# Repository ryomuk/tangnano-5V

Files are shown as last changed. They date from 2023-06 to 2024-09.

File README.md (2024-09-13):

# tangnano-5V
5V tolerant interface for Tang Nano 20K and 9K

This document is written mostly in Japanese. If necessary, please use a translation service such as DeepL (I recommend this) or Google.

# 概要
Tang Nanoを5V系の回路に接続するためのインターフェースです．昔のCPU用のメモリシステムやI/OをTang Nanoに実装することを主目的に作成しました。
Tang Nano 20K用と9K用の2種類があります．(私は主に20K用を使用しており，9K用はクセがあるのであまり使用実績が無いです．)

# Tang Nano 20K 版(rev.1.1a)
## 機能
- Tang Nanoの20KのGPIO(全34本)を，SN74CB3T3245(レベルシフタ搭載バススイッチ)を介して5V系(TTL, CMOS)に接続します．
- バッファではなくスイッチで行なっているため，特に信号方向を意識することなく双方向接続が可能，信号の伝達遅延は0.25ns以下です．

## 原理
- 5V→3.3VはSN74CB3T3245によって5V系から3.3V系にレベル変換されます．
- 3.3V→5Vはレベル変換は行なわれず，3.3V系の信号が出力されますが，5VTTLの閾値は1.5V，5VCMOSの閾値は2.5Vなので問題無いということのようです．

## 動作の確認状況
- 27MHzのシステムクロックが全GPIOで5V系に出力できることを確認しました．(75番ピンについては下記参照)
- 5V系→3.3V系: 5Vの入力信号に対し，出力が3.3Vになることを確認しました．
- 3.3V系→5V系: 3.3Vの入力信号に対し，出力が3.3Vになることを確認しました．
- データシートによると遅延はmax 0.25nsで，手元のオシロでは測定限界以下でした．

## Tang Nano 20Kの75番ピンについて
- Tang Nano 20K(v3921)の75番ピンは，C51(100nF)でGNDに接続されているため，そのままだと低速(数十KHz)でしか動作しません．他のピンと同様に使用するためにはC51を外す必要があります．低速動作で構わないのであれば気にしなくていいです．
- 最新の回路図v3921(Date:2023-07-11, ファイルの日付2023-11-08)ではC51がNCになっているようです。2024年3月に購入したものがC51未実装だったという情報がありました。(2024/4/15)
- R22(10K)でGNDにプルダウンされているので、外部でプルアップすると誤動作の原因になります。

### 75番ピン以外に関するメモ
TangNano20K、pin75以外にも若干癖のあるpinがあるのでメモしておきます。
- pin15～20は510RでLEDに継がっていて入力に使うとIIL=約3.0mA。
- pin52～53は2.2Kで5VとFETに継がっててIIL=約4.4mA。
- pin26は5.1KでGND、IIH=0.6mA。
- その他のほとんどのピンはだいたいIIL=0.9mA程度、IIH=0.1mA以下。

## BOM
|Reference |Qty| Value |Size |Memo |
|---|---|---|-----|-----|
|C1, C2, C3, C4, C5 |5	|0.1uF	 |1608(mm)(0603(inch))| |
|J1, J2	 |2	|pin socket |1x20 |for Tang Nano 20K|
|J3, J4 |2	|pin header |1x20 |for 5V GPIO|
|U1, U2, U3, U4, U5 |5	|SN74CB3T3245PW  |TSSOP| |

## 画像
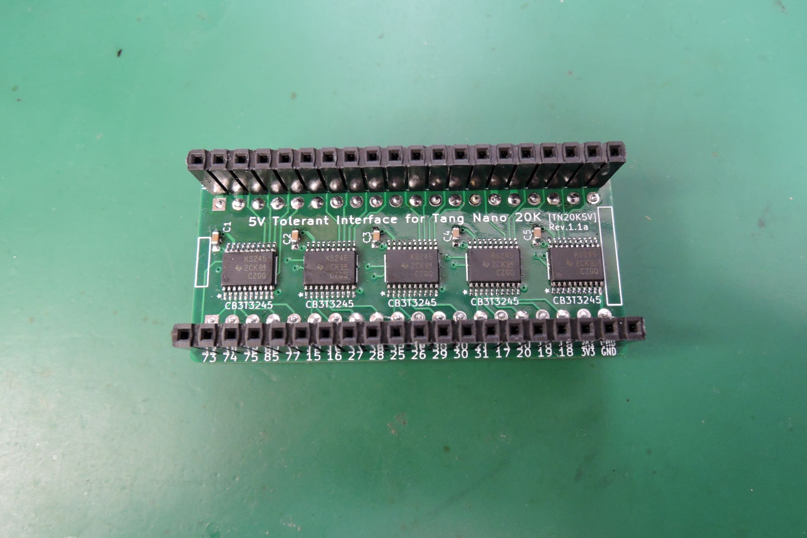
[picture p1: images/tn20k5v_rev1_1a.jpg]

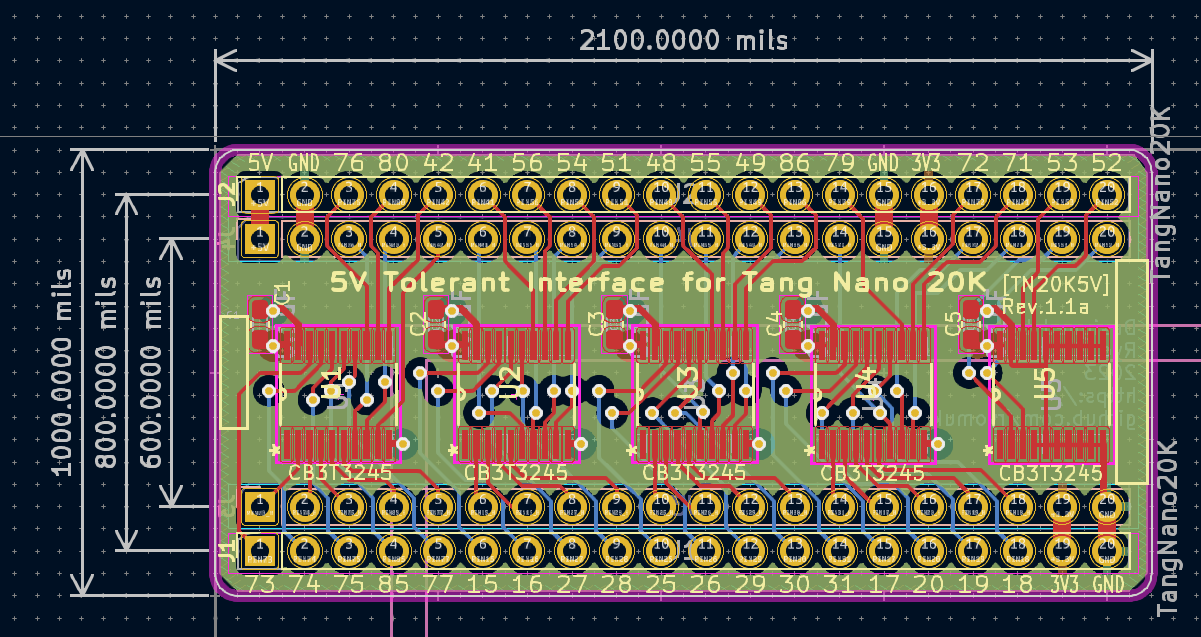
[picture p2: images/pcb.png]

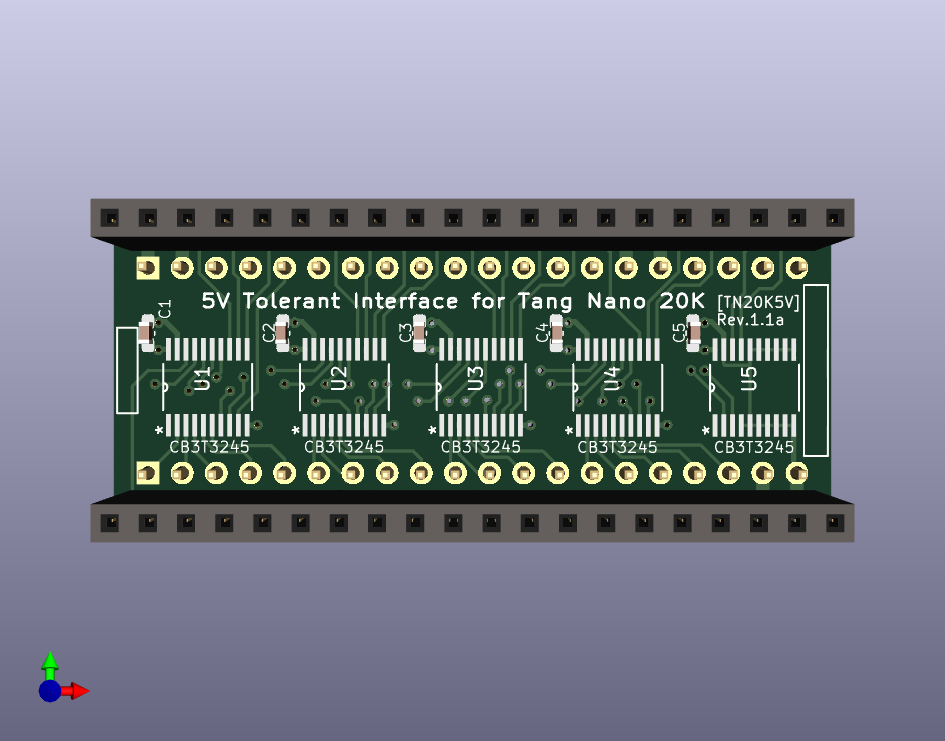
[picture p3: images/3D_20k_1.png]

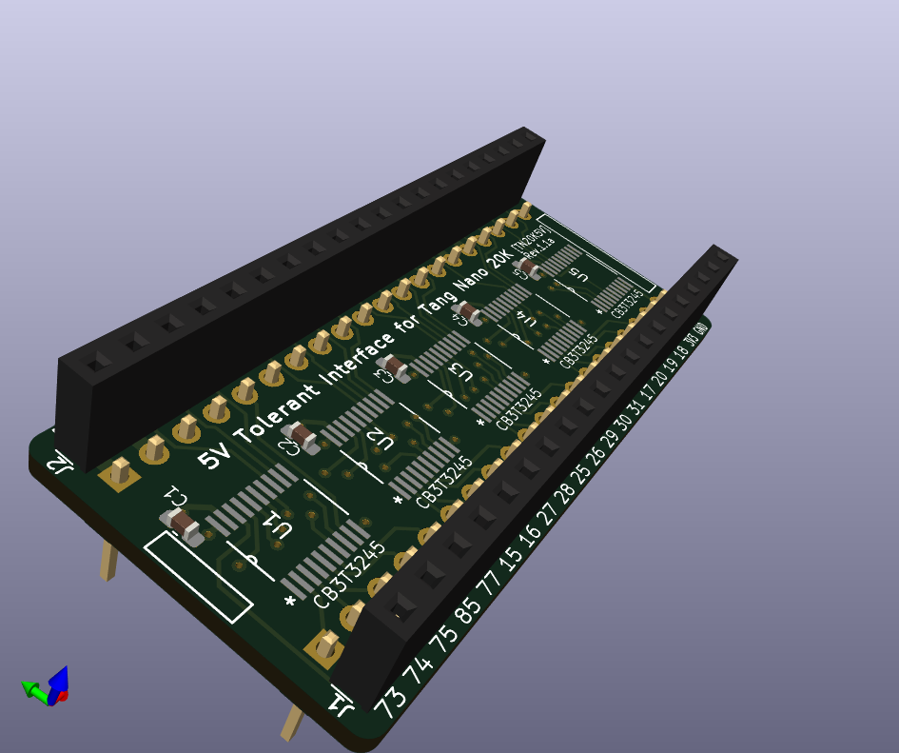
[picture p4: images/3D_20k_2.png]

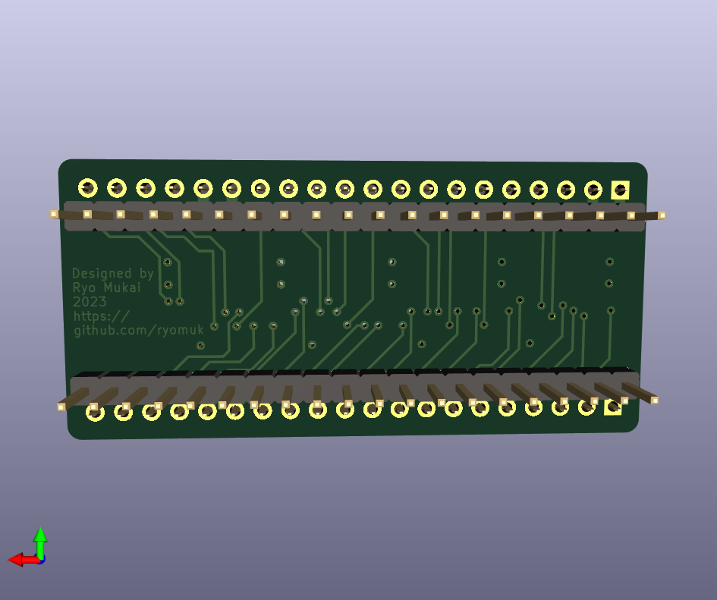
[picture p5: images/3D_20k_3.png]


# 応用例
- いろいろなCPUのメモリシステム，UARTを構築した応用例です．CPUをFPGAでエミュレートするのではなく、本物のCPUを動かすことを目的にしています。
- 勉強のために作った習作なのでかなり荒削りでいろいろと不備やバグがあると思いますがご容赦下さい。
- 各CPUで共通に使用しているUARTモジュールは適当に作ったために時々不具合が見つかってバグ修正しています．旧版との互換性は確認していないので，CPUによっては旧版のままになっています．最新版は別フォルダ [applications/uart/](applications/uart/) に置いてありますので，必要であればコピーしてご使用下さい．
- ターミナルソフトの通信遅延はCPUの速度や通信速度にあわせて適宜設定して下さい。(例: 10ms/文字, 100ms/行)

## TangNanoZ80MEM [applications/TangNanoZ80MEM](applications/TangNanoZ80MEM)
- Z80用のメモリシステムとクロック，UARTです．
- 関連ブログ [Z80をオーバークロックしてみる](https://blog.goo.ne.jp/tk-80/e/6de3708450bac79c2c1cef7728d0c877)
  
## TangNanoZ80MEM-CPM [applications/TangNanoZ80MEM-CPM](applications/TangNanoZ80MEM-CPM)
- TangNanoZ80MEMにfloppy/hard diskエミュレータを追加してCP/Mを動作させる試みです．

## TangNano6809MEM [applications/TangNano6809MEM](applications/TangNano6809MEM)
- MC6809用のメモリシステムとクロック，UARTです．
- [電脳伝説さんのSBC6809](https://vintagechips.wordpress.com/2017/12/05/sbc6809%E3%83%AB%E3%83%BC%E3%82%BA%E3%82%AD%E3%83%83%E3%83%88/)のdatapackに入っているBASIC9がバイナリそのままで動きます．

## TangNano8070MEM [applications/TangNano8070MEM](applications/TangNano8070MEM)
- INS8070N(SC/MP III)用のメモリシステム，クロック，UARTです．
- [ElectrelicさんのUniversal Monitor](https://electrelic.com/electrelic/node/1317)が，UARTのハンドシェイク部分を微修正して動きました．

## TangNano8008MEM [applications/TangNano8008MEM](applications/TangNano8008MEM)
- Intel 8008用のメモリシステム，クロック，UARTです．
- [SCELBAL (SCELBI Basic)](https://www.willegal.net/scelbi/scelbal.html)が動きました．
- [VTL-4004](https://github.com/ryomuk/VTL4004)を8008用に書き直したVTL-8008が動きました

## TangNano8080MEM [applications/TangNano8080MEM](applications/TangNano8080MEM)
- Intel 8080用メモリシステム，クロック，UART，diskエミュレータです．
- Z80MEM-CPMと同じdiskイメージを使用してCP/Mが起動します．

## TangNanoDCJ11MEM [ryomuk/TangNanoDCJ11MEM](https://github.com/ryomuk/TangNanoDCJ11MEM)
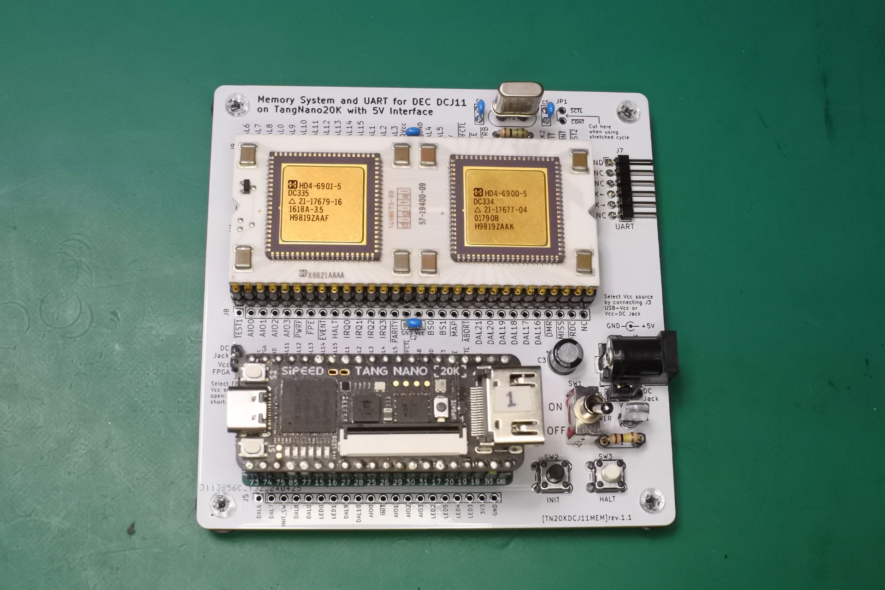
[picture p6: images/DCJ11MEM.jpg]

- DEC DCJ11 (PDP-11の命令セットを持つCPU)のメモリシステムとUARTです。
- 詳細は別リポジトリ[TangNanoDCJ11MEM](https://github.com/ryomuk/TangNanoDCJ11MEM) にあります。

# Tang Nano 9K 版(rev.3.0)[hardware/9k](hardware/9k)
- Tang Nanoの9K用のインターフェースです．あまりメンテナナスされていません．
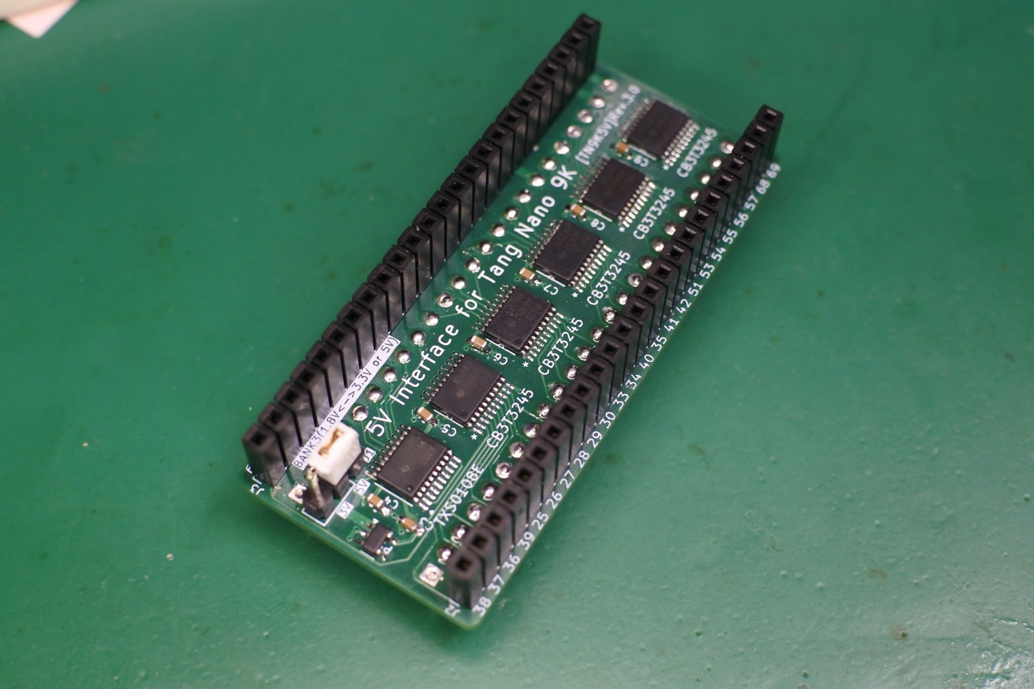
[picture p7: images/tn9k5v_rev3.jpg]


# その他
## UARTモジュールについて [applications/uart/](applications/uart/)
- 各応用例の通信部分はSipeedのサンプル( https://github.com/sipeed/TangNano-20K-example )をベースにして独自に書き替えたものを使っています．CPU速度と通信速度によっては不安定だったりすることがあり，時々書き直してます．旧版との互換性を全部確認するのは面倒なので最新版は別のフォルダに入れることにしました．

## 参考文献，データシート等
- [SN74CB3T3245 Data sheet](https://www.ti.com/lit/ds/symlink/sn74cb3t3245.pdf)
- [Application Note CBT-C, CB3T, and CB3Q Signal-Switch Families](https://www.ti.com/lit/an/scda008c/scda008c.pdf)
- [Logic Guide, Texas Instruments](https://www.ti.com/lit/sg/sdyu001ab/sdyu001ab.pdf)
- [ロジック・ガイド(日本語版), Texas Instruments](https://www.tij.co.jp/jp/lit/sg/jajt217/jajt217.pdf)
- [5V系・3.3V系信号レベル変換, cepstrum](https://www.cepstrum.co.jp/hobby/5v33v/5v33v.html)

## 更新履歴
- 2023/06/16: 初版公開 (Tang Nano 20K用 rev.1.1)
- 2023/06/25: 応用例にTangNanoZ80MEMを追加
- 2023/06/26: TangNanoZ80MEMのピン配置を変更．(rev1.0→rev.1.1)
- 2023/06/28: TangNanoZ80MEMの uart.vを更新．
- 2023/07/06: TangNanoZ80MEMを修正．27MHz(Vcc=5.0V), 33MHz(Vcc=6.0V)で動作．
- 2023/07/11: Tang Nano 20K用 rev.1.1→rev.1.1a (差分はシルクの修正のみ)
- 2023/07/11: Tang Nano 9K用 rev.2.0公開 (若干問題あり)
- 2023/07/15: README.md用の画像を1.1aにアップデート
- 2023/07/19: 応用例にTangNano6809MEMを追加
- 2023/07/20: tn20k5v rev1.1aの実物作成，動作確認OK．写真掲載．
- 2023/07/23: 応用例にTangNano8070MEMを追加．
- 2024/04/07: uart.vのバグ修正．(tx_ready関連)
- 2024/04/11: TangNano6809MEMに関する注意事項記載
- 2024/04/12: uart.vの最新版格納用のフォルダ applications/uart を作成
- 2024/04/13: applications/uart/uart.v 更新
- 2024/04/14: README修正(応用例に関するエクスキューズを追記)
- 2024/04/15: README修正(6809、R1の除去について, TangNano20Kのピンに関するメモ)
- 2024/04/17: TangNanoZ80MEM: top.v修正(writeのバグ, RGBLED, UART_CTRL)
- 2024/04/17: TangNanoZ80MEM: rom/rom.unimon339.v 追加
- 2024/04/19: TangNanoZ80MEM: rom/bin2v.pl修正, romファイルの余計な0フィルを削除
- 2024/04/21: Tang Nano 9K用 rev.3.0公開
- 2024/04/27: TangNanoZ80MEM: UARTの送信タイミング変更
- 2024/05/07: applications/uart/にuart.v.20240507 追加
- 2024/06/21: applications/uart/にuart.v.20240621 追加
- 2024/06/21: rx_clear, tx_sendのロジックについてREADMEに追記
- 2024/07/23: READMEを階層化
- 2024/07/23: TangNanoZ80MEM-CPM 公開
- 2024/08/05: TangNano8008MEM 公開
- 2024/08/18: TangNano8008MEM用のsoftwareにVTL-8008を追加
- 2024/08/28: TangNano8008MEMにPCB rev1.0を追加
- 2024/09/08: TangNano8080MEM 公開
- 2024/09/13: TangNano8080MEM 修正 (memory writeタイミング修正, 3MHz対応)

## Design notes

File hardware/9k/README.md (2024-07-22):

# Tang Nano 9K 版(rev.3.0)
## rev2.0からの差分
- rev2.0(全バンクでTXS0108Eを使用)では、Pin68～75(HDMI用ピン)への入力で異常発振したり、USB接続が出来無くなったりする問題が発生していましたが、3.3Vバンクを20K版と同じ74CB3T3245に変更したところそれらの問題が解消しました。
  
## 機能
- Tang Nanoの9KのGPIO(全45本)を5V系(TTL, CMOS)に接続します．
- 信号方向を意識することなく双方向接続が可能です．
- Pin79〜86は1.8Vのバンク(BANK3)なのでTXS0108Eを用いて，1.8V←→(5V or 3.3V)の変換をします．その他のピンはCB3T3245を用いて3.3V←5V, 3.3V→3.3Vです．

## 動作の確認状況
- 27MHzのシステムクロックが全GPIOで5V系に出力できることを確認しました．
- 入力は単体試験(1ピンづつ)では期待通りの動きをしますが，入出力混在時に怪しい挙動を示しました．

### 見つかった問題点
- (pin63 & pin86) をそれ以外の全ピンに出力するというテストで出力がおかしくなることがある．おそらくBANK3(1.8V系)がなんらかの干渉をしている．
- pin68〜75は入出力とも若干歪む．

### 問題点を回避するためのガイドライン
- BANK3(1.8V系)は出力専用にする．
- HDMI用のピンは歪むので動作を確認しながら使う．

## BOM
|Reference |Qty| Value |Size |Memo |
|---|---|---|-----|-----|
|C3,C4,C5,C6,C7,C8,C9 |7  |0.1uF	 |1608(mm)(0603(inch))|C1,C2は無し |
|J1 |1  |pin header |1x3 |BANK3 HI側の電圧選択用|
|J2,J3 |2  |pin socket |1x24 |for TangNano9K|
|J4,J5 |2  |pin header |1x24 |for 5V GPIO|
|PS1 |1  |TLV71318 |SOT23-5| 1.8Vレギュレータ|
|U1 |1  |TXS0108EPW |TSSOP| |
|U2,U3,U4,U5,U6 |5  |SN74CB3T3245PW  |TSSOP| |

- C1,C2は.1.8Vレギュレータ用でしたが不要なので消した後にアノテーションし直すのを忘れて欠番になっています．

## 画像


## 応用例
## TangNanoZ80MEM_9K [applications/9K/TangNanoZ80MEM_9K](../../applications/9K/TangNanoZ80MEM_9K)
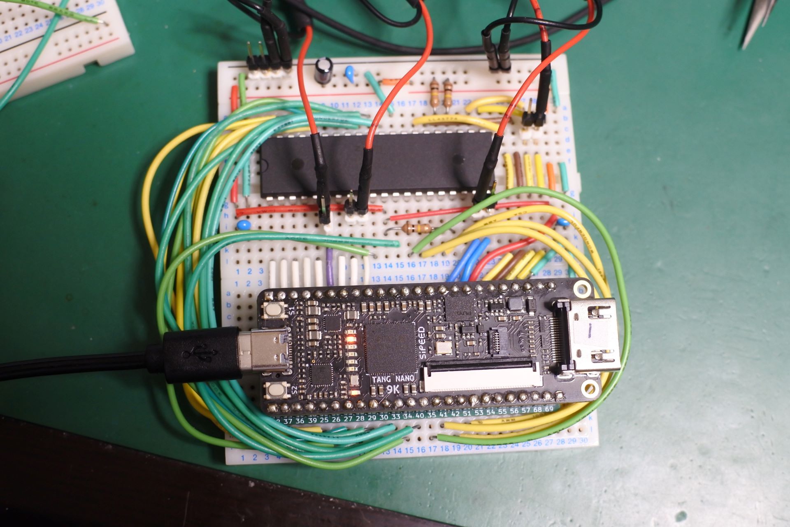
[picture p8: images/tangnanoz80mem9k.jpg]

- 9K用インターフェースの動作確認用にブレッドボードで組んでみました．
- ~~とりあえず4.5MHzならたいていのピン配置で動きました．今のところ13.5MHzが限界．20K版ほど高速には動作しませんでした．~~
- ~~HDMIのコンデンサを外したら余計に動作しなくなったり，ピンアサインを変えるだけで動作しなくなったりするのでどこかにタイミング的な問題がありそうです．~~
- ~~MREQ_nはHDMIピンに継げた方が安定するので，MREQ_nでアドレスをラッチしているあたりが怪しそう．~~
- メモリライトのタイミングをWR_nではなくCLKでトリガーするようにしたら27MHzでも動くようになりました。ただし、HDMI端子のコンデンサ除去必須です。

## 更新履歴
- 2023/7/11: Tang Nano 9K用 rev.2.0公開 (若干問題あり)
- 2024/4/21: Tang Nano 9K用 rev.3.0公開

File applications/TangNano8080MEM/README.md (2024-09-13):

# TangNano8080MEM
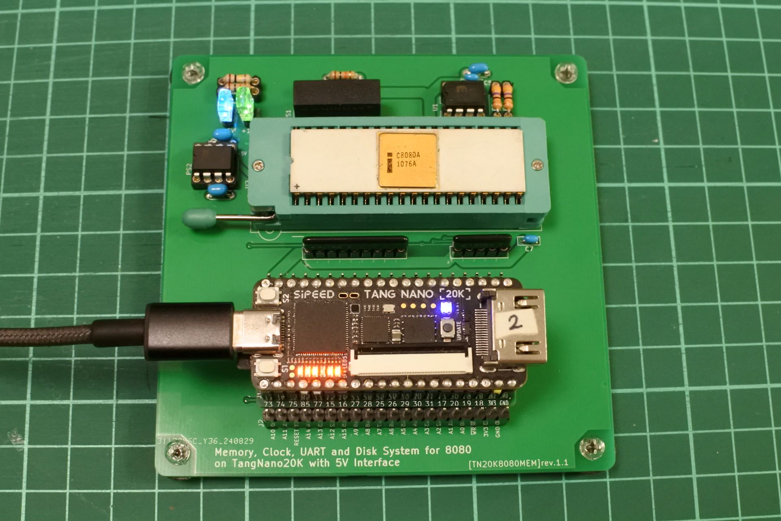
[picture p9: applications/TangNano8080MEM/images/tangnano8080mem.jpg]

## 概要
- Intel 8080用のメモリシステム，クロック，UART，diskエミュレータです．
- Universal Monitor や CP/Mが動きます．

## PCB rev.1.1
- 回路図，ガーバーファイル等は[hardware/rev.1.1](hardware/rev.1.1/)にあります．
### BOM
|Reference |Qty| Value |Memo |
|---|---|---|-----|
|C1 |1  |2.2uF | |
|C2,C6 |2  |1uF | |
|C3,C4 |2  |10uF | |
|C5,C7,C8 |3  |0.1uF | |
|D1,D2 |2  | LED |任意 |
|J1 |1  | DIP-40 Socket or 20x1 Pin frame x2  |TangNano5V用|
|J2,J3 |2  |Conn_01x20 |任意(観測用)|
|PS1 |1  |MAU104 |5V→12V用DCDC,  https://akizukidenshi.com/catalog/g/g104132/ |
|PS2 |1  |TJ7660 |5V→-5V用, https://akizukidenshi.com/catalog/g/g112017/|
|R1 |1  | 10k | |
|R2,R3 |2  | 1k〜100k(適宜) | 値はLEDにあわせて任意|
|R4,R5 |2  | 47 | クロック用ダンピング抵抗|
|RN1 |1  | 4.7k x8 |データバスプルアップ |
|RN2 |1  | 100k x4 |制御信号プルアップ |
|U1 |1  | MIC4427 |  クロックドライバ|
|U2 |1  | 40pin ZIFソケット |  8080用|

- RN2は当初10KΩにしていたのですが，TangNano20Kのpin75はB616_BOOTに継がっていて，起動時にUSBを検出してくれなくなってしまうので100kΩに変更しました．[TangNano6809MEM](../TangNano6809MEM)で起きていたのと同様の問題でした．

## FPGAに実装したもの
- [TangNanoZ80MEM-CPM](../TangNanoZ80MEM-CPM/)をベースにして，2相クロック，8228相当の制御信号の変換を追加しました．

## クロックの設定
top.v で下記の1つを選択して下さい．
```
// select one of the following CLK frequency
//`define  CLK_3MHz     // 3.0MHz(333ns)
`define  CLK_2MHz   // 2.077MHz( 481ns)
//`define  CLK_1MHz   // 1.038MHz( 963ns)
//`define  CLK_500kHz // 519.2KHz(1930ns)
```

## ROMの選択
- top.v で下記の1つを選択して下さい．
```
// select one of the following 2 applications
`define USE_CPM
//`define USE_UNIMON

```
このオプションで，rom.vでincludeするファイル，UART用レジスタのビットフィールドを切り替えています．

## CP/Mの起動方法
- [TangNanoZ80-CPM](../TangNanoZ80MEM-CPM/)と同じ手順で作成したdiskイメージで起動できます．

## 動作確認状況
- 下記CPUで動作CP/Mが起動し，BASICでASCIIART.BASが完走しました．

#### Intel C8080A
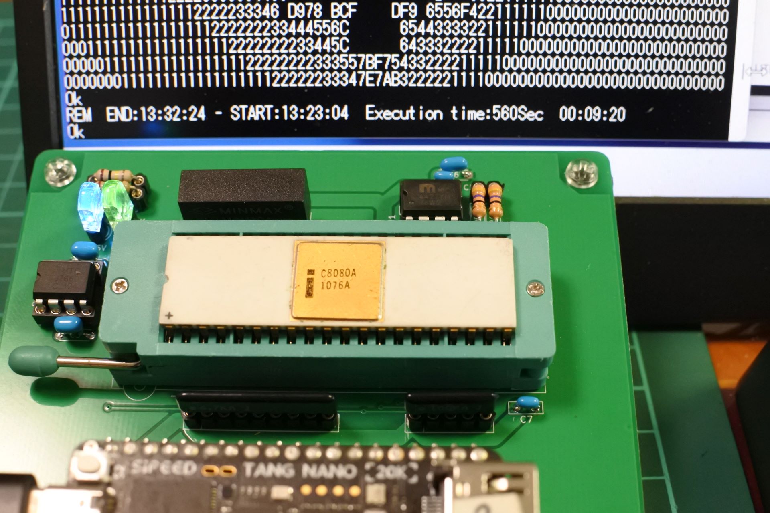
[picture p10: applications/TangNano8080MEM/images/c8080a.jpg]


#### Intel P8080A-1 (3MHz)
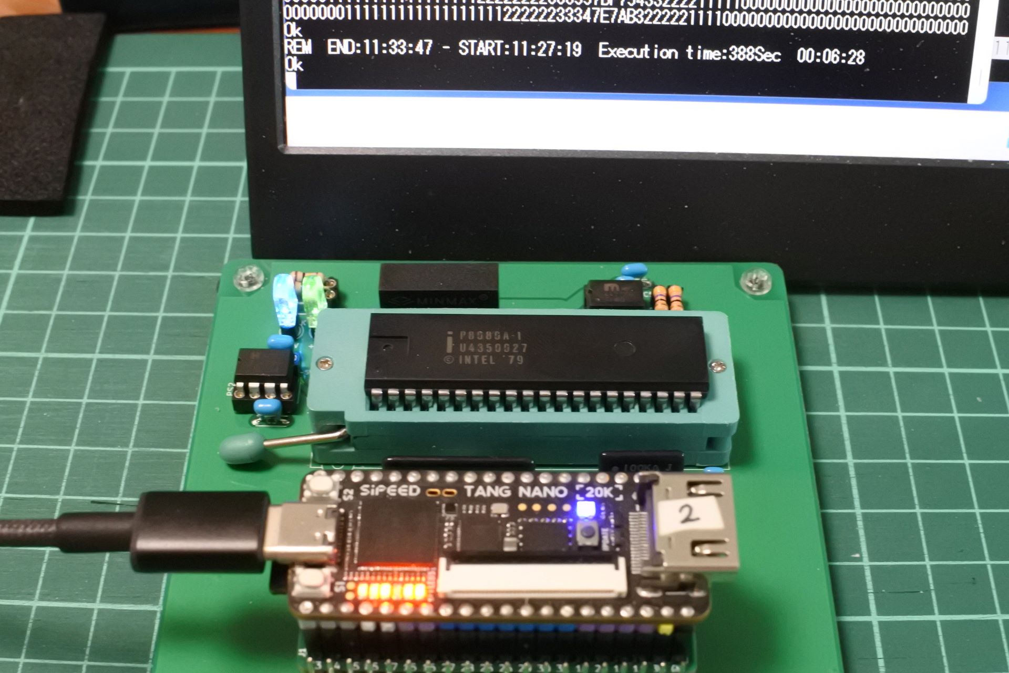
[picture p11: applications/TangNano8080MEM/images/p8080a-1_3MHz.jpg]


#### NEC uPD8080A
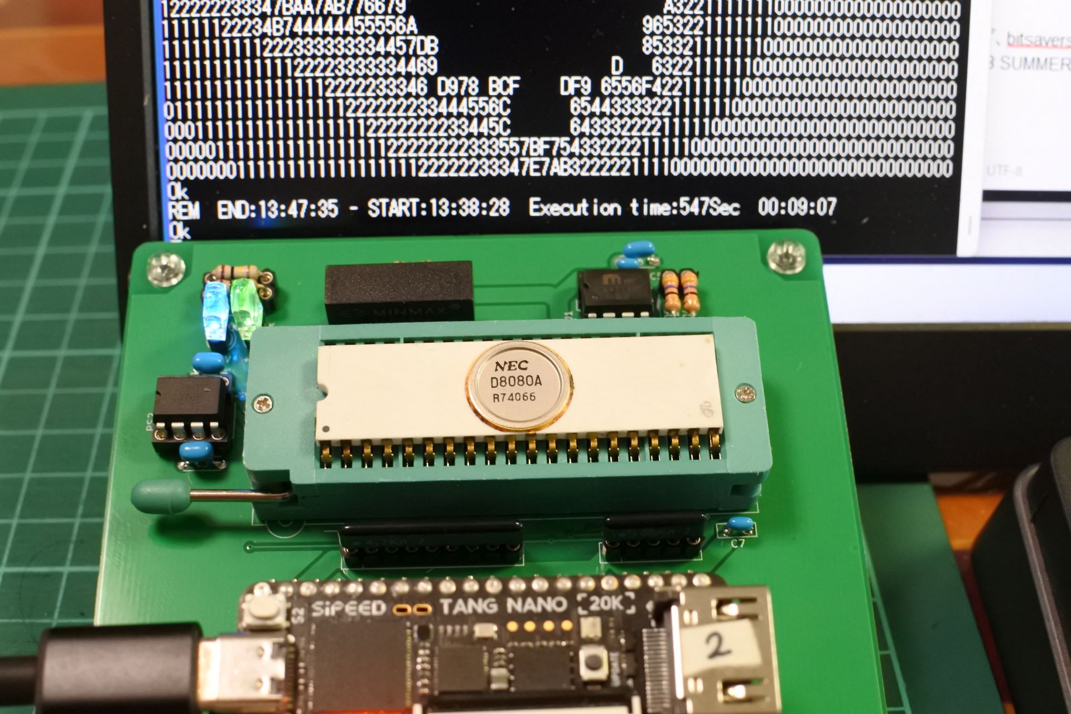
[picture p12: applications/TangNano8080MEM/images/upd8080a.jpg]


#### NEC uPD8080AF
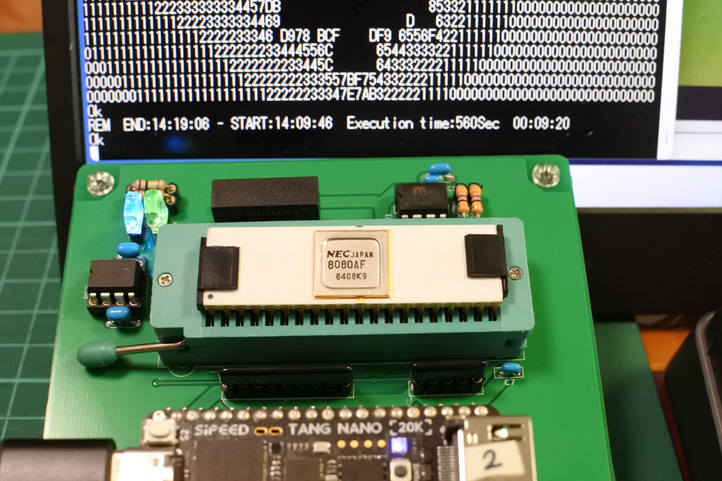
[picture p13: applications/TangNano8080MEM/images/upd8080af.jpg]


#### NEC uPD8080AFC-1 (3MHz)
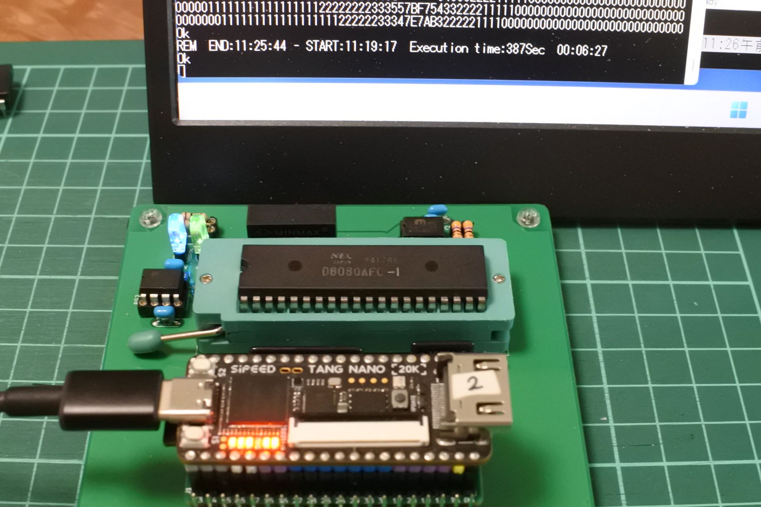
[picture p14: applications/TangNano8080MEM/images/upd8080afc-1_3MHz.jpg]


#### NEC uPD753(+変換基板)
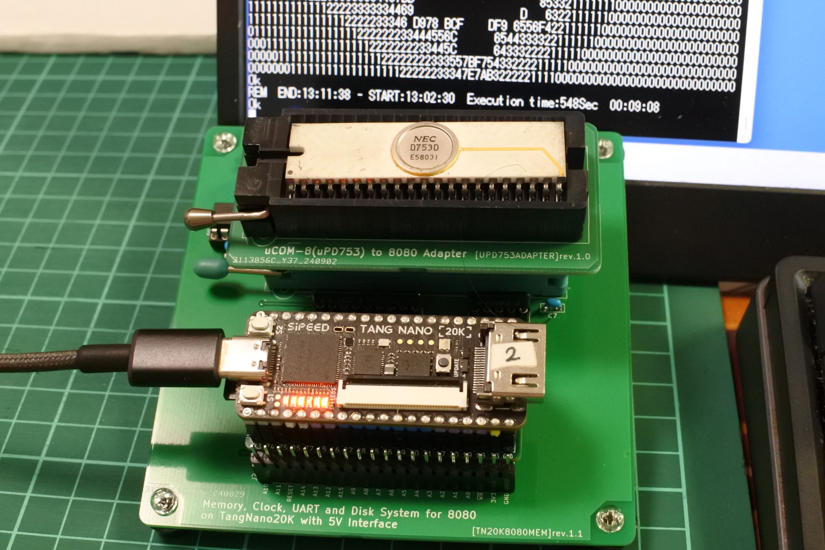
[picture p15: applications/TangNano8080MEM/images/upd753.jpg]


#### 三菱M58710S(8080A)
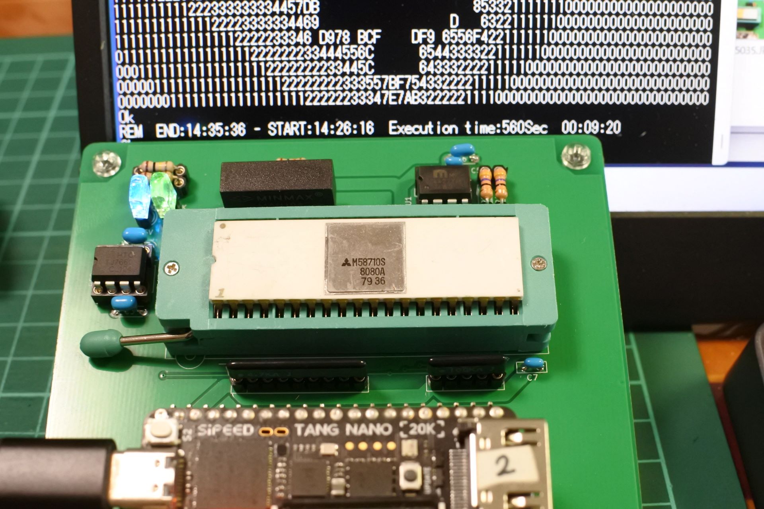
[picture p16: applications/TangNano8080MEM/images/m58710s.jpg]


#### AMD AM9080ADC(C8080A)
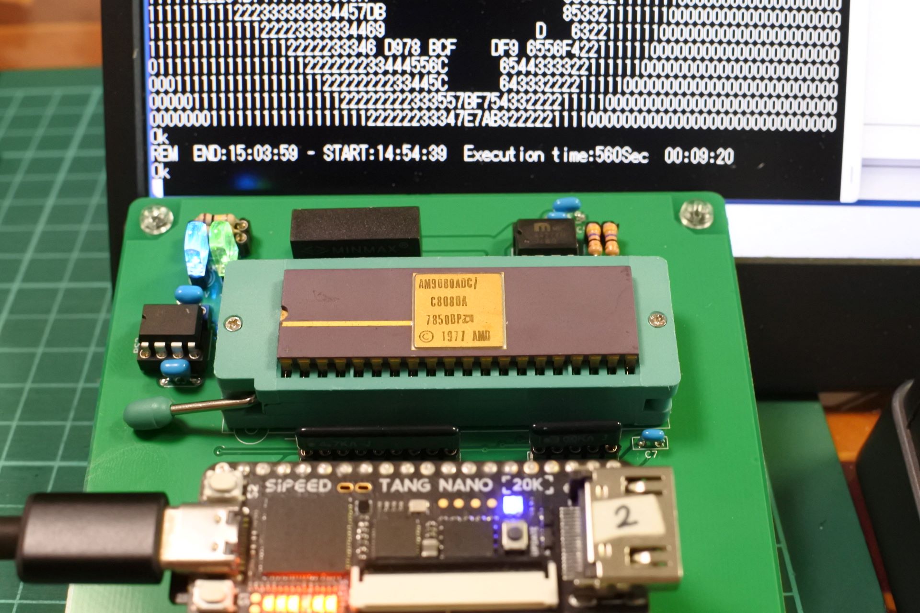
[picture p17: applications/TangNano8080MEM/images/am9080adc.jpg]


#### AMD AM9080ADCB
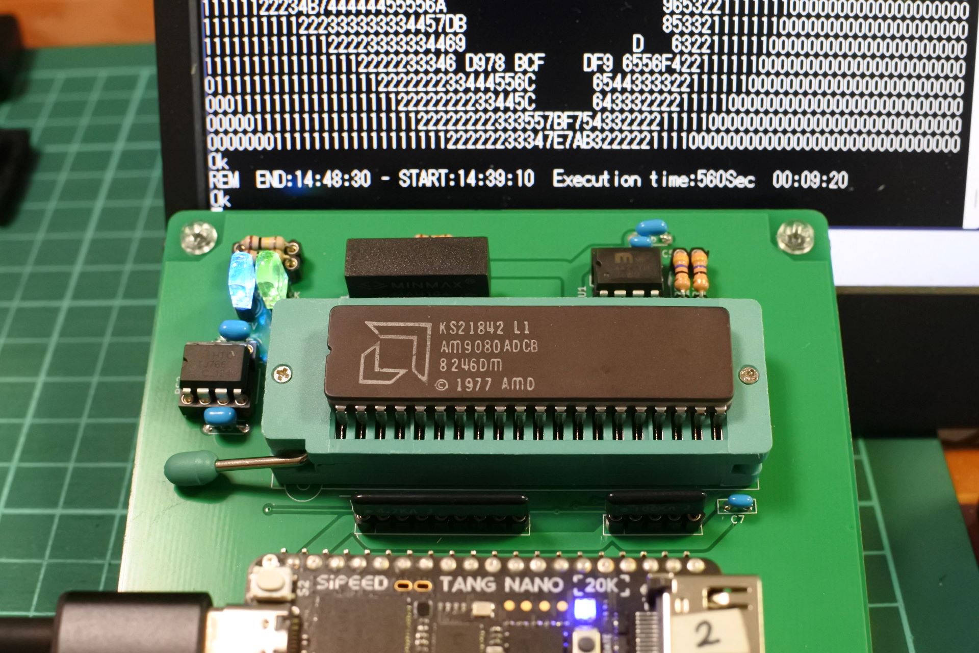
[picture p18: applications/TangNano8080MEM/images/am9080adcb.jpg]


#### NS INS8080AN
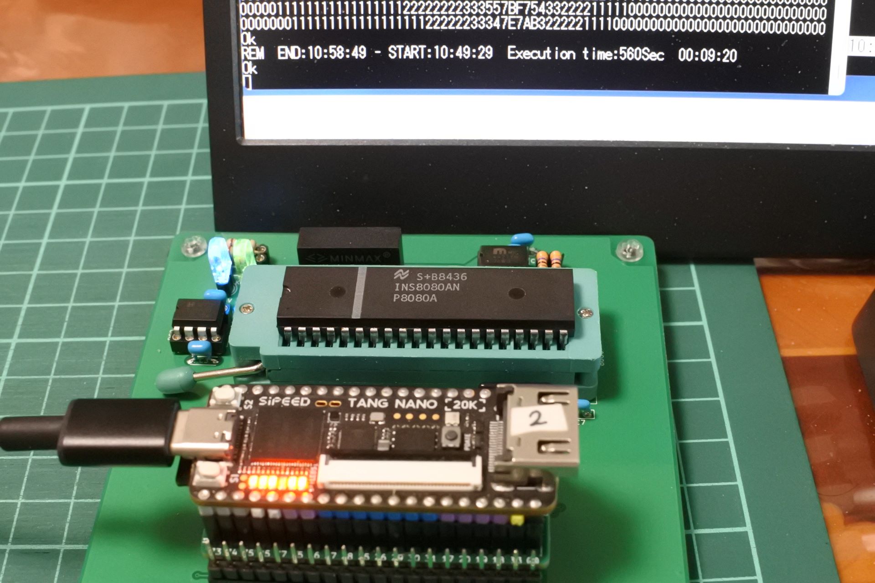
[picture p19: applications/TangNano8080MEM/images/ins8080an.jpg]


#### TI TMS8080ANL
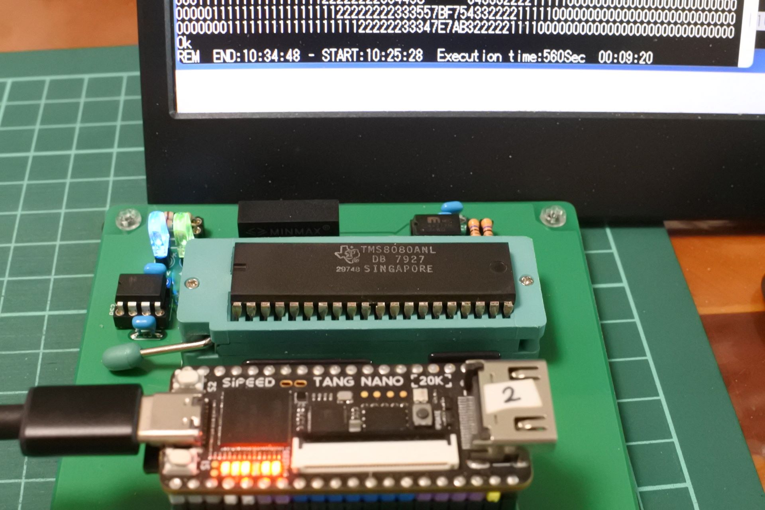
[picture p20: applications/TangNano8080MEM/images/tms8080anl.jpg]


## 既知の問題
- ~~下記CPUで動作しないので原因調査中です．~~
  - ~~NS INS8080AN, TI TMS8080ANL~~
  - メモリ書き込みのタイミングを修正して解決しました．

## 参考にした先行事例，関連サイト等
- [satoshiokue/MEZ8080](https://github.com/satoshiokue/MEZ8080)
- [satoshiokue/EMUZ80-8080](https://github.com/satoshiokue/EMUZ80-8080)
- [Gazelle8087/EMUZ80-8080G](https://github.com/Gazelle8087/EMUZ80-8080G)
- [電脳伝説/SBC8080](https://vintagechips.wordpress.com/2018/06/24/sbc8080-cpu%E3%83%AB%E3%83%BC%E3%82%BA%E3%82%AD%E3%83%83%E3%83%88/)
- [Electrelic/Universal Monitor](https://electrelic.com/electrelic/node/1317)

## 更新履歴
- 2024/09/08: 初版公開
- 2024/09/13: メモリライトタイミング修正，3MHz対応

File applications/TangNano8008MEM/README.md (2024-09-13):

# TangNano8008MEM
## 概要
- Intel 8008用のメモリシステム，クロック，UARTです．

## PCB rev.1.0
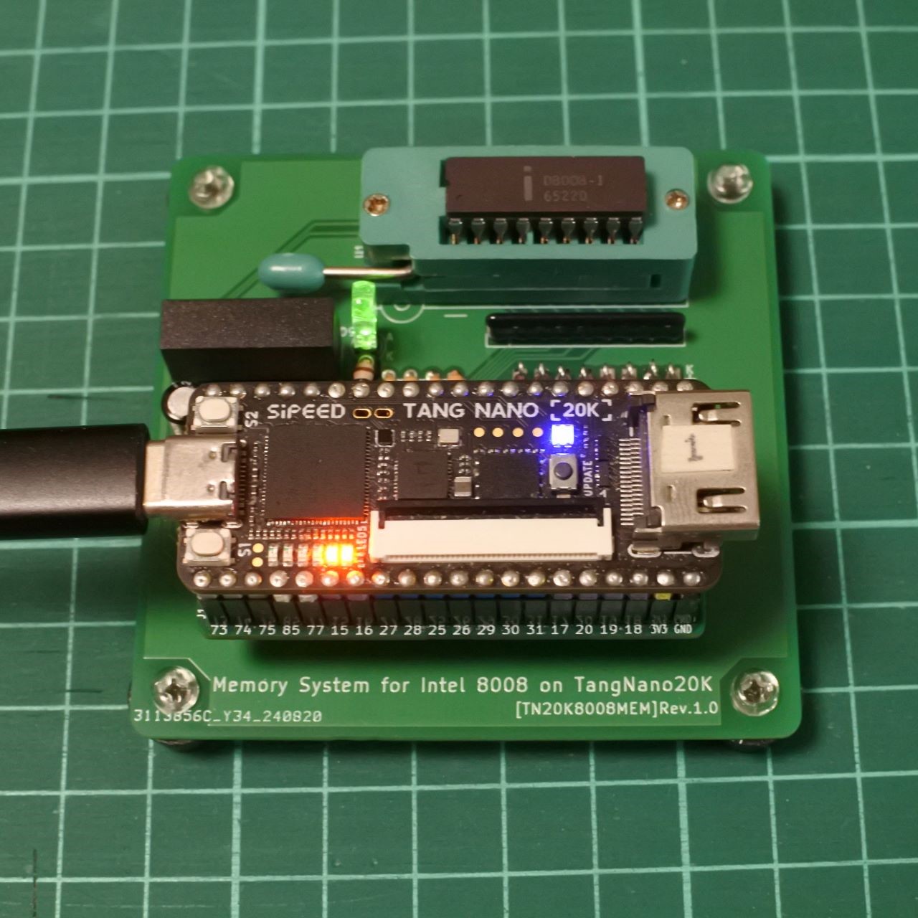
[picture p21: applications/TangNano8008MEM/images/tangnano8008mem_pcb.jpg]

- 回路図やガーバーファイルは[hardware/rev.1.0](hardware/rev.1.0/)にあります．
- users manualには入出力はTTLレベルと書いてありますが，波形を観測したところ8008の出力はマイナス電位にもなるようでした．
  - バス(D0〜7)には外付けでクランプダイオードを回路に入れていますが，SN74CB3T3245にはクランプダイオードが内蔵されているので無くても動きます．
  - SYNC, S0〜2は1KΩの抵抗だけ入れてSN74CB3T3245内蔵のクランプダイオードに任せています．
### BOM
|Reference |Qty| Value |Memo |
|---|---|---|-----|
|C1 |1  |2.2uF | |
|C2 |1  |1uF | |
|D1-D8 |8  |1N4148 | |
|D9 |1  | LED |任意 |
|J1 |1  | DIP-40 Socket or 20x1 Pin frame x2  |TangNano5V用|
|PS1 |1  |MAU103 |5V→9V用DCDC,  https://akizukidenshi.com/catalog/g/g112176/ |
|R1-R5 |5  | 1k | |
|R6 |1  | 100k(適宜) | 値はLEDにあわせて任意|
|RN1, RN3 |2  | 4.7k x8 | |
|RN2 |1  | 1k x4 | |
|U1 |1  | 18pin ZIFソケット |  intel8008用|

## FPGAに実装したもの
- プロジェクトは[TangNano8008MEM_project](TangNano8008MEM_project)です．
- 16KBメモリ (8008のアドレス空間は14bitなのでフル実装です．)
- UART(TXバッファ付き)
- 割り込み機能
- 8008にはRESETが無いので，下記でRESET相当のことを実装しました．
  - SW1: バスにHALTを出力してSTOPさせ，INTERRUPT信号をアサートし，バスにRST0命令を挿入．(power-up時も同様)
  - SW2: INTERRUPT信号をアサートし，バスにRST0命令を挿入

## ソフトウェアについて
### VTL-8008 ([software/VTL8008](software/VTL8008))
- 以前，4004用に書いた[VTL-4004](https://github.com/ryomuk/VTL4004)を8008用に書き直してみました．仕様はVTL-4004 ver2.0と同じです．面倒なので行の編集機能が実装していません．

### echo back test ([software/echo](software/echo))
- UARTの入出力テスト用プログラムです．
- polling版と割り込み版はecho.asmの下記2行と，top.vのdefineで切り替えます．
```
echo.asm
;;; uncomment this for polling
;;  	CAL GETCH
;;  	CAL PUTCH

top.v
//`define USE_RX_INTERRUPT
```

### SCELBAL (SCELBI Basic) ([software/sc1](software/sc1))
- Twitterで[SCELBAL (SCELBI Basic)](https://www.willegal.net/scelbi/scelbal.html)なるものが存在することを教えてもらったので試してみることにしました．

#### SCELBI Basicのバイナリ作成方法等
- [ASL(The Macroassembler AS)](http://john.ccac.rwth-aachen.de:8000/as/), Perlをインストールして下さい．私はWindowsのCygwin環境で使っています．
- ASLで，radix 8とすれば良いようだったのですが，その場合に10進数をどう表記するかわからなかったので，radixは10のままで8進数にQを付けるスクリプトを書いて対処しました．その他の修正も全部スクリプト(conv.pl)で実施するようにしました．
- どうやら文字コードの8bit目が1のようで，コンソールの入出力は入出力ルーチンで対処すれば簡単だったのですが，アセンブラのプログラムの方も
```
DB "FOR"
```
を
```
DB 'F'+80H
DB 'O'+80H
DB 'R'+80H
```
のように展開する必要があるようなので変換しました．
- I/Oルーチン(CINP, CPRINT)を書く必要があったので user.asm に書きました．
  - 文字コードの8bit目が1であることへの対応．
  - どうやらCINPではecho処理も行う必要があるようでした．
- バイナリ作成手順は下記の通り．
```
cd TangNano8008MEM/software/sc1
wget https://www.willegal.net/scelbi/software/sc1.asm
cp sc1.asm sc1.asm.org
./conv.pl < sc1.asm.org > sc1.asm
make
./bin2v sc1.bin > rom.v
```
- Faster SCELBAL (2012) [sc1fast.asm](https://www.willegal.net/scelbi/software/sc1fast.asm) もconv.plで変換できました．
  - diffをとってみたらsc1.asmとの差分はほとんどありませんでした．
  - 構文解析処理を工夫して高速化しているようです．
  - mandelbrot.asmは10%ほど速くなりました．浮動小数点演算が支配項なので効果は限定的でした．

#### 実行サンプル
- お約束のASCIIART.BASを実行してみました．FOR文からGOTOで抜けるとエラーになるので微修正しました．
- 計測マクロがうまく動かず，正確な時間は測定できなかったのですが，クロッ
ク500kHzで約6時間40分で完走しました．
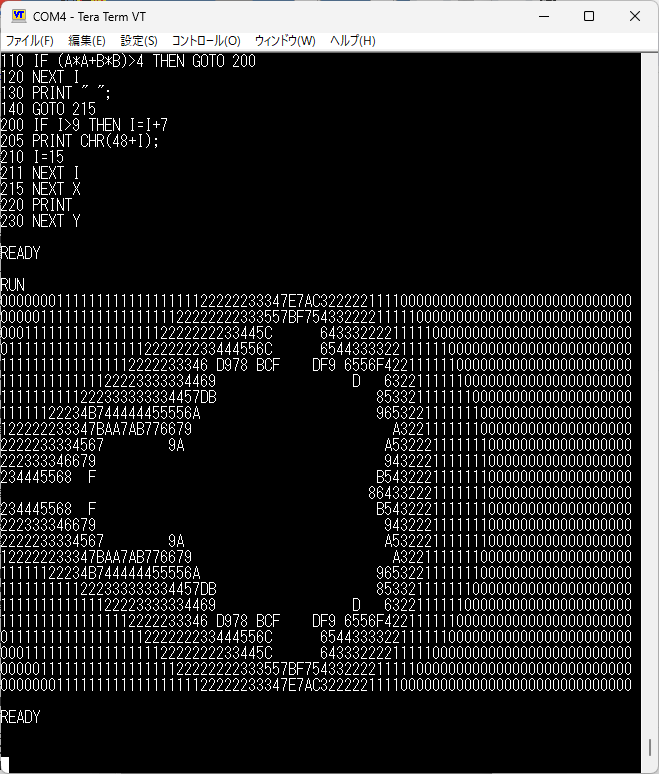
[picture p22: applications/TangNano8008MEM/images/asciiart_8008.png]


## ブレッドボード版
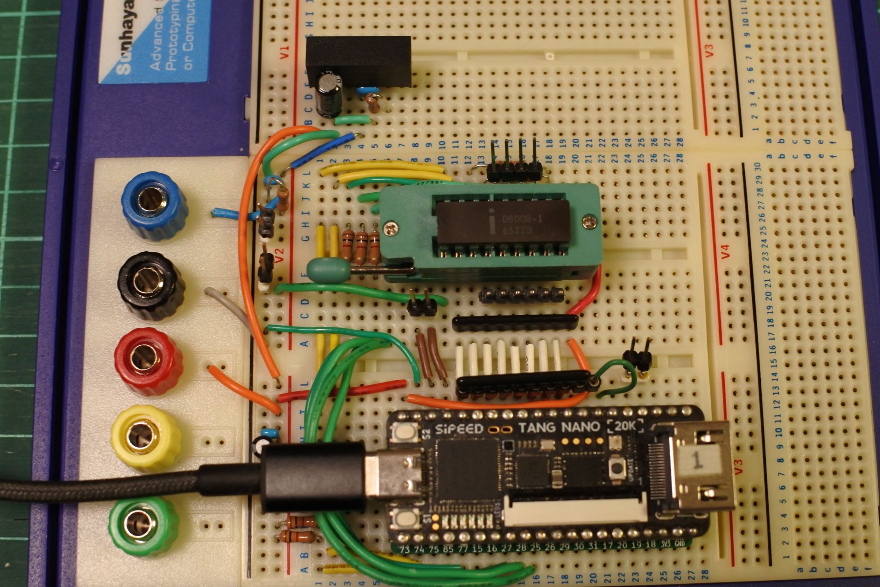
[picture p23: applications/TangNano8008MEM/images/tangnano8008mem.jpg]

- 配線量が少なく，クロックも低速なのでブレッドボードで簡単に作れました．
 - ~~あまりに簡単に作れたので，基板を作るモチベーションが湧きません．~~
 - ブレッドボードを再利用するために基板を作りました．

## 関連情報
- [bitsavers /intel/MCS8](http://www.bitsavers.org/components/intel/MCS8/)
- [www.mars.dti.ne.jp/~mark08](http://www.mars.dti.ne.jp/~mark08/index.html) 8008に関する日本語の参考資料について網羅されています．
- [SCELBAL (SCELBI Basic)](https://www.willegal.net/scelbi/scelbal.html)
- [github.com/jim11662418/8008-SBC](https://github.com/jim11662418/8008-SBC)
- [The Macroassembler AS](http://john.ccac.rwth-aachen.de:8000/as/)

## 更新履歴
- 2024/08/05: 初版公開
- 2024/08/18: VTL-8008を追加
- 2024/08/28: KiCADファイルrev1.0をブレッドボード用からプリント基板用に変更

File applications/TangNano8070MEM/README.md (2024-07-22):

# TangNano8070MEM
- INS8070N(SC/MP III)のメモリシステム，クロック，UARTです．
- [ElectrelicさんのUniversal Monitor](https://electrelic.com/electrelic/node/1317)が，UARTのハンドシェイク部分を微修正して動きました．

ブレッドボード版
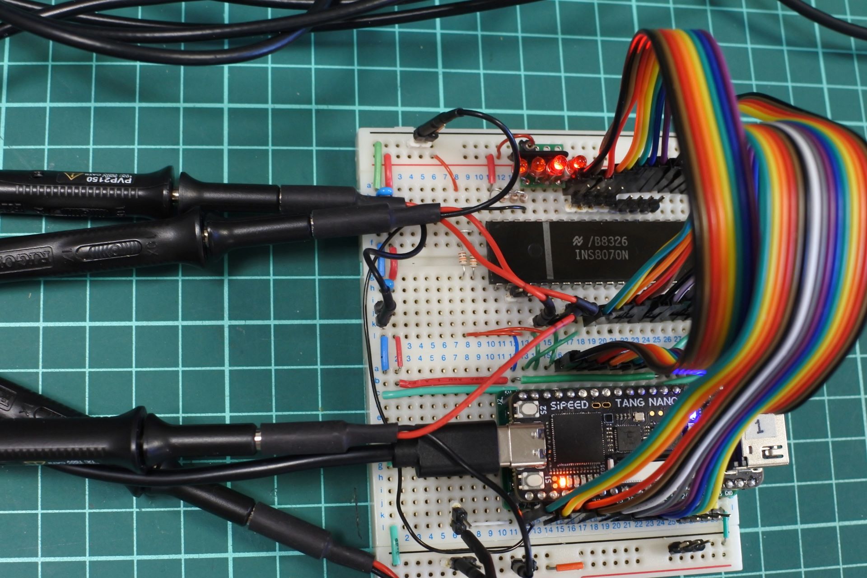
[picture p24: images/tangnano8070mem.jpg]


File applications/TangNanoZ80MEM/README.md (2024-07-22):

# TangNanoZ80MEM
- Z80用のメモリシステムとクロック，UARTです．
- クロックはTTLレベルではなくHでVcc-0.6Vのレベルが必要なので外付けのICで引き上げています．4MHz程度であれば330Ωプルアップ抵抗だけでも動きました．
- Z84C0020，ブレッドボードで20.25MHzで動作しました．
- Z80のVccをTangNano側のVCC(USB給電)と別にしたいこともあるかもしれないので，ピンヘッダで接続するようにしています．
- DBG_TRGとLED_RGBはデバッグ用の信号です．
- 75番ピンはRESET_nに割り当てたのでC51を外さなくても動作します．
- PCB版で27MHz(USB給電，Vcc=4.94V), 33MHz(Z80はTangNanoと別給電, Vcc=6.0V)で動作しました．(2023/7/6)
- uart.vにバグがあったので修正しました．(2024/4/7)
- top.vのデフォルトのクロック周波数を13.5MHzにしました．(2024/4/7)
- uart.vをリファクタリングしました．(2024/4/13)
- top.v: write_memoryのエッジの正負が間違っていたので修正しました．(2024/4/17)
- top.v: RGBLEDで点滅とUARTの状態表示をするようにしました．(2024/4/17)
- top.v: UART_CTRLのrx_data_readyの位置をbit1から0に変更しました．(2024/4/17)
- rom/rom.unimon339.v を同梱しました．ライセンスはファイル参照．(2024/4/17)
- top.v: tx_send関連のタイミングを修正しました．(2024/4/27)

## 関連ブログ
- [Z80をオーバークロックしてみる](https://blog.goo.ne.jp/tk-80/e/6de3708450bac79c2c1cef7728d0c877)
  
ASCIIART.BAS実行結果 (33MHz, Vcc=6.0V)
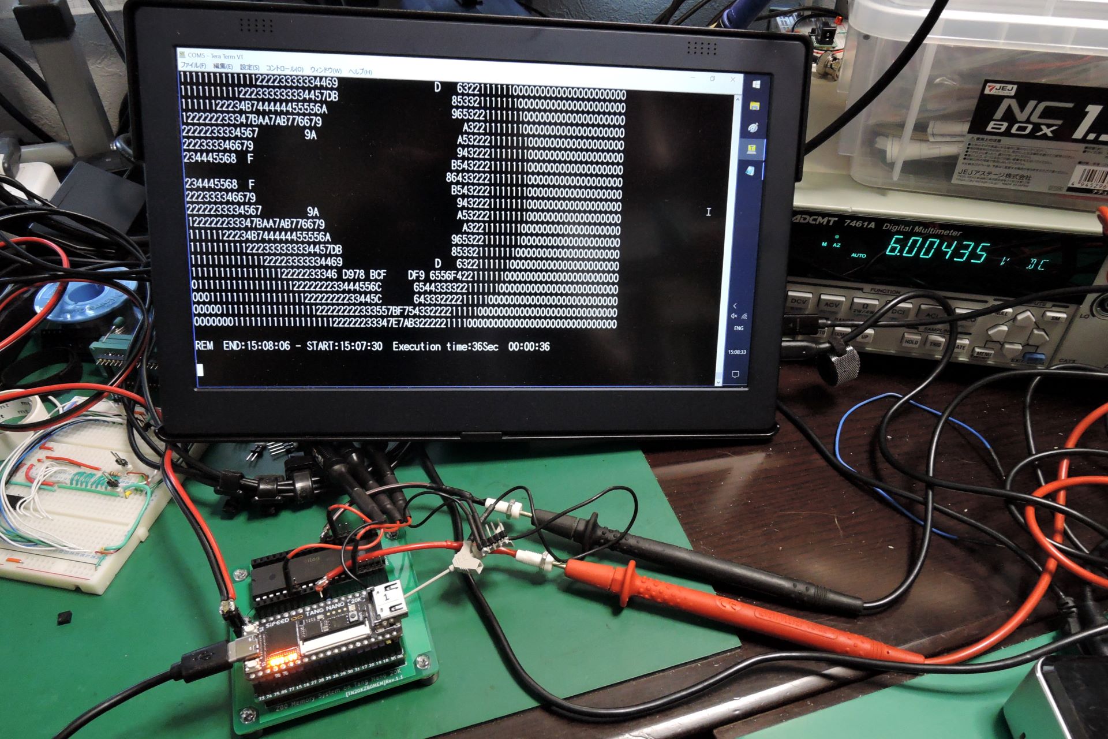
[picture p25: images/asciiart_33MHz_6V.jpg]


## 更新履歴
- 2023/06/25: 応用例にTangNanoZ80MEMを追加
- 2023/06/26: TangNanoZ80MEMのピン配置を変更．(rev1.0→rev.1.1)
- 2023/06/28: TangNanoZ80MEMの uart.vを更新．
- 2023/07/06: TangNanoZ80MEMを修正．27MHz(Vcc=5.0V), 33MHz(Vcc=6.0V)で動作．
- 2024/04/17: TangNanoZ80MEM: top.v修正(writeのバグ, RGBLED, UART_CTRL)
- 2024/04/17: TangNanoZ80MEM: rom/rom.unimon339.v 追加
- 2024/04/19: TangNanoZ80MEM: rom/bin2v.pl修正, romファイルの余計な0フィルを削除
- 2024/04/27: TangNanoZ80MEM: UARTの送信タイミング変更

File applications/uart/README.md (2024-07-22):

# UARTモジュールについて
- 各応用例の通信部分はSipeedのサンプル( https://github.com/sipeed/TangNano-20K-example )をベースにして独自に書き替えたものを使っています．CPU速度と通信速度によっては不安定だったりすることがあり，時々書き直してます．旧版との互換性を全部確認するのは面倒なので最新版は別のフォルダに入れることにしました．
- uart_txでステートが謎の遷移をする現象があったので，20240413版ではsipeedのサンプルを見倣ってステート遷移と信号の処理をバラバラに書くように修正したのですが，読み難いので20240507版で元に戻しました．が，20240413版より不安定かも．(2024/5/7)
- DCJ11用に修正したuart.vが前版より安定したのでapplications/uart/uart.v.20240621 に置きました．
- top.v側のrx_clearとtx_sendのロジックを下記のようにすると安定するようでした．
```
always @(受信バッファへのアクセストリガ or negedge rx_data_ready)
  if(~rx_data_ready)
     rx_clear <= 1'b0;
  else if(受信バッファへのアクセス判定)
     rx_clear <= 1'b1;
  else 
     rx_clear <= 1'b0;

always @(送信バッファへのアクセストリガ or negedge tx_ready)
  if(~tx_ready)
    tx_send <= 1'b0;
  else if(送信バッファへのアクセス判定)
    {tx_data, tx_send} <= {送信値, 1'b1};
  else
    tx_send <= 1'b0; // fail safe to avoid deadlock
```

## 更新履歴
- 2024/4/07: uart.vのバグ修正．(tx_ready関連)
- 2024/4/12: uart.vの最新版格納用のフォルダ applications/uart を作成
- 2024/4/13: applications/uart/uart.v 更新
- 2024/4/27: TangNanoZ80MEM: UARTの送信タイミング変更
- 2024/5/07: applications/uart/にuart.v.20240507 追加
- 2024/6/21: applications/uart/にuart.v.20240621 追加
- 2024/6/21: rx_clear, tx_sendのロジックについてこのREADMEに追記

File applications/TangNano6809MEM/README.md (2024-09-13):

# TangNano6809MEM
- MC6809用のメモリシステムとクロック，UARTです．
- [電脳伝説さんのSBC6809](https://vintagechips.wordpress.com/2017/12/05/sbc6809%E3%83%AB%E3%83%BC%E3%82%BA%E3%82%AD%E3%83%83%E3%83%88/)のdatapackに入っているBASIC9がバイナリそのままで動きます．

BASIC9起動画面
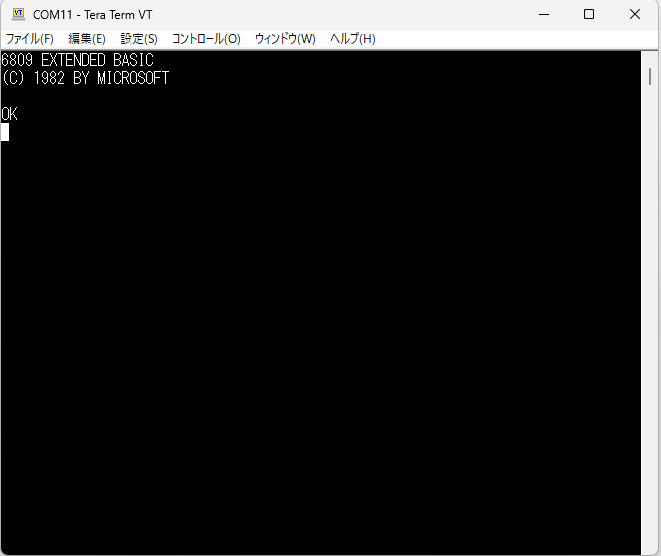
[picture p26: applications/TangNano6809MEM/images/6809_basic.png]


ASCIIART.BAS実行結果 (外部クロック6MHz)
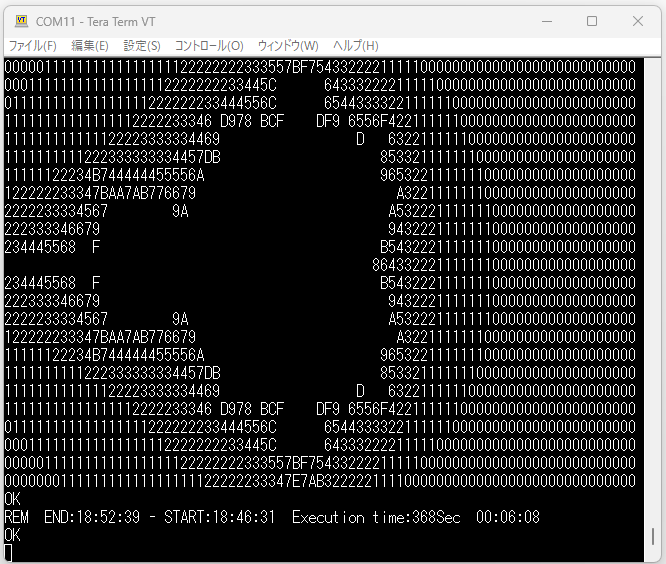
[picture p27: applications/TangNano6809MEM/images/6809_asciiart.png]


## 注意事項
- PC接続時にUSB経由の通信が確立しない問題があることがわかりました．
- ~~入力に使用しているピンのどれかがUSB-JTAGの初期化用の信号と競合しているのが原因な気がしますが特定できませんでした．~~
- ~~下記のようにVCCのラインを切断して，PCと接続後に6809のVCCを継げるという手順が必要です．~~  ~~images/6809_vcc.jpg~~
- RESET_n(pin75)のプルアップ抵抗(R1)が原因でした。pin75は内部で10KでプルダウンされていてB616_BOOTに継がっており、それと競合していました。
- R1を外すことにより上記問題は解決します。

## 更新履歴
- 2023/07/19: 応用例にTangNano6809MEMを追加
- 2024/04/11: TangNano6809MEMに関する注意事項記載
- 2024/04/15: README修正(6809、R1の除去について, TangNano20Kのピンに関するメモ)

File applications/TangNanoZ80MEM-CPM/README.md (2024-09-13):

# TangNanoZ80MEM-CPM
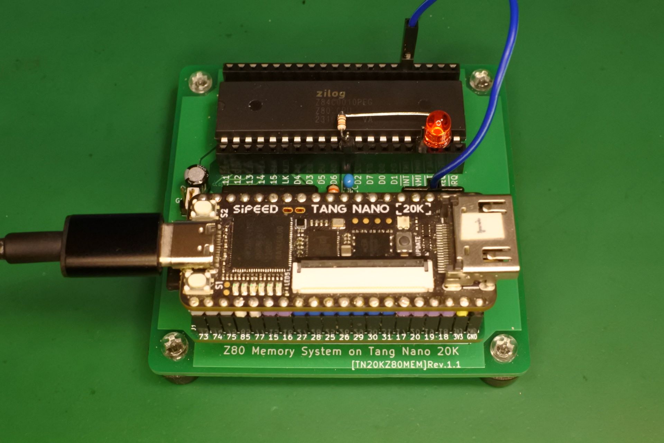
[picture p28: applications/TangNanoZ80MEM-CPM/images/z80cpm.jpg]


- TangNanoZ80MEMにfloppy/hard diskエミュレータを追加してCP/Mを動作させる試みです．
- TangNano20Kのスロットに搭載したSDメモリカードを使用してfloppy/hard diskをエミュレートします．
- ハードウェア(基板)はTangNanoZ80MEMと同じものにBUSREQ_n用のジャンパ線を1本追加します．
- 実験用に作ったものですので，いろいろと不備やバグがあると思います．

## 実装した機能について
- 128byte/sectorのfloppy/hard diskエミュレータ
  - ディスク読み書きの際はBUSREQ_nでCPUを止めてDMAを行いますが，TangNanoのピンが足りないのでBUSACK_nは見ていません．
  詳細は下記参照．
- リセット & IPL
  - power on時にrom.vに書かれたIPLが0000H〜00FFHにロードされます．IPLはSDメモリの先頭128byteに書かれたbootloaderを0000H番地にロードしてその先頭にジャンプます．
  - SW1はZ80のRESET_nによる通常のリセットです．
  - SW2はIPLを再ロードしてリセットします．
  - power on時はIPLがロードされるはずですが，うまく起動しない場合はSW2でリセットして下さい．
- とりあえずお試しで作ってみたので，入出力はコンソールしか実装していません．PRT, AUXは未実装です．

## floppy/hard disk エミュレータについて
- SDメモリはファイルシステム無しの生のままで使うのでddで読み書きします．
- SanDiskのsd(2GB)，KIOXIAのsdhc(32GB)，SAMSUNGのsdxc(64GB)での動作を確認しています．
- drive a, b, c, dは256KBのフロッピー，drive i,jは4MBのHDDです．512MBのdrive pというものもあるようなのですが，track, sectorの指定方法がわからなかったので未実装です．
- diskのイメージは下記のような感じで配置して下さい
```
dd if=drivea.dsk of=sd.dsk bs=128 seek=0
dd if=driveb.dsk of=sd.dsk bs=128 seek=2048
dd if=drivec.dsk of=sd.dsk bs=128 seek=4096
dd if=drived.dsk of=sd.dsk bs=128 seek=6144
dd if=drivei.dsk of=sd.dsk bs=128 seek=8192
dd if=drivej.dsk of=sd.dsk bs=128 seek=40960
```

## CP/Mのイメージファイルについて
最初は
[udo-munk/z80pack](https://github.com/udo-munk/z80pack)のcpm22をそのまま使おうと思っていたのですが，コンソール入力がうまくいかなかったので，Universal Monitorで使っているコンソールのI/Oの仕様
```
data   = 00H; 
status = 01H;
 bit0: rx_data_ready
 bit2: tx_ready
```
にBIOSを書き変えたものを使いました．

## とりあえず動かすための手順
### ジャンパ配線
- DBG_TRG を BUSREQ_n に接続します．
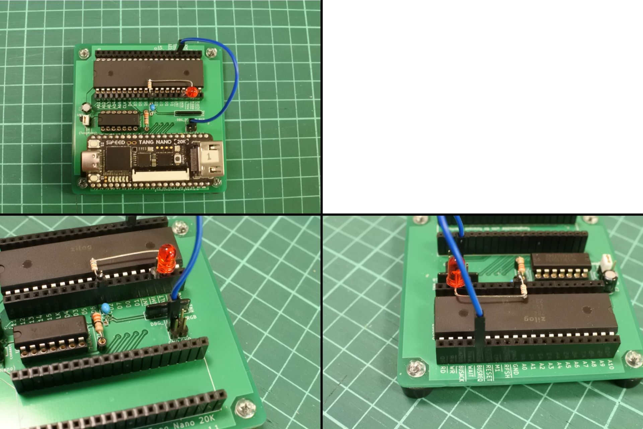
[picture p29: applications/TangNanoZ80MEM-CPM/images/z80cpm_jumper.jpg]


### disk imageの準備
- z80packのcpm22のbiosにパッチをあててmakeしたものを使ってdrivea.dskを作り，drive.b.dskとつなげて sd.dskを作成します．
- 書き込み先のsdメモリが/dev/sdb で正しいかちゃんと確認すること．間違えるとPCのディスクを破壊します.
- 下記手順を参考にして下さい．ちなみに私はVMWare上のubuntuで作業しています．

```
- z80packを取ってきてbuildする
git clone https://github.com/udo-munk/z80pack.git

- ビルドにはjpgとglの開発環境が必要っぽいので下記で追加．
sudo apt install libjpeg-dev
sudo apt install freeglut3-dev

cd z80pack
make

- disksフォルダにcpm22用のdiskをコピーしておく
cd z80pack/cpmsim
rm -f disks/drive[ab].dsk
cp disks/library/cpm22-1.dsk disks/drivea.dsk
cp disks/library/cpm22-2.dsk disks/driveb.dsk
cp disks/library/hd-tools.dsk disks/drivei.dsk
cp disks/library/hd-toolsrc.dsk disks/drivej.dsk

- bios-tangnano.patch をあててmakeする
cd z80pack/cpmsim/srccpm2
patch -b < bios-tangnano.patch
make

- drivea.dsk を更新する
./putsys

- drivea.dskとdriveb.dskを継げてsd.dskを作る
dd if=../disks/drivea.dsk of=sd.dsk conv=notrunc bs=128 seek=0
dd if=../disks/driveb.dsk of=sd.dsk conv=notrunc bs=128 seek=2048
dd if=../disks/drivei.dsk of=sd.dsk conv=notrunc bs=128 seek=8192
dd if=../disks/drivej.dsk of=sd.dsk conv=notrunc bs=128 seek=40960

- sdメモリに書き込む(/dev/sdbで正しいかどうかは十分確認すること)
sudo if=sd.dsk of=/dev/sdb
```

## 実行サンプル
- [www.retroarchive.org/cpm](http://www.retroarchive.org/cpm/)にあったmbasic.com を，z80packのシミュレーターにファイルを転送してdisk imageを作って実機で実行してみました．

- MBASIC(BASIC-80 Rev.5.21)
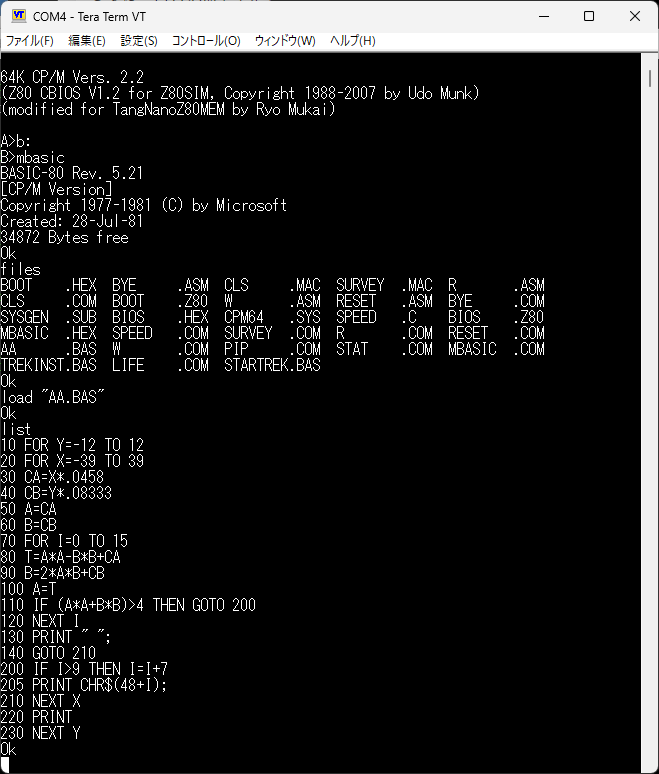
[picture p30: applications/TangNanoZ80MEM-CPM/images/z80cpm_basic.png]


- MBASICでASCIIART.BAS
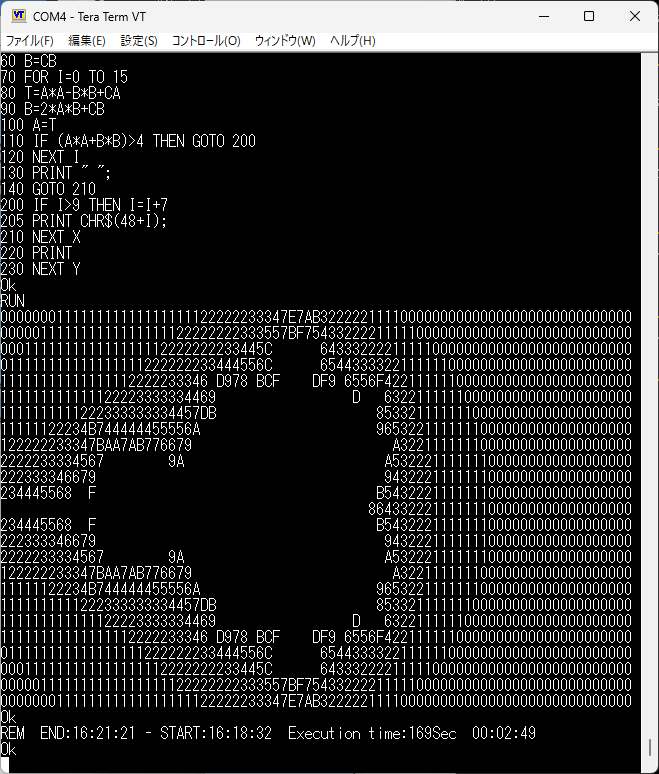
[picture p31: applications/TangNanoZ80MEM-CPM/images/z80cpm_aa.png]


- SUPER STARTREK


## 動画
- [TangNanoZ80MEM-CPM でStarTrek](https://www.youtube.com/watch?v=MoRSxTNyhwA)

## 関連情報，参考にしたサイト等
- z80pack [udo-munk/z80pack](https://github.com/udo-munk/z80pack)
- SuperMEZ80-CPM [hanyazou/SuperMEZ80-CPM](https://github.com/hanyazou/SuperMEZ80-CPM)
- CPUville [cpuville.com/Code/CPM.html](http://cpuville.com/Code/CPM.html)
- [www.retroarchive.org/cpm](http://www.retroarchive.org/cpm/)
- [www.z80.eu](http://www.z80.eu/)
- Universal Monitor [https://electrelic.com/electrelic/node/1317](https://electrelic.com/electrelic/node/1317)

## 更新履歴
- 2024/07/23: 初版公開

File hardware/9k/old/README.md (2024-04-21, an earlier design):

# Tang Nano 9K 版(rev.2.0)
## 機能
- Tang Nanoの9KのGPIO(全45本)を，TXS0108を介して5V系(TTL, CMOS)に接続します．
- 信号方向を意識することなく双方向接続が可能です．
- Pin79〜86は1.8Vのバンクなので，1.8V←→5Vの変換をします．その他のPinは3.3V←→5Vです．

## 動作の確認状況
- 27MHzのシステムクロックが全GPIOで5V系に出力できることを確認しました．
- 入力側もHDMI関連ピンを除いて27MHzで入力できています．(下記参照)
- JTAG関連が競合しているのか，USBを認識しなくなることがあります．

## Pin68〜75について(TangNano9K)
- HDMI端子に継がっているピン(pin68～75)の挙動がおかしいです。
Lを入力すると異常発振します。Hにすると止まります。
おそらく100nFのコンデンサとその先のU1、U2が悪さをしていると思います。
これらのピンは使用しないか，HDMIを使わないなら外してしまってもいいかもしれません．

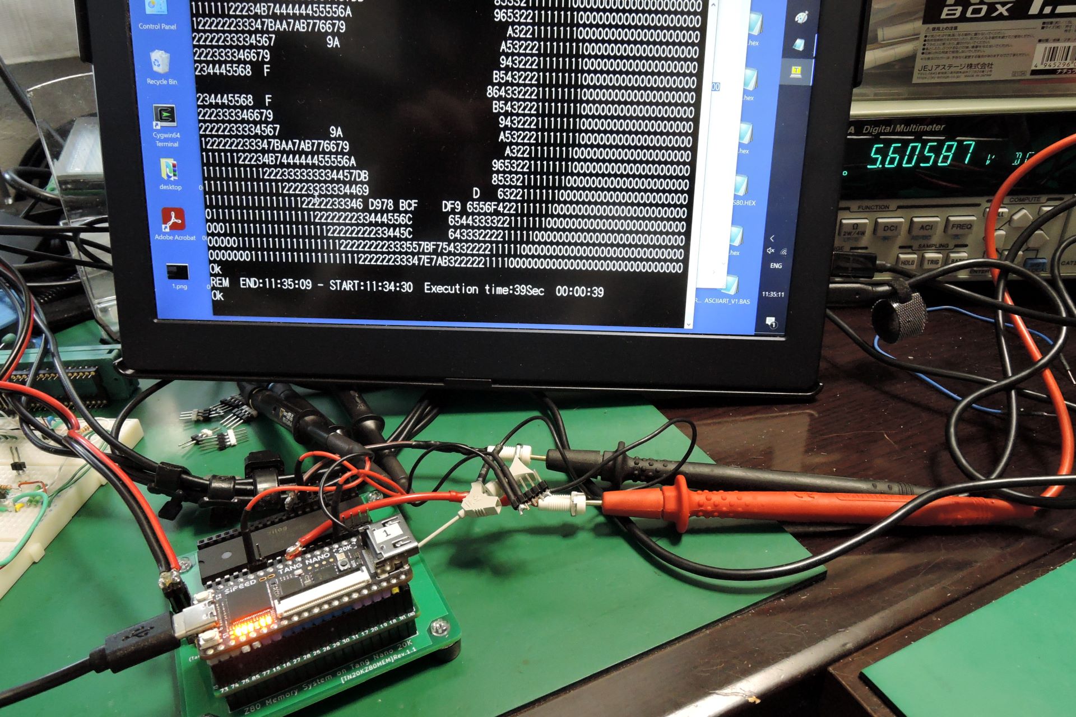
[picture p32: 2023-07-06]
images/asciiart_31.5MHz_5.6V.jpg

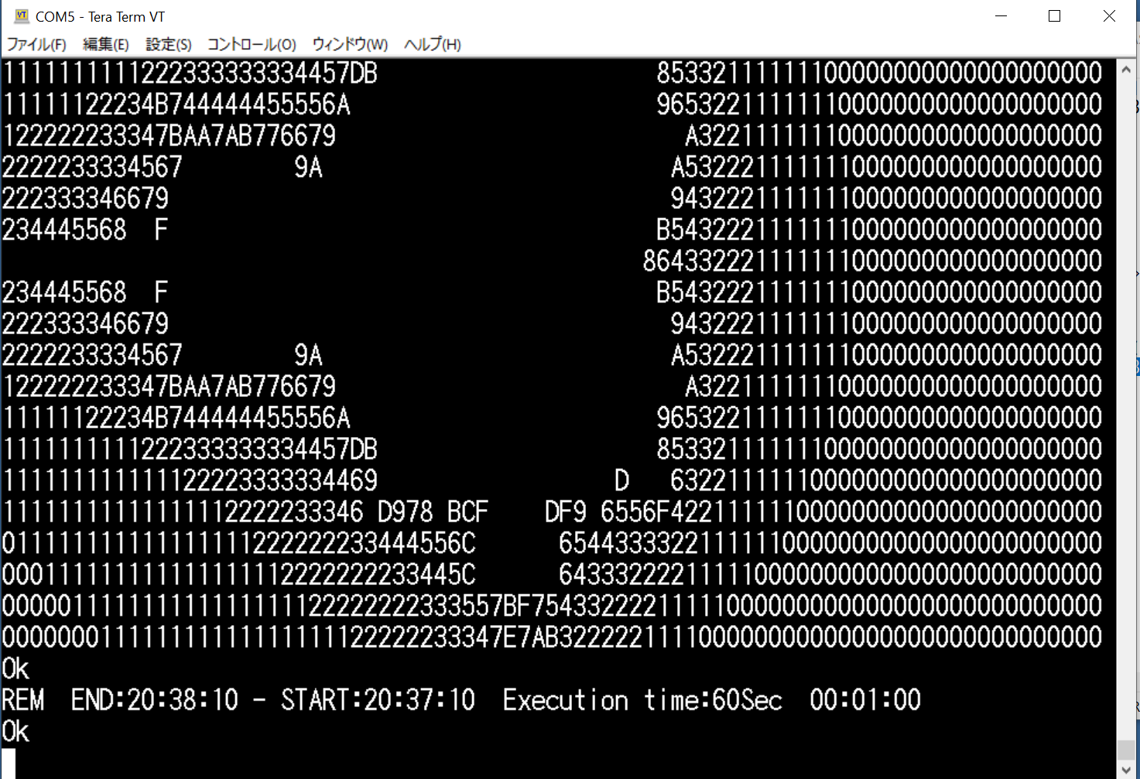
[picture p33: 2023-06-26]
images/asciiart_20.25MHz.png

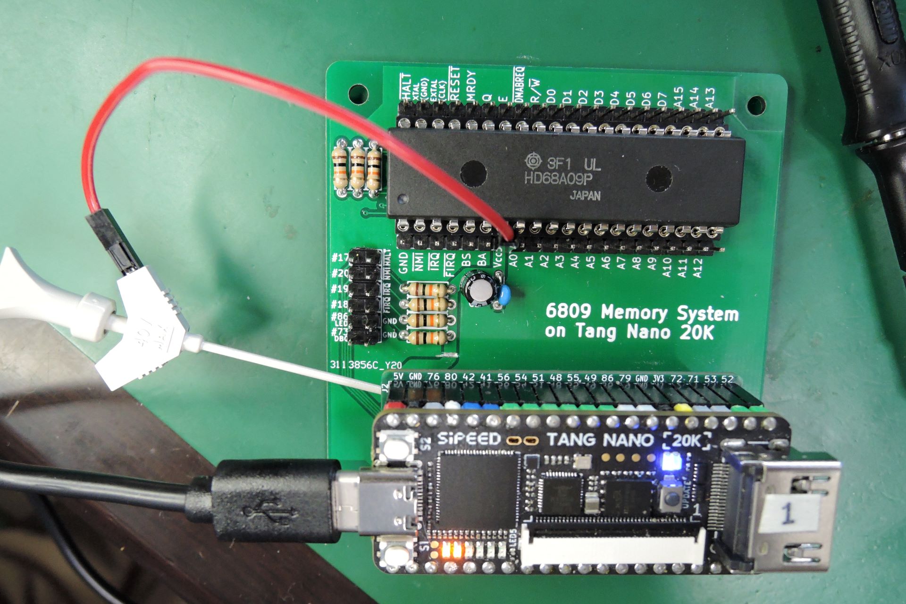
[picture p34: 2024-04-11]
applications/TangNano6809MEM/images/6809_vcc.jpg

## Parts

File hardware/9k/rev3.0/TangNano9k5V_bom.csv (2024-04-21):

Reference | Value | Datasheet | Footprint | Qty | DNP
C3,C4,C5,C6,C7,C8,C9 | 0.1uF | ~ | 000_MyFootprint:C_0603_1608Metric_Pad1.08x0.95mm_HandSolder | 7
J1 | VCCB | ~ | 000_MyFootprint:PinHeader_1x03_P2.54mm_Vertical | 1
J2,J3,J4,J5 | Conn_01x24 | ~ |  | 4
PS1 | TLV71318_SOT23-5 | http://www.ti.com/lit/ds/symlink/tlv713.pdf | Package_TO_SOT_SMD:SOT-23-5 | 1
U1 | TXS0108EPW | www.ti.com/lit/ds/symlink/txs0108e.pdf | Package_SO:TSSOP-20_4.4x6.5mm_P0.65mm | 1
U2,U3,U4,U5,U6 | SN74CB3T3245PW | SN74CB3T3245PW | 000_MyFootprint:PW20 | 5

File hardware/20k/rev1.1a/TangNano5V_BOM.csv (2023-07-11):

# | Reference | Qty | Value
1 | C1, C2, C3, C4, C5 | 5 | 0.1uF | 0603(inch)(1608 (mm))
2 | J1, J2 | 2 | 1x20 pin socket for Tang Nano 20K
3 | J3, J4 | 2 | 1x20 pin header for 5V GPIO
4 | U1, U2, U3, U4, U5 | 5 | SN74CB3T3245PW

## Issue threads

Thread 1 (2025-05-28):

level shifter selection

dijitalxyz, 2025-05-28:
I want to ask something
if our aim is to change the level between 5 volts - 3.3 volts, s
why didn't we proceed a
SN74CB3T3245 8-Bit FET Bus Switch 2.5-V and 3.3-V Low-Voltage With 5-V-Tolerant Level Shifter

Couldn't it be among the choices we could make?
TXS0108E 8-Bit Bi-Directional, Level-Shifting, Voltage Translator for Open-Drain and Push-Pull Applications

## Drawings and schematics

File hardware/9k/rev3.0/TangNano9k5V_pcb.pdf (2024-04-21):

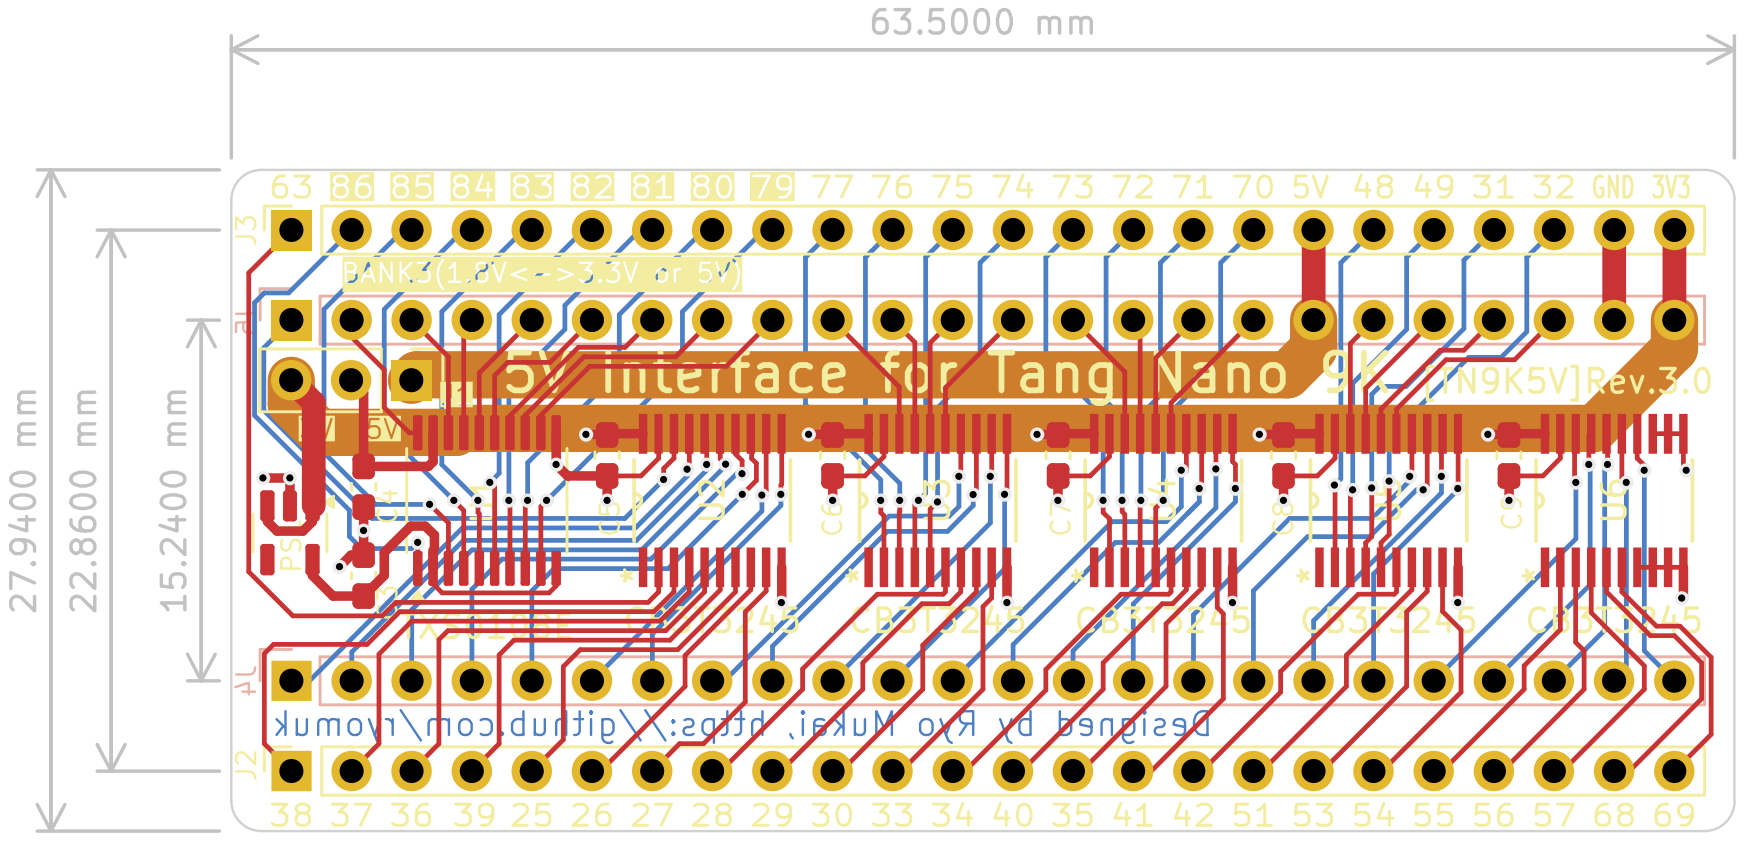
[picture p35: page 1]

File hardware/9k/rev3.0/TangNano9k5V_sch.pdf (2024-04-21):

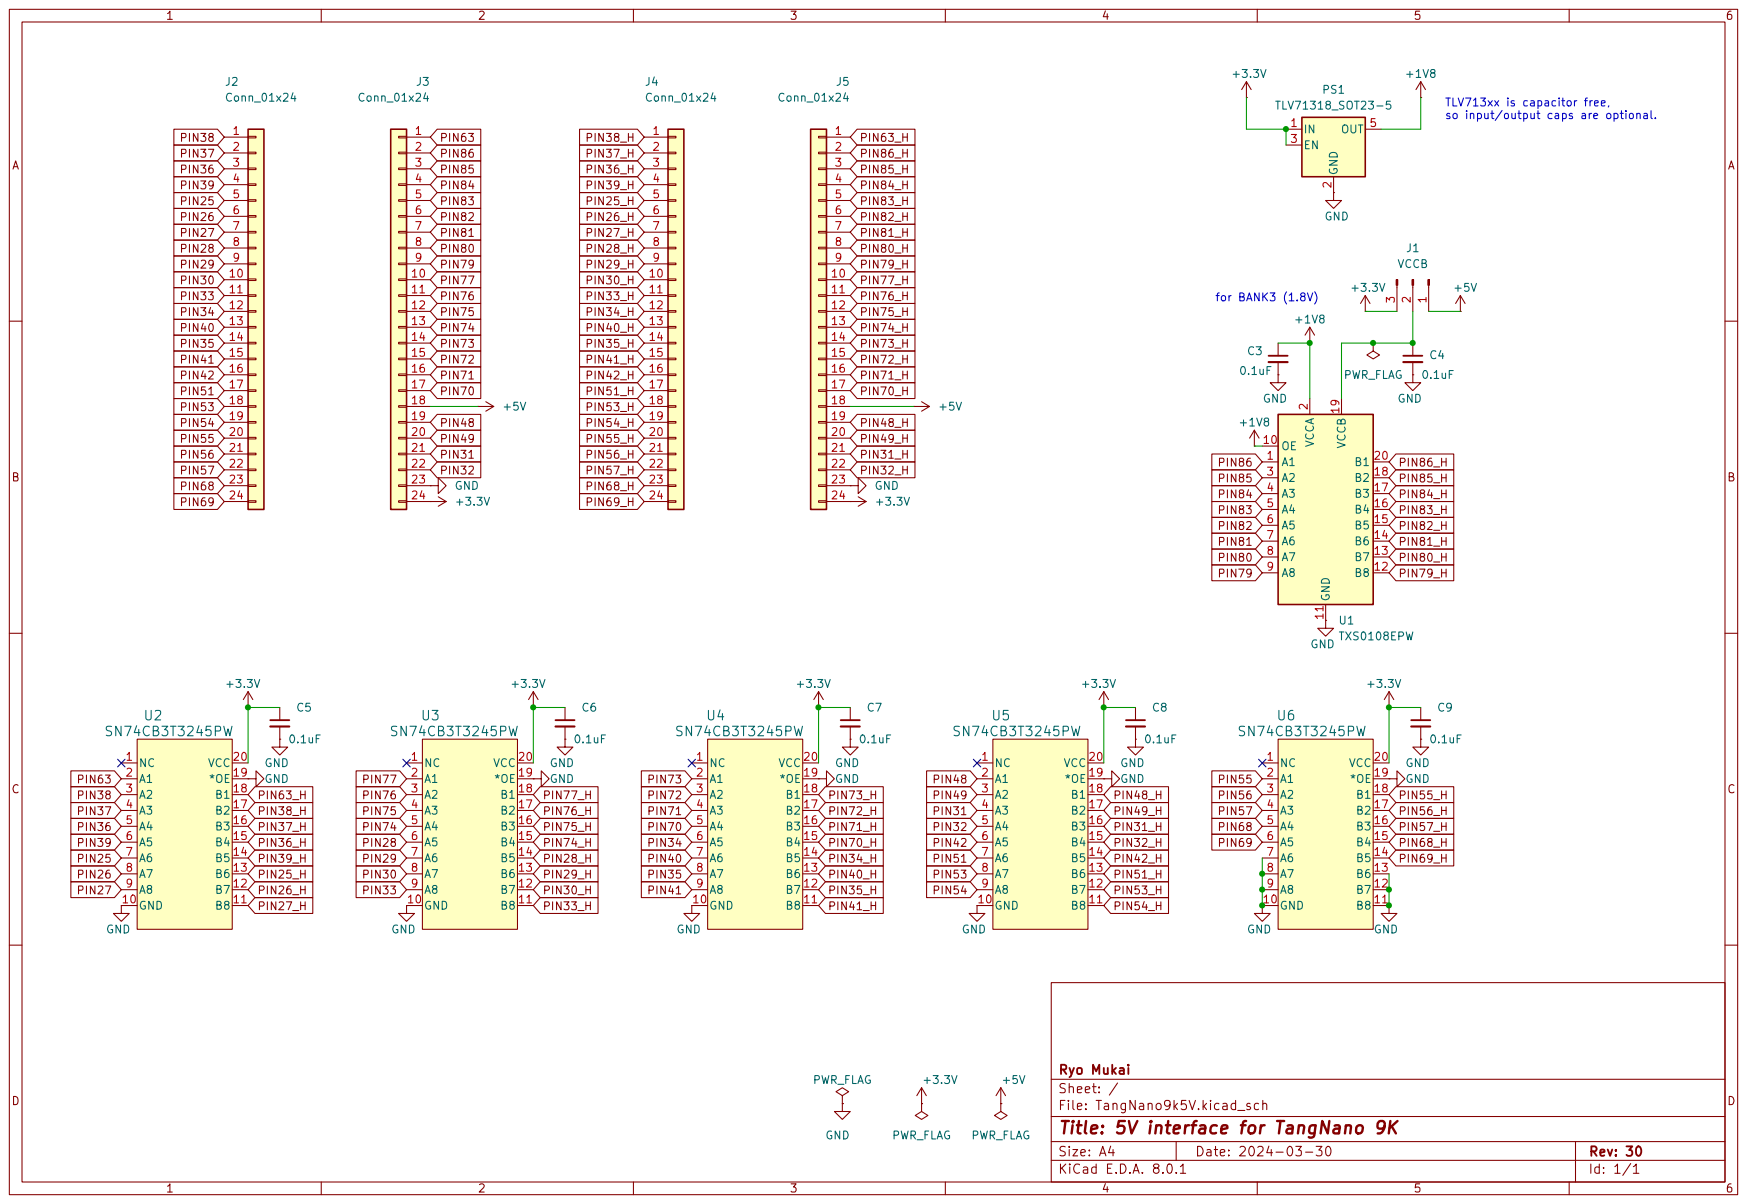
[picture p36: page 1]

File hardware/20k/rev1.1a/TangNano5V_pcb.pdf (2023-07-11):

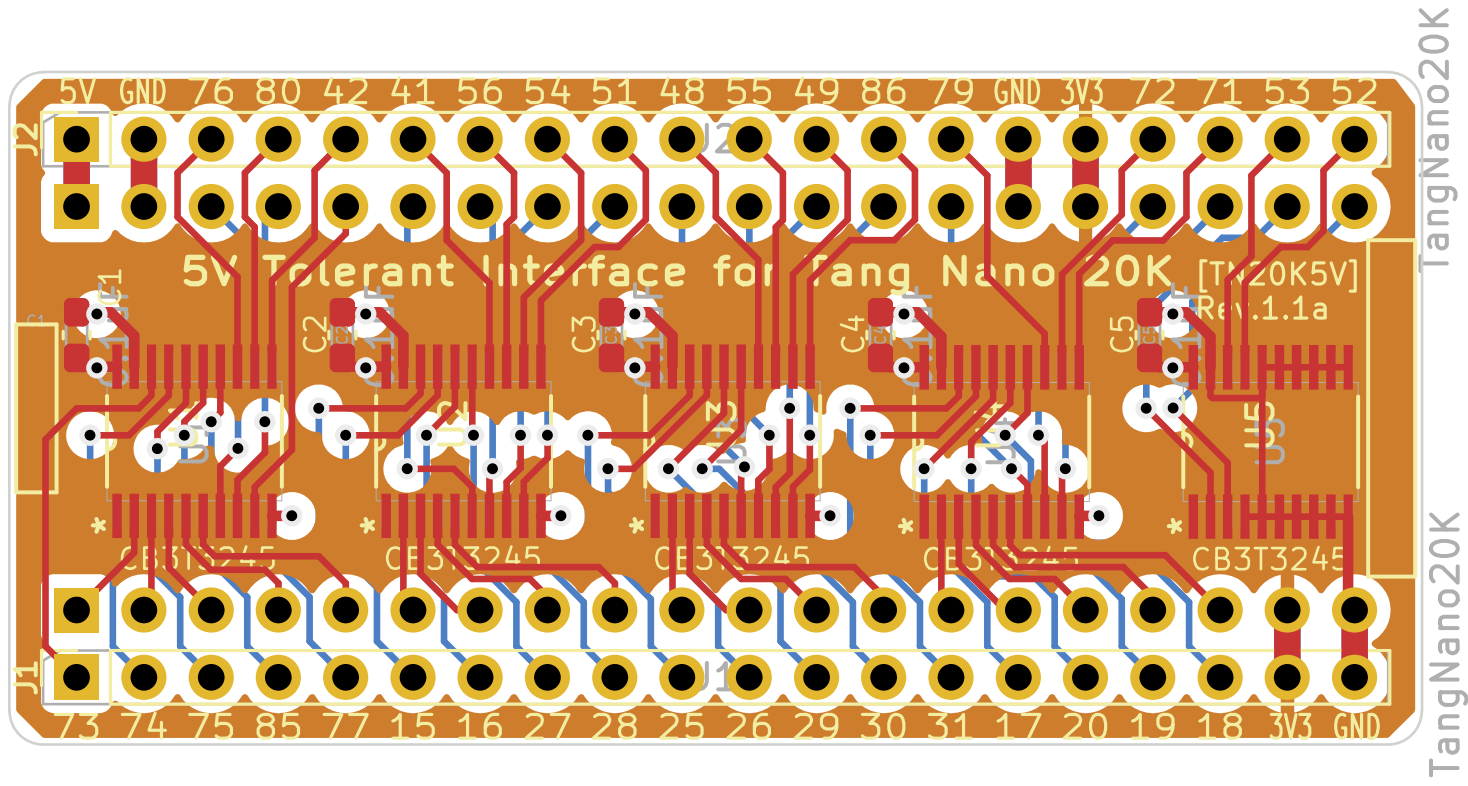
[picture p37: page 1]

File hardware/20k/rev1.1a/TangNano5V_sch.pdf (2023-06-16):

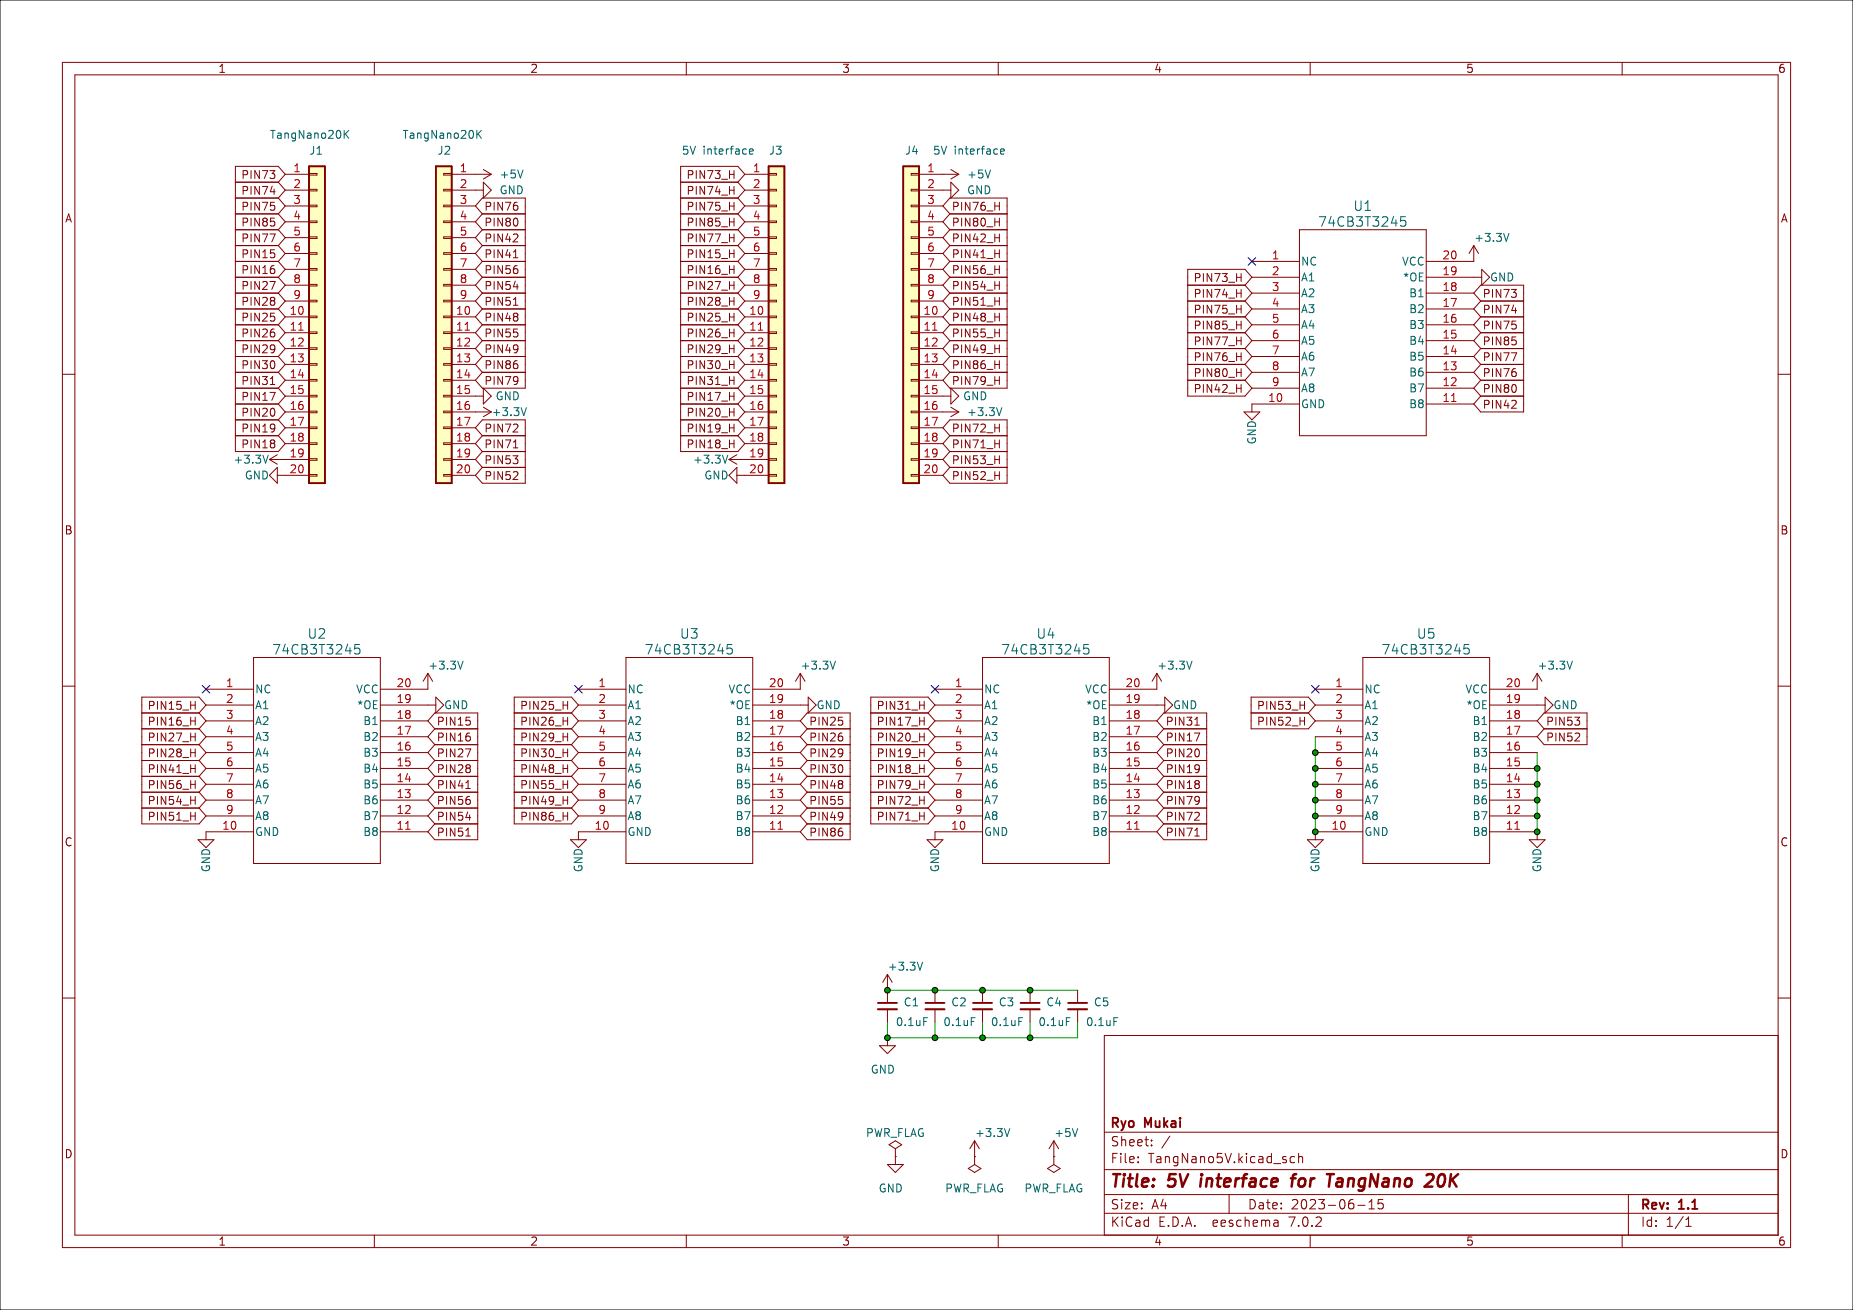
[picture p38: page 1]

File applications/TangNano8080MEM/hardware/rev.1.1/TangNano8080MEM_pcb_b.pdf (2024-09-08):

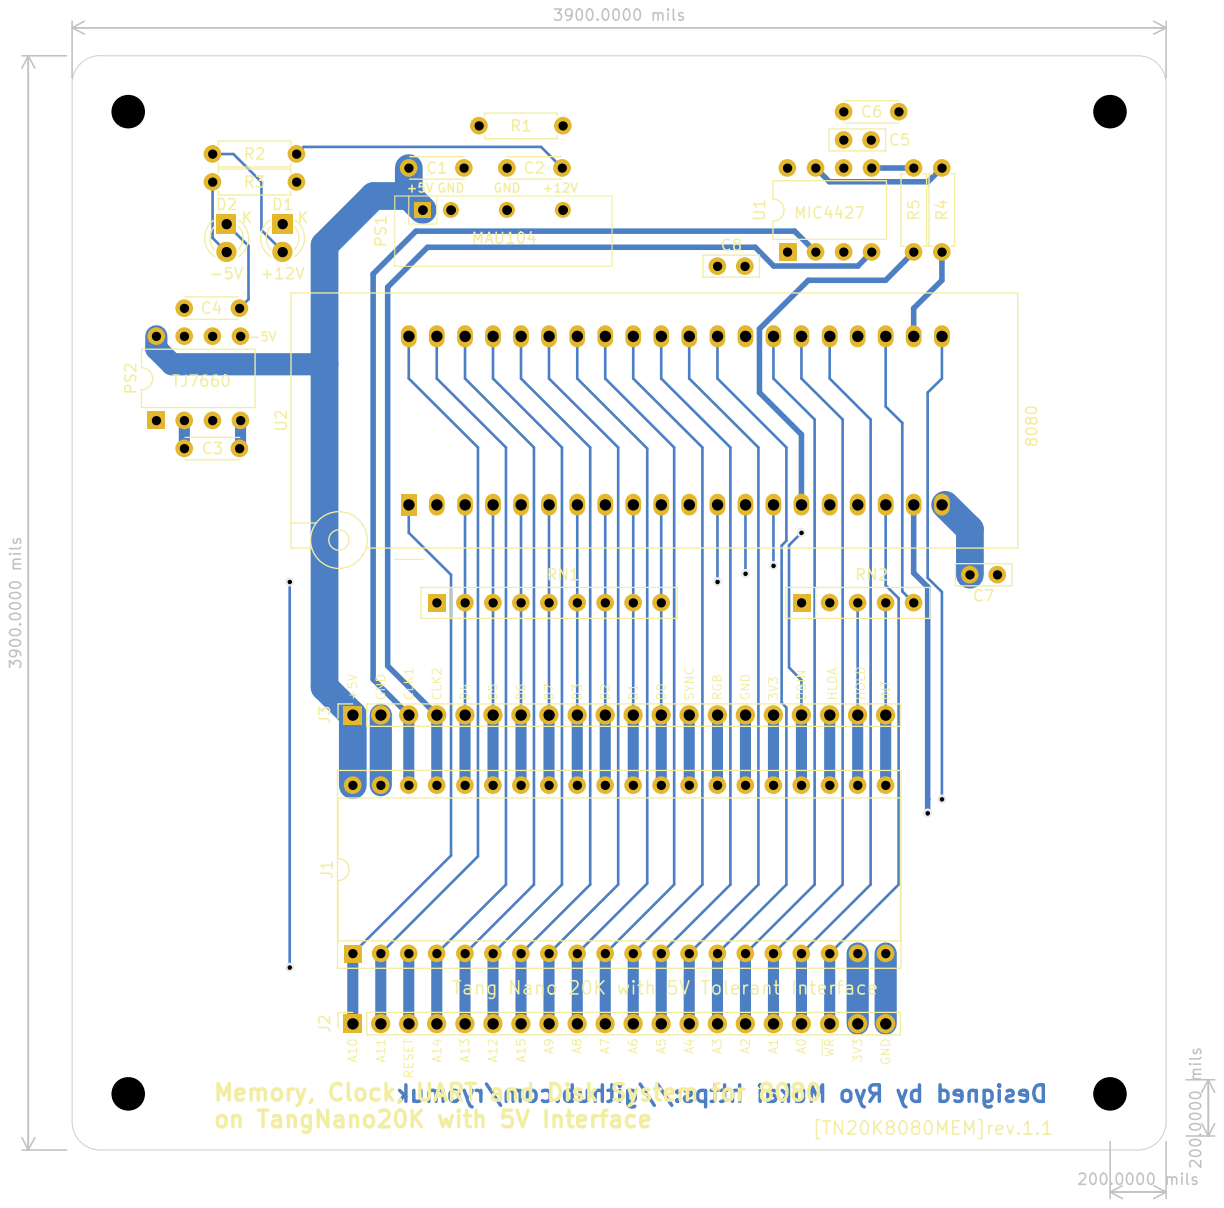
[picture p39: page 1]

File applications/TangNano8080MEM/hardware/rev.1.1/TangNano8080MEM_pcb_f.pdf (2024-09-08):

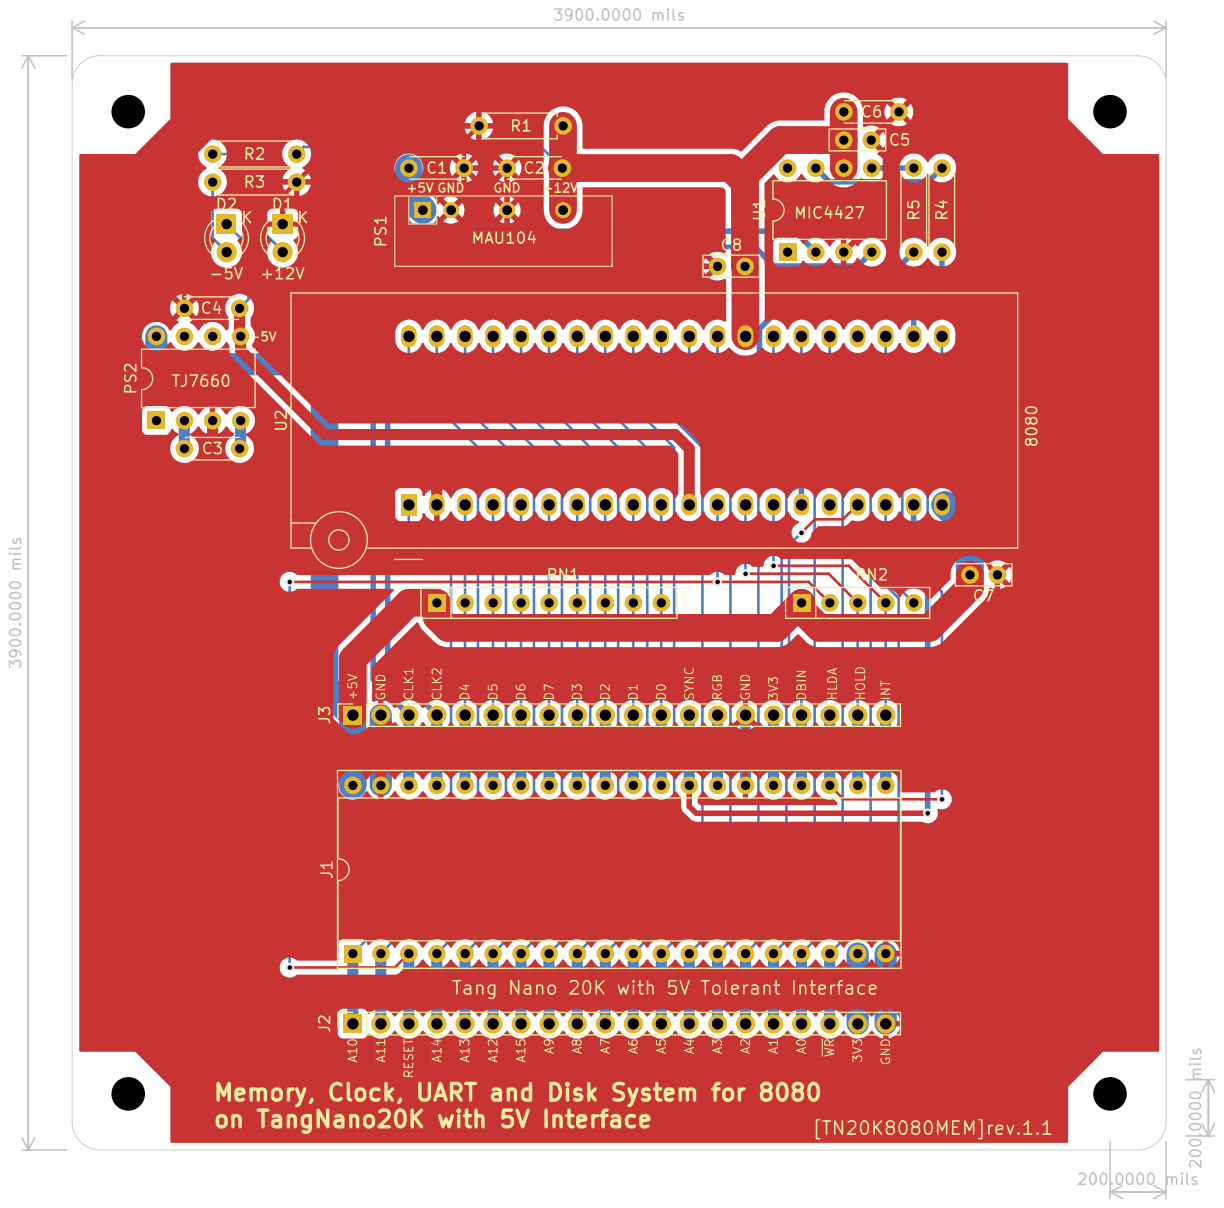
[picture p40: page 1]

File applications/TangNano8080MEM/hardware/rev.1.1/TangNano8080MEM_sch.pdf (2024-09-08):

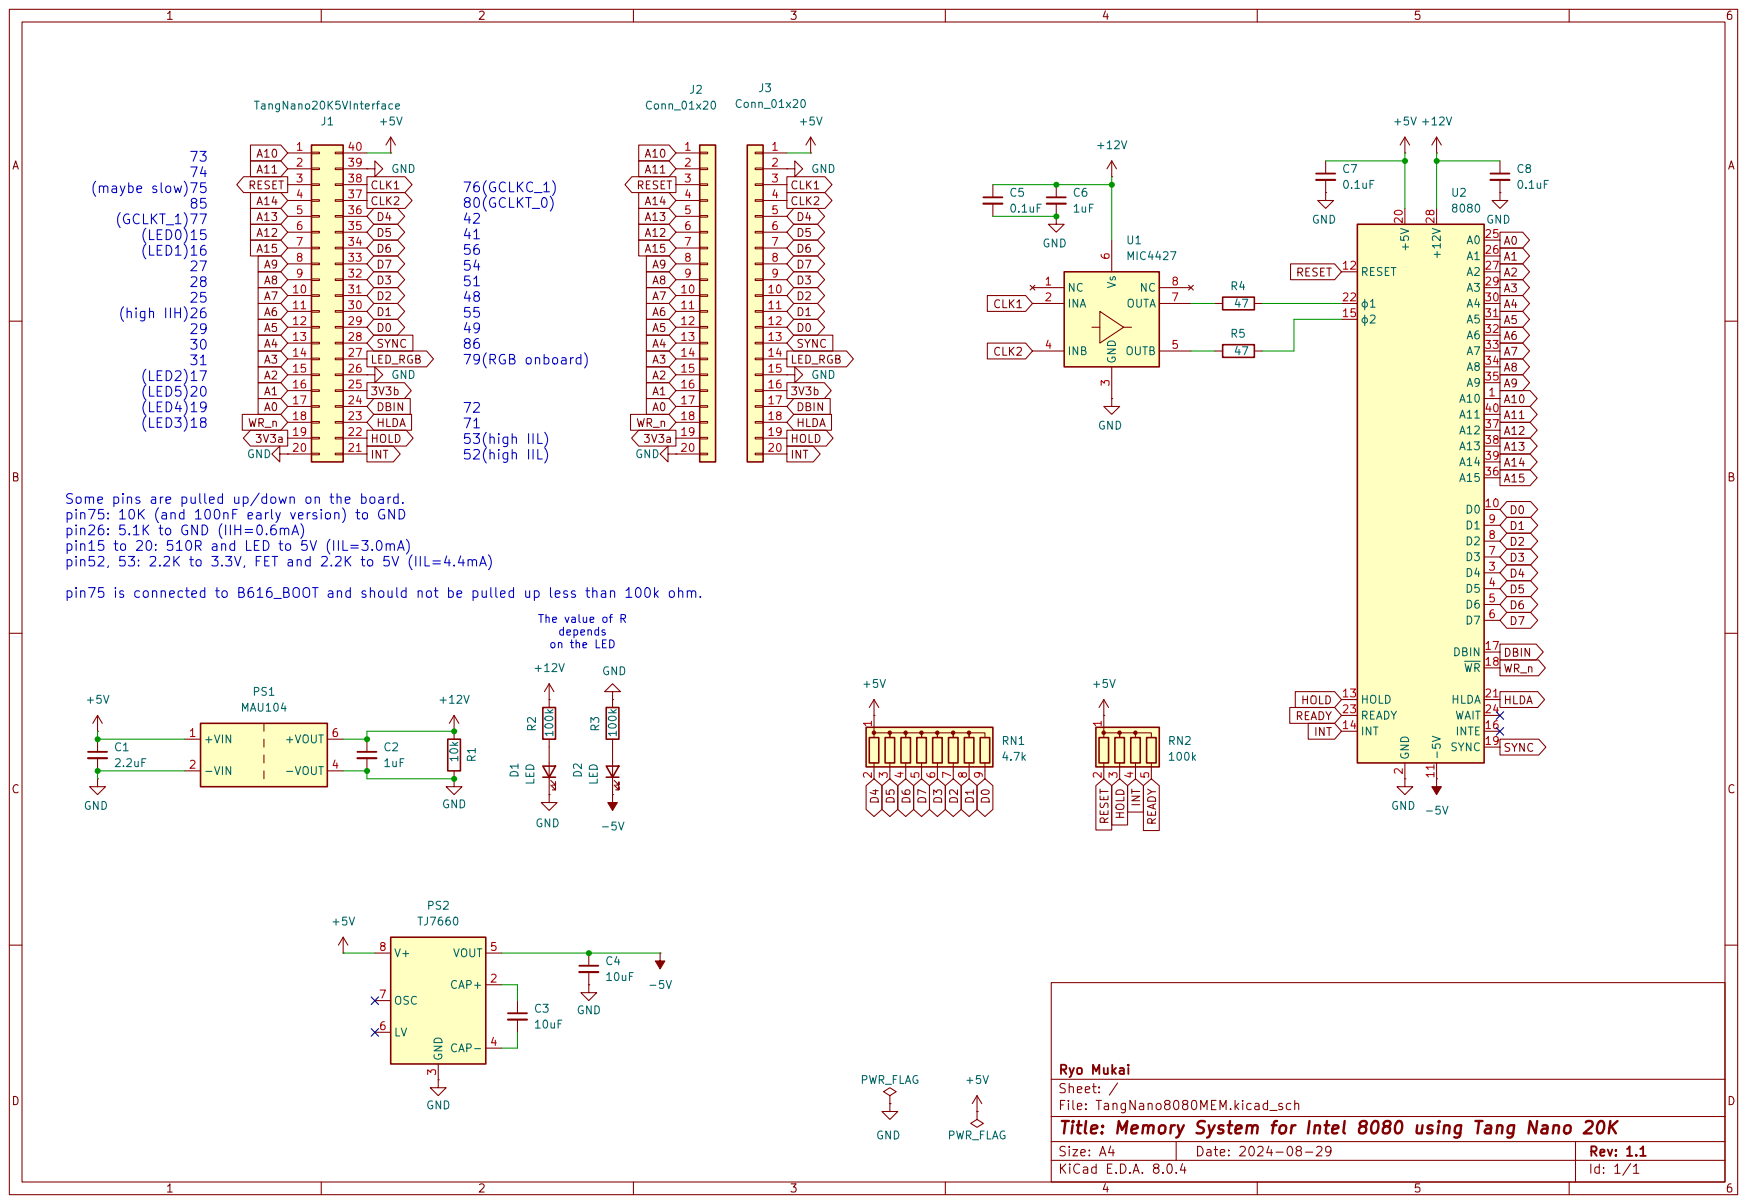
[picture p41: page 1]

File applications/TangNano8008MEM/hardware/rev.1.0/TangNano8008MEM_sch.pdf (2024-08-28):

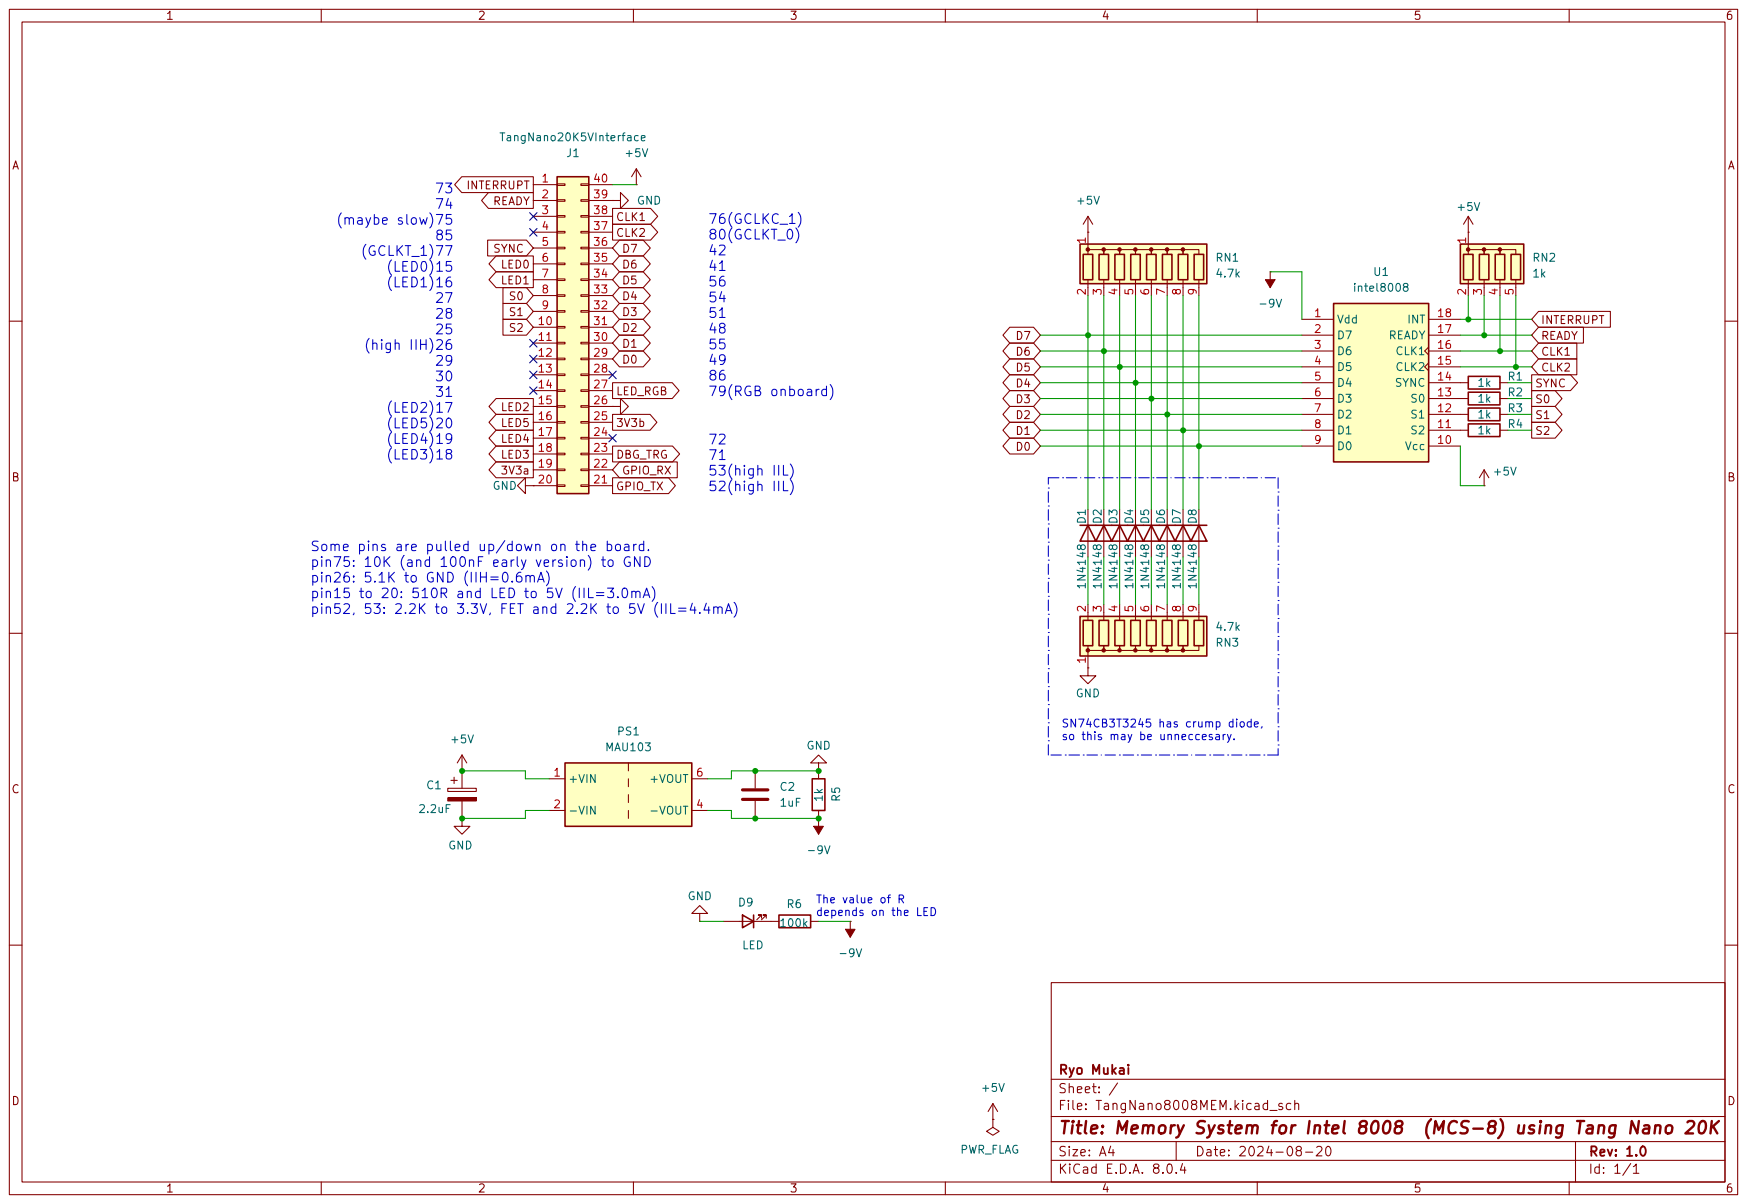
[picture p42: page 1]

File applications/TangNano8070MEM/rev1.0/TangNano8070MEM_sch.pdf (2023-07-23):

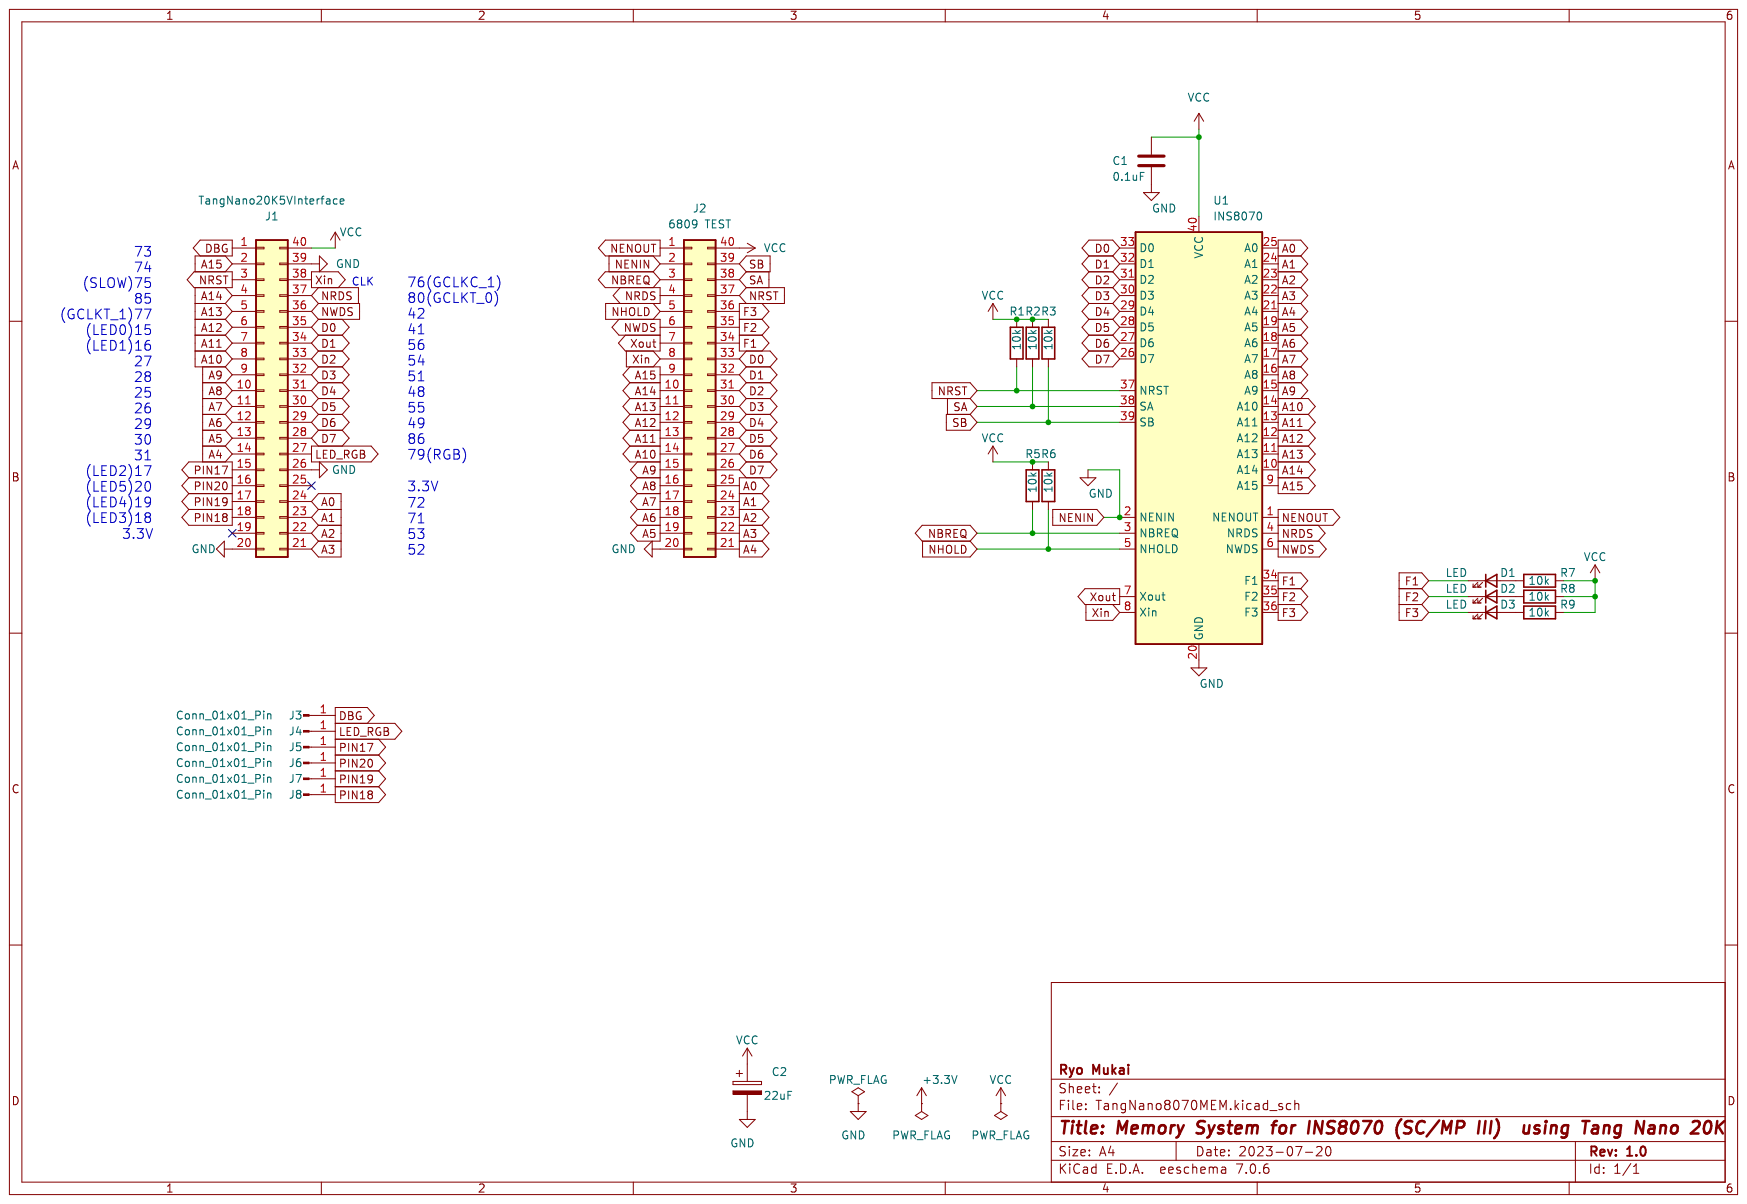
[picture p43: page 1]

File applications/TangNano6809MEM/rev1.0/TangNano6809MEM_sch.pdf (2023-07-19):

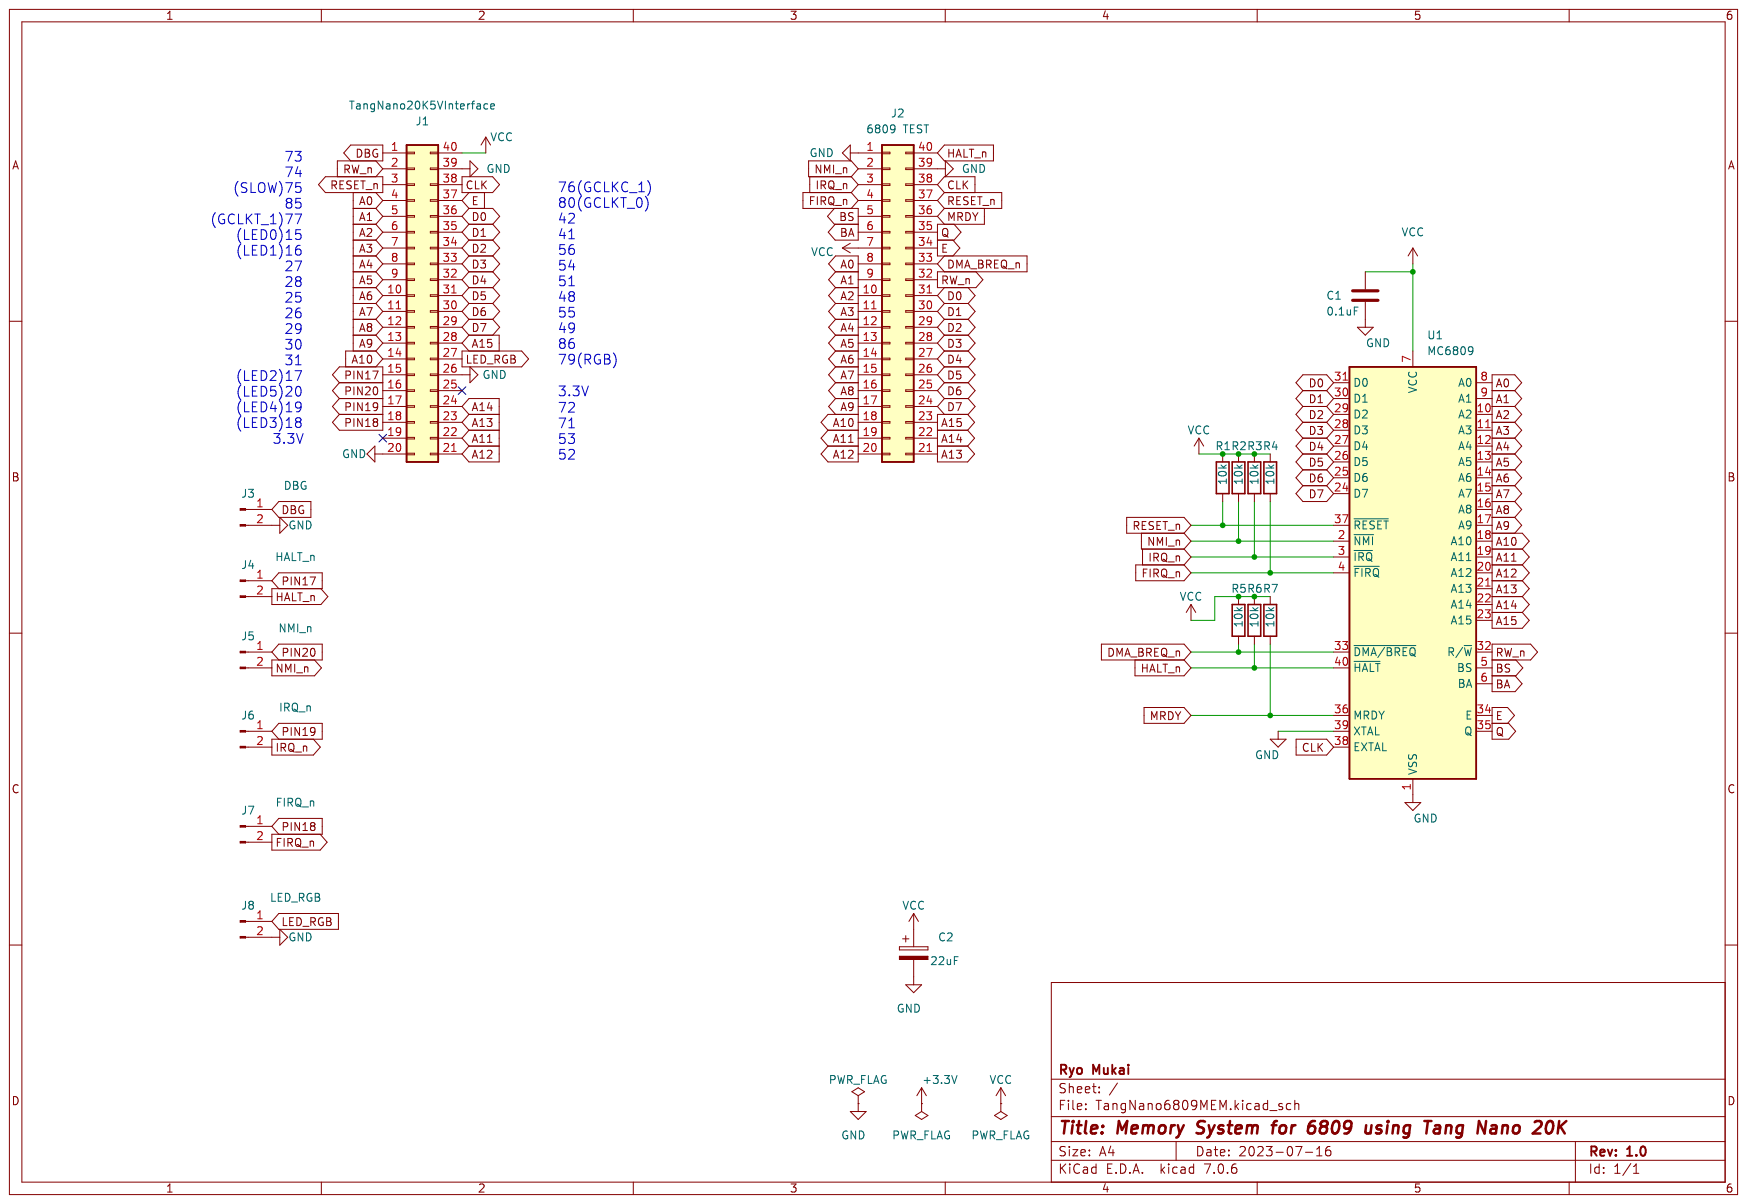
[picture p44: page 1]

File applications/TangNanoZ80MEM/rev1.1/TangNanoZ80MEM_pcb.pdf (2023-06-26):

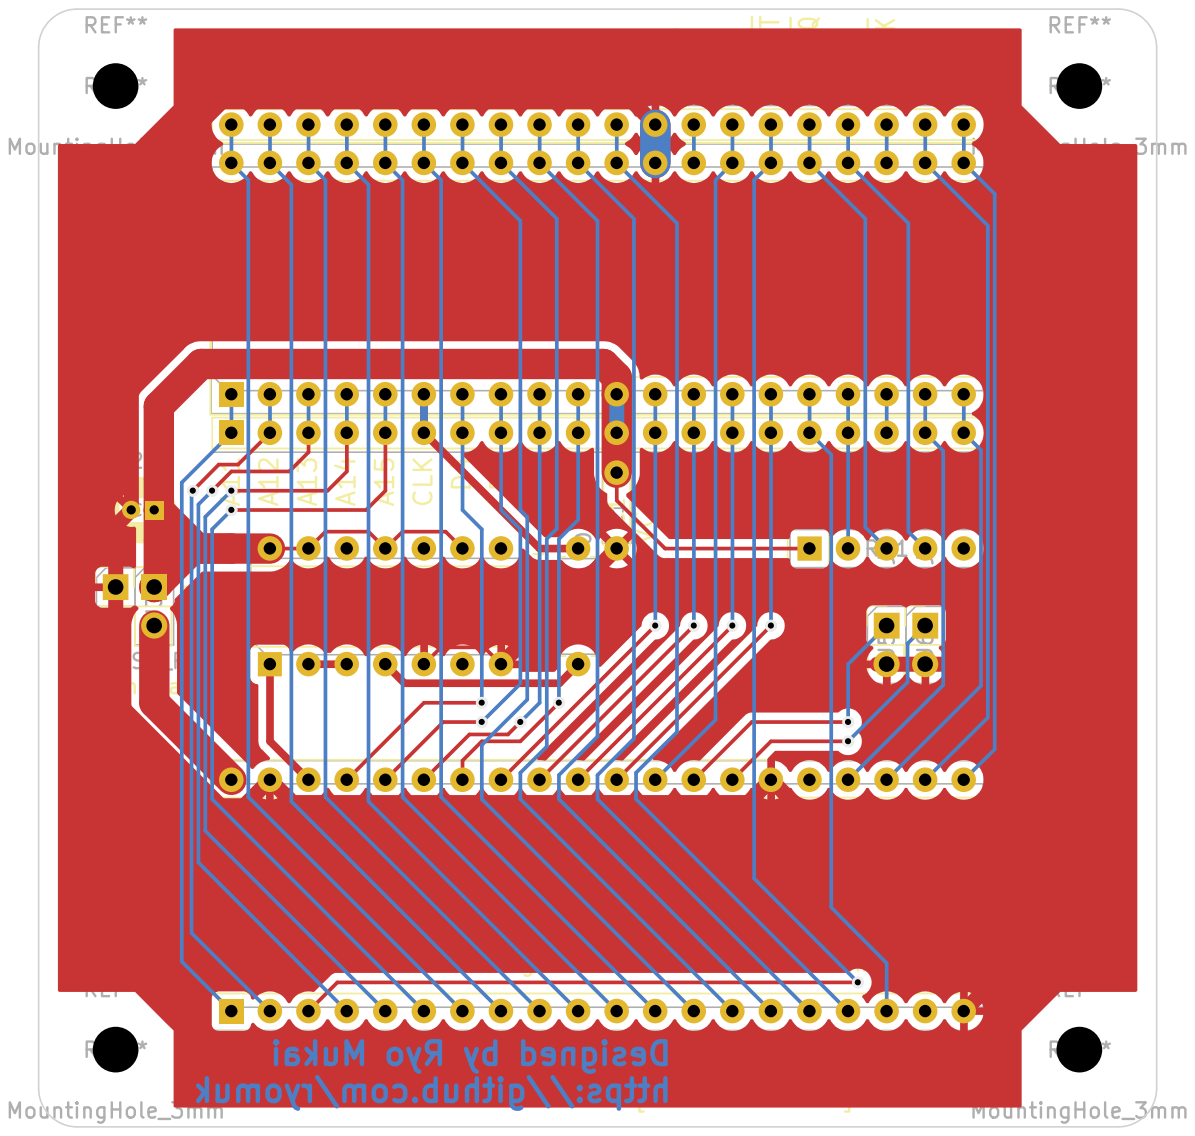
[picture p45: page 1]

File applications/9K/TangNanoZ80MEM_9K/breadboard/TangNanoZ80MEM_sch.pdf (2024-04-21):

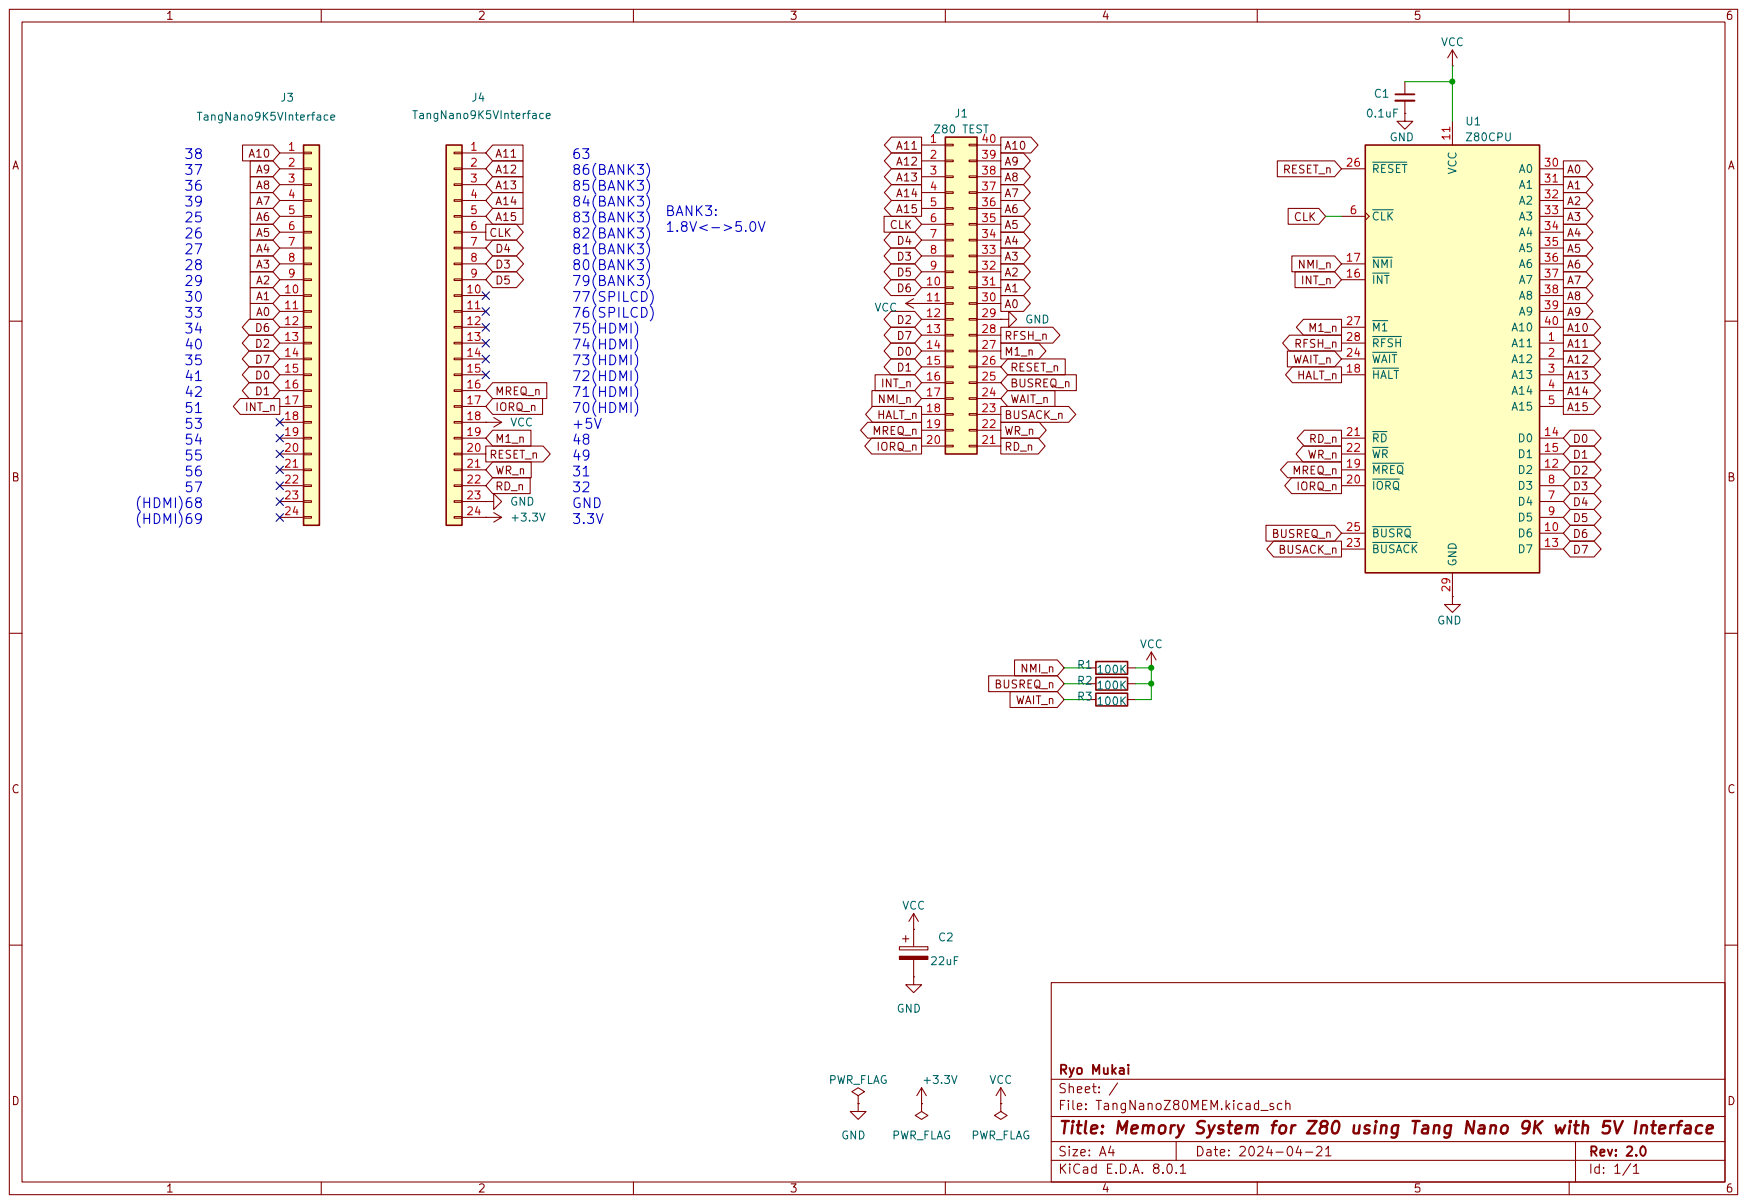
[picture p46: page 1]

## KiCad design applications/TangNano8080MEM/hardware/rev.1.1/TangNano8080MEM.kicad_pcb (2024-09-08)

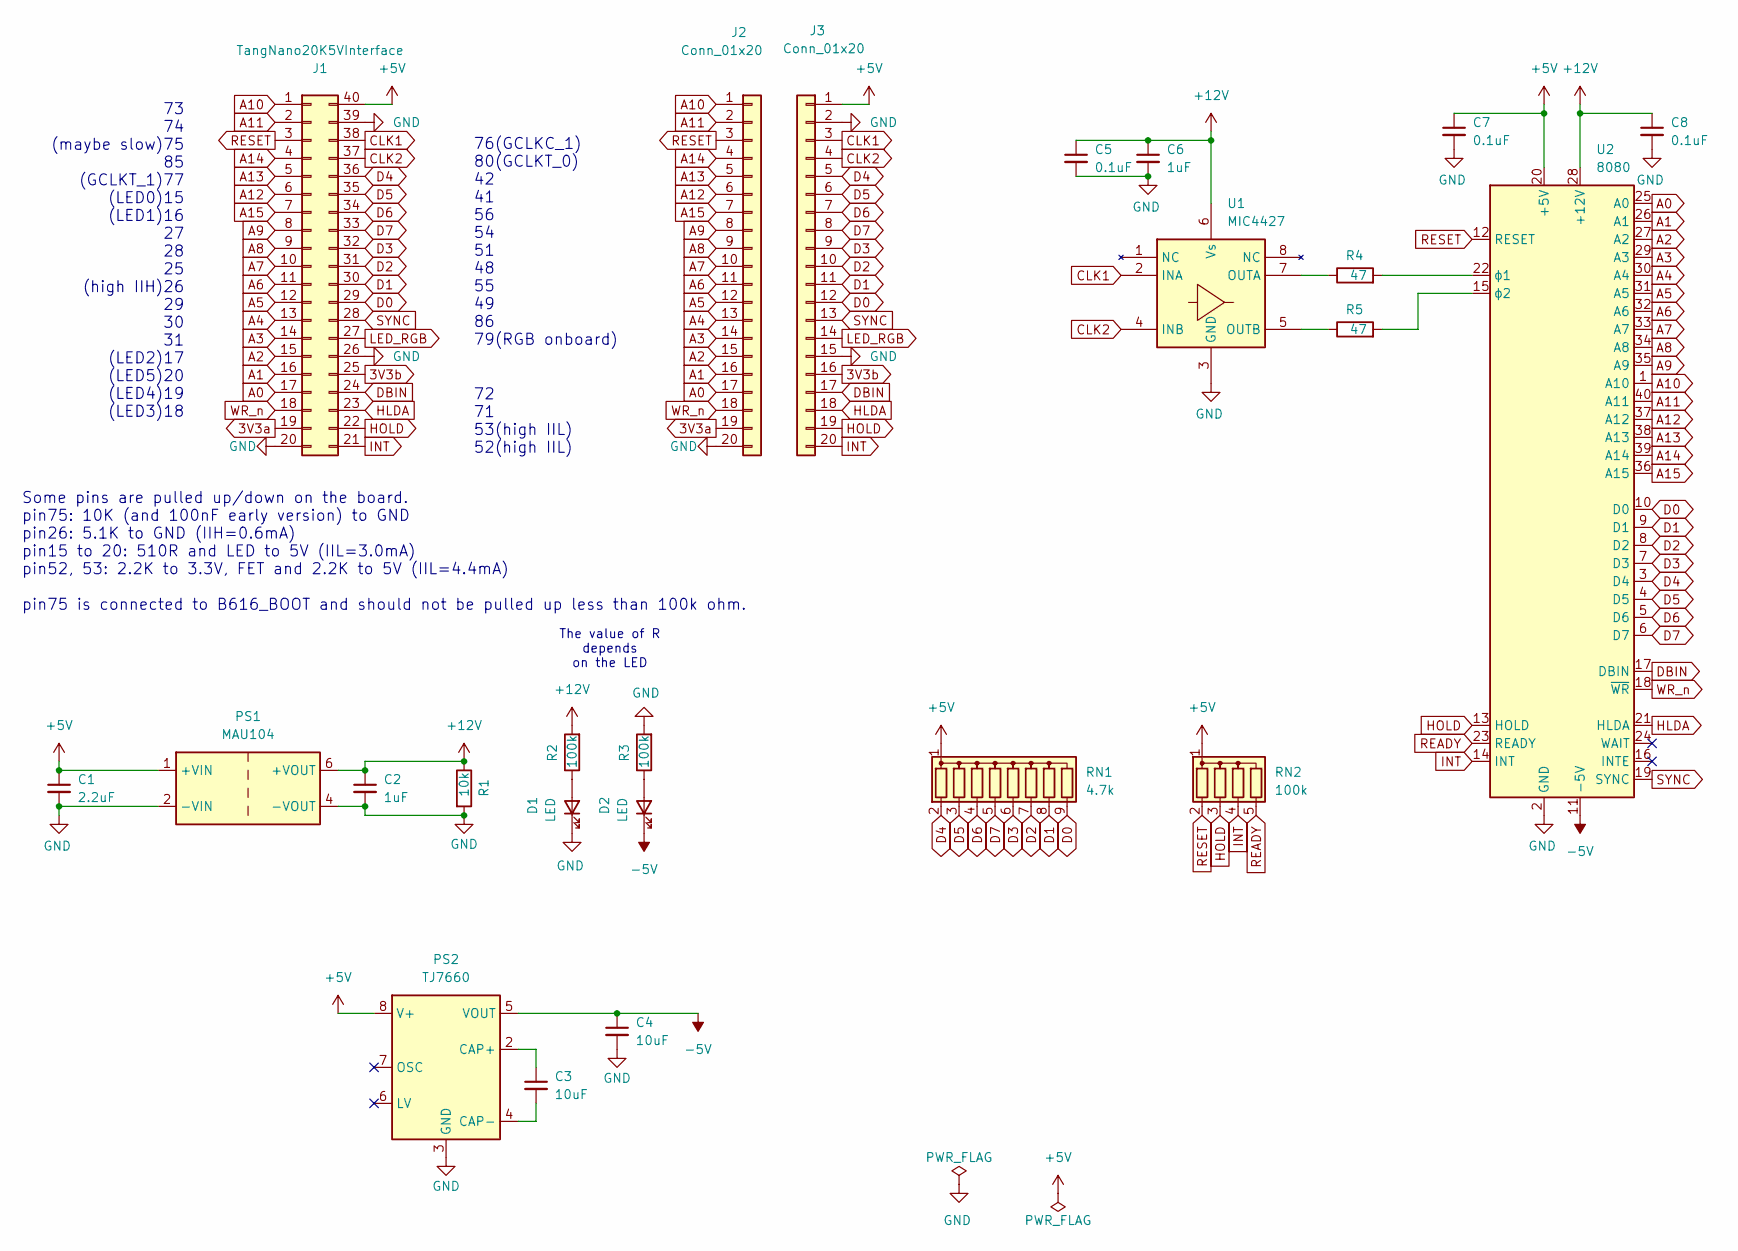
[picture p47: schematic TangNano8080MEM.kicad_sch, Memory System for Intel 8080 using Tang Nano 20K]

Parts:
C1: 2.2uF; C_Disc_D4.7mm_W2.5mm_P5.00mm
C2, C6: 1uF; C_Disc_D4.7mm_W2.5mm_P5.00mm
C3, C4: 10uF; C_Disc_D4.7mm_W2.5mm_P5.00mm
C5, C7, C8: 0.1uF; C_Disc_D5.0mm_W2.5mm_P2.50mm
D1, D2: LED; LED_D3.0mm
J1: TangNano20K5VInterface; DIP-40_W15.24mm_Socket
J2, J3: Conn_01x20; PinSocket_1x20_P2.54mm_Vertical
PS1: MAU104; SIP-6_without_3_5pin_for_DCDC_MAU
PS2: TJ7660; DIP-8_W7.62mm
R1: 10k; R_Axial_DIN0207_L6.3mm_D2.5mm_P7.62mm_Horizontal
R2, R3: 100k; R_Axial_DIN0207_L6.3mm_D2.5mm_P7.62mm_Horizontal
R4, R5: 47; R_Axial_DIN0207_L6.3mm_D2.5mm_P7.62mm_Horizontal
RN1: 4.7k; R_Array_SIP9
RN2: 100k; R_Array_SIP5
U1: MIC4427; DIP-8_W7.62mm
U2: 8080; DIP_Socket-40_W11.9_W12.7_W15.24_W17.78_W18.5_3M_240-1280-0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

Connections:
3V3a: J1.19, J2.19
3V3b: J1.25, J3.16
+5V: C1.1, C7.1, J1.40, J3.1, PS1.1 (+VIN), PS2.8 (V+), RN1.1 (common), RN2.1 (common), U2.20 (+5V)
+12V: C2.1, C5.1, C6.1, C8.1, PS1.6 (+VOUT), R1.1, R2.2, U1.6 (Vs), U2.28 (+12V)
-5V: C4.1, D2.1 (K), PS2.5 (VOUT), U2.11 (-5V)
A0: J1.17, J2.17, U2.25 (A0)
A1: J1.16, J2.16, U2.26 (A1)
A2: J1.15, J2.15, U2.27 (A2)
A3: J1.14, J2.14, U2.29 (A3)
A4: J1.13, J2.13, U2.30 (A4)
A5: J1.12, J2.12, U2.31 (A5)
A6: J1.11, J2.11, U2.32 (A6)
A7: J1.10, J2.10, U2.33 (A7)
A8: J1.9, J2.9, U2.34 (A8)
A9: J1.8, J2.8, U2.35 (A9)
A10: J1.1, J2.1, U2.1 (A10)
A11: J1.2, J2.2, U2.40 (A11)
A12: J1.6, J2.6, U2.37 (A12)
A13: J1.5, J2.5, U2.38 (A13)
A14: J1.4, J2.4, U2.39 (A14)
A15: J1.7, J2.7, U2.36 (A15)
CLK1: J1.38, J3.3, U1.2 (INA)
CLK2: J1.37, J3.4, U1.4 (INB)
D0: J1.29, J3.12, RN1.9 (R8), U2.10 (D0)
D1: J1.30, J3.11, RN1.8 (R7), U2.9 (D1)
D2: J1.31, J3.10, RN1.7 (R6), U2.8 (D2)
D3: J1.32, J3.9, RN1.6 (R5), U2.7 (D3)
D4: J1.36, J3.5, RN1.2 (R1), U2.3 (D4)
D5: J1.35, J3.6, RN1.3 (R2), U2.4 (D5)
D6: J1.34, J3.7, RN1.4 (R3), U2.5 (D6)
D7: J1.33, J3.8, RN1.5 (R4), U2.6 (D7)
DBIN: J1.24, J3.17, U2.17 (DBIN)
GND: C1.2, C2.2, C4.2, C5.2, C6.2, C7.2, C8.2, D1.1 (K), J1.20, J1.26, J1.39, J2.20, J3.2, J3.15, PS1.2 (-VIN), PS1.4 (-VOUT), PS2.3 (GND), R1.2, R3.2, U1.3 (GND), U2.2 (GND)
HLDA: J1.23, J3.18, U2.21 (HLDA)
HOLD: J1.22, J3.19, RN2.3 (R2), U2.13 (HOLD)
INT: J1.21, J3.20, RN2.4 (R3), U2.14 (INT)
LED_RGB: J1.27, J3.14
unnamed: D1.2 (A), R2.1
unnamed: D2.2 (A), R3.1
unnamed: C3.1, PS2.2 (CAP+)
unnamed: C3.2, PS2.4 (CAP-)
unnamed: R4.1, U1.7 (OUTA)
unnamed: R5.1, U1.5 (OUTB)
unnamed: R4.2, U2.22 (ϕ1)
unnamed: R5.2, U2.15 (ϕ2)
READY: RN2.5 (R4), U2.23 (READY)
RESET: J1.3, J2.3, RN2.2 (R1), U2.12 (RESET)
SYNC: J1.28, J3.13, U2.19 (SYNC)
WR_n: J1.18, J2.18, U2.18 (~WR)

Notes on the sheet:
72 71 53(high IIL) 52(high IIL)
73 74 (maybe slow)75 85 (GCLKT_1)77 (LED0)15 (LED1)16 27 28 25 (high IIH)26 29 30 31 (LED2)17 (LED5)20 (LED4)19 (LED3)18
76(GCLKC_1) 80(GCLKT_0) 42 41 56 54 51 48 55 49 86 79(RGB onboard)
Some pins are pulled up/down on the board. pin75: 10K (and 100nF early version) to GND pin26: 5.1K to GND (IIH=0.6mA) pin15 to 20: 510R and LED to 5V (IIL=3.0mA) pin52, 53: 2.2K to 3.3V, FET and 2.2K to 5V (IIL=4.4mA) pin75 is connected to B616_BOOT and should not be pulled up less than 100k ohm.
The value of R depends on the LED

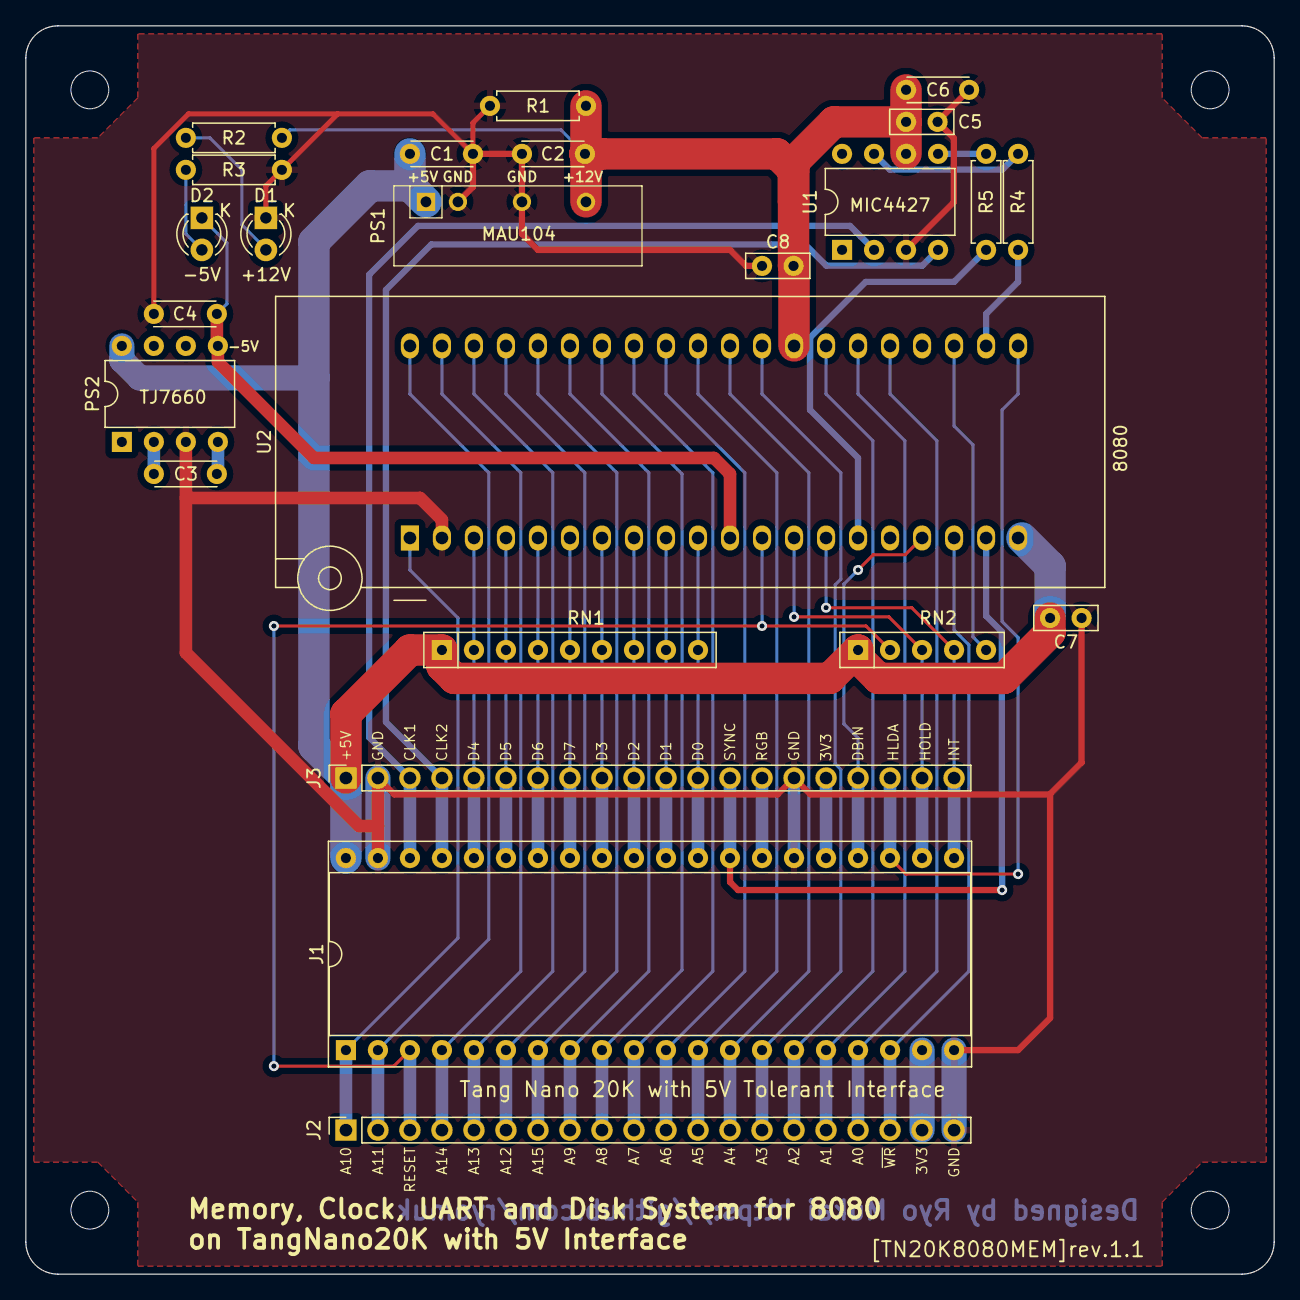
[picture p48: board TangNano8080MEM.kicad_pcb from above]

Board: 2 copper layers, 99.1 x 99.1 mm, 24 parts (0 on the bottom side), 49 nets.

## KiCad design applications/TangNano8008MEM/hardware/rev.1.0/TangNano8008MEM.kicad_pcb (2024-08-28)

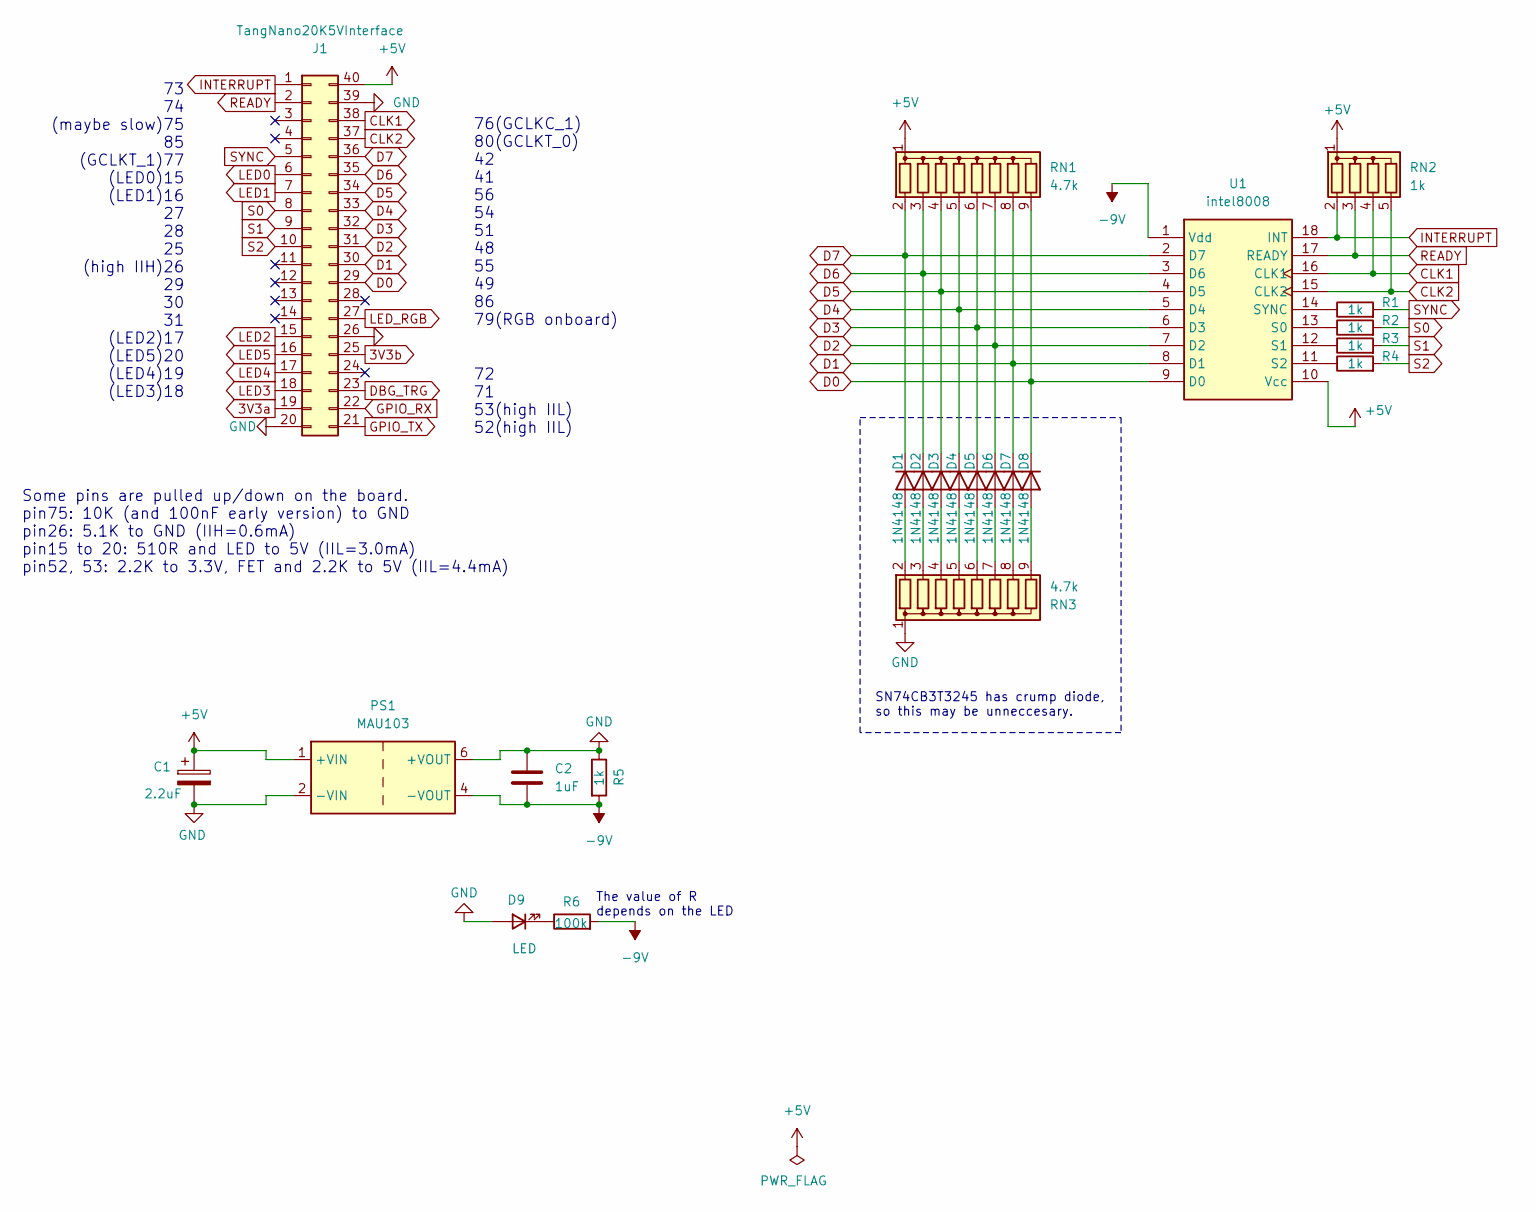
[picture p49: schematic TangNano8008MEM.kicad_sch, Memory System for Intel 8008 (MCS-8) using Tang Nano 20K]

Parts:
C1: 2.2uF; CP_Radial_D5.0mm_P2.00mm
C2: 1uF; C_Disc_D4.7mm_W2.5mm_P5.00mm
D1, D2, D3, D4, D5, D6, D7, D8: 1N4148; D_DO-35_SOD27_P2.54mm_Vertical_KathodeUp
D9: LED; LED_D3.0mm
J1: TangNano20K5VInterface; DIP-40_W15.24mm_Socket
PS1: MAU103; SIP-6_without_3_5pin_for_DCDC_MAU
R1, R2, R3, R4, R5: 1k; R_Axial_DIN0207_L6.3mm_D2.5mm_P7.62mm_Horizontal
R6: 100k; R_Axial_DIN0207_L6.3mm_D2.5mm_P7.62mm_Horizontal
RN1, RN3: 4.7k; R_Array_SIP9
RN2: 1k; R_Array_SIP5
U1: intel8008; DIP_Socket-18_W4.3_W5.08_W7.62_W10.16_W10.9_3M_218-3341-00-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

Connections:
3V3a: J1.19
3V3b: J1.25
+5V: C1.1, J1.40, PS1.1 (+VIN), RN1.1 (common), RN2.1 (common), U1.10 (Vcc)
-9V: C2.2, PS1.4 (-VOUT), R5.2, R6.2, U1.1 (Vdd)
CLK1: J1.38, RN2.4 (R3), U1.16 (CLK1)
CLK2: J1.37, RN2.5 (R4), U1.15 (CLK2)
D0: D8.1 (K), J1.29, RN1.9 (R8), U1.9 (D0)
D1: D7.1 (K), J1.30, RN1.8 (R7), U1.8 (D1)
D2: D6.1 (K), J1.31, RN1.7 (R6), U1.7 (D2)
D3: D5.1 (K), J1.32, RN1.6 (R5), U1.6 (D3)
D4: D4.1 (K), J1.33, RN1.5 (R4), U1.5 (D4)
D5: D3.1 (K), J1.34, RN1.4 (R3), U1.4 (D5)
D6: D2.1 (K), J1.35, RN1.3 (R2), U1.3 (D6)
D7: D1.1 (K), J1.36, RN1.2 (R1), U1.2 (D7)
DBG_TRG: J1.23
GND: C1.2, C2.1, D9.2 (A), J1.20, J1.26, J1.39, PS1.2 (-VIN), PS1.6 (+VOUT), R5.1, RN3.1 (common)
GPIO_RX: J1.22
GPIO_TX: J1.21
INTERRUPT: J1.1, RN2.2 (R1), U1.18 (INT)
LED0: J1.6
LED1: J1.7
LED2: J1.15
LED3: J1.18
LED4: J1.17
LED5: J1.16
LED_RGB: J1.27
unnamed: D1.2 (A), RN3.2 (R1)
unnamed: D2.2 (A), RN3.3 (R2)
unnamed: D3.2 (A), RN3.4 (R3)
unnamed: D4.2 (A), RN3.5 (R4)
unnamed: D5.2 (A), RN3.6 (R5)
unnamed: D6.2 (A), RN3.7 (R6)
unnamed: D7.2 (A), RN3.8 (R7)
unnamed: D8.2 (A), RN3.9 (R8)
unnamed: D9.1 (K), R6.1
unnamed: R2.1, U1.13 (S0)
unnamed: R3.1, U1.12 (S1)
unnamed: R4.1, U1.11 (S2)
unnamed: R1.1, U1.14 (SYNC)
READY: J1.2, RN2.3 (R2), U1.17 (READY)
S0: J1.8, R2.2
S1: J1.9, R3.2
S2: J1.10, R4.2
SYNC: J1.5, R1.2

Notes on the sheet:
SN74CB3T3245 has crump diode, so this may be unneccesary.
72 71 53(high IIL) 52(high IIL)
73 74 (maybe slow)75 85 (GCLKT_1)77 (LED0)15 (LED1)16 27 28 25 (high IIH)26 29 30 31 (LED2)17 (LED5)20 (LED4)19 (LED3)18
The value of R depends on the LED
76(GCLKC_1) 80(GCLKT_0) 42 41 56 54 51 48 55 49 86 79(RGB onboard)
Some pins are pulled up/down on the board. pin75: 10K (and 100nF early version) to GND pin26: 5.1K to GND (IIH=0.6mA) pin15 to 20: 510R and LED to 5V (IIL=3.0mA) pin52, 53: 2.2K to 3.3V, FET and 2.2K to 5V (IIL=4.4mA)

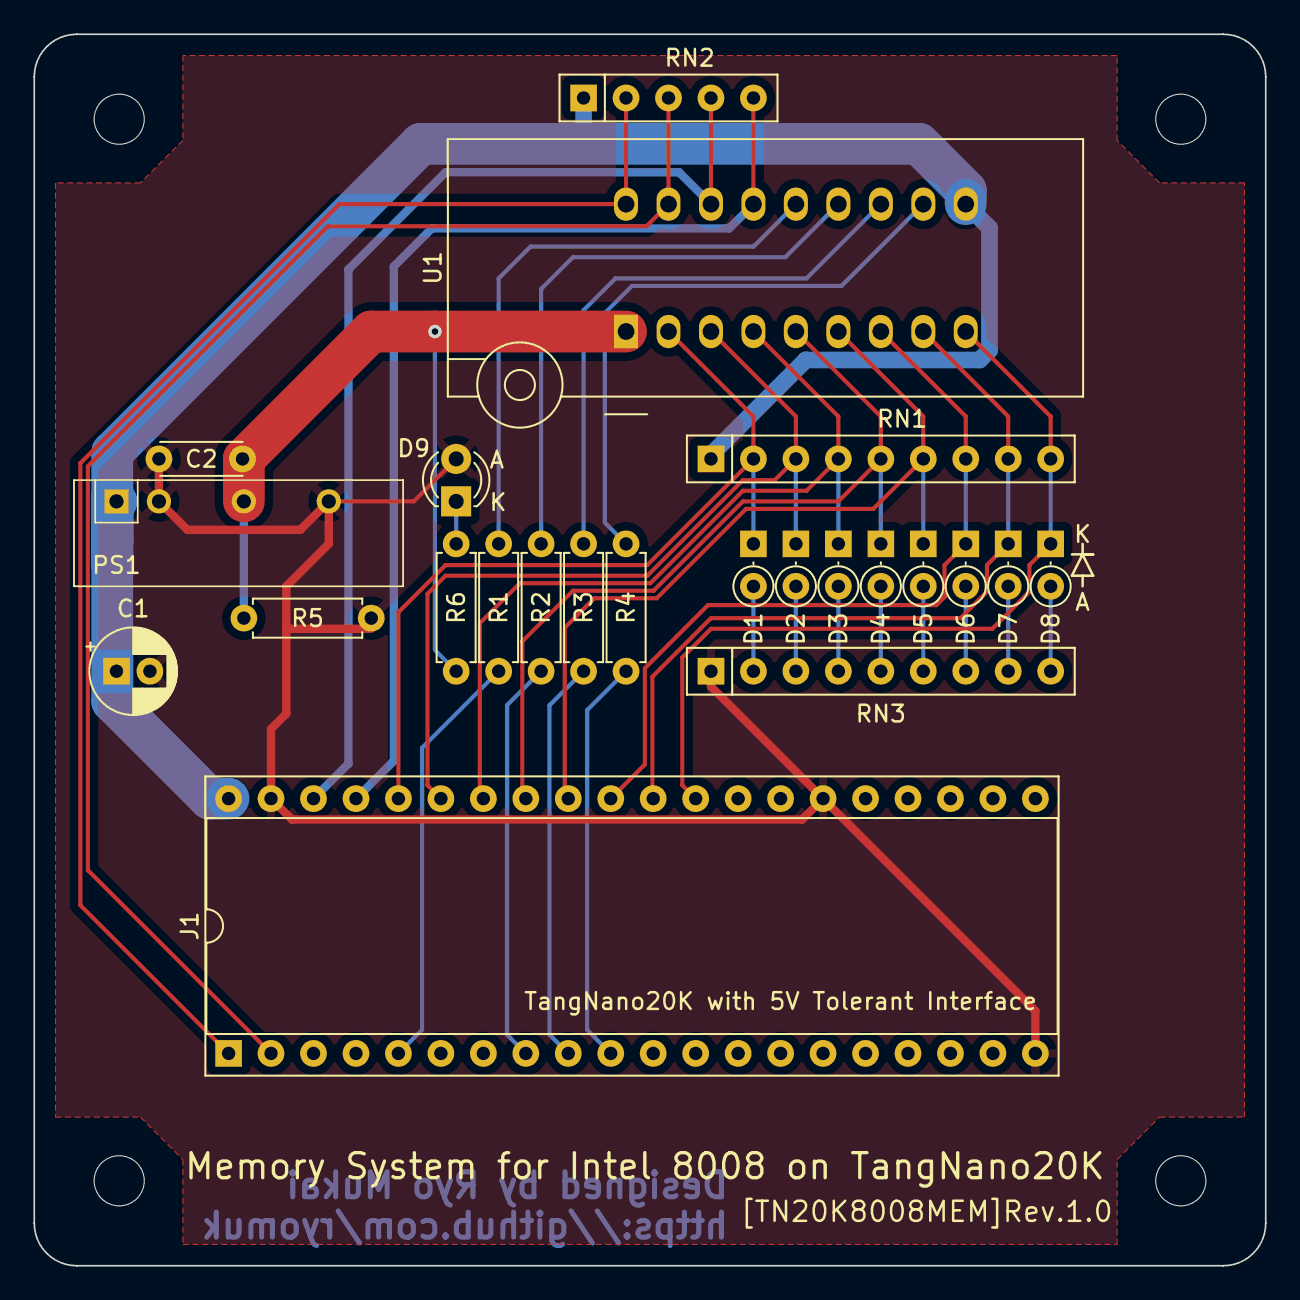
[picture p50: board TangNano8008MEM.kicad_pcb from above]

Board: 2 copper layers, 73.7 x 73.7 mm, 23 parts (0 on the bottom side), 32 nets.

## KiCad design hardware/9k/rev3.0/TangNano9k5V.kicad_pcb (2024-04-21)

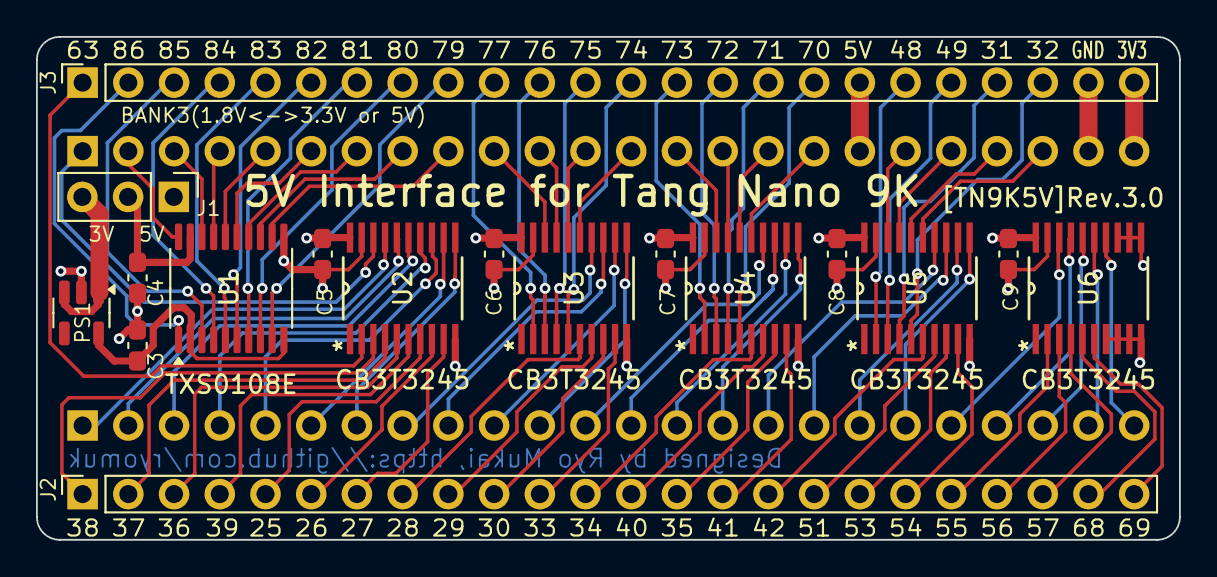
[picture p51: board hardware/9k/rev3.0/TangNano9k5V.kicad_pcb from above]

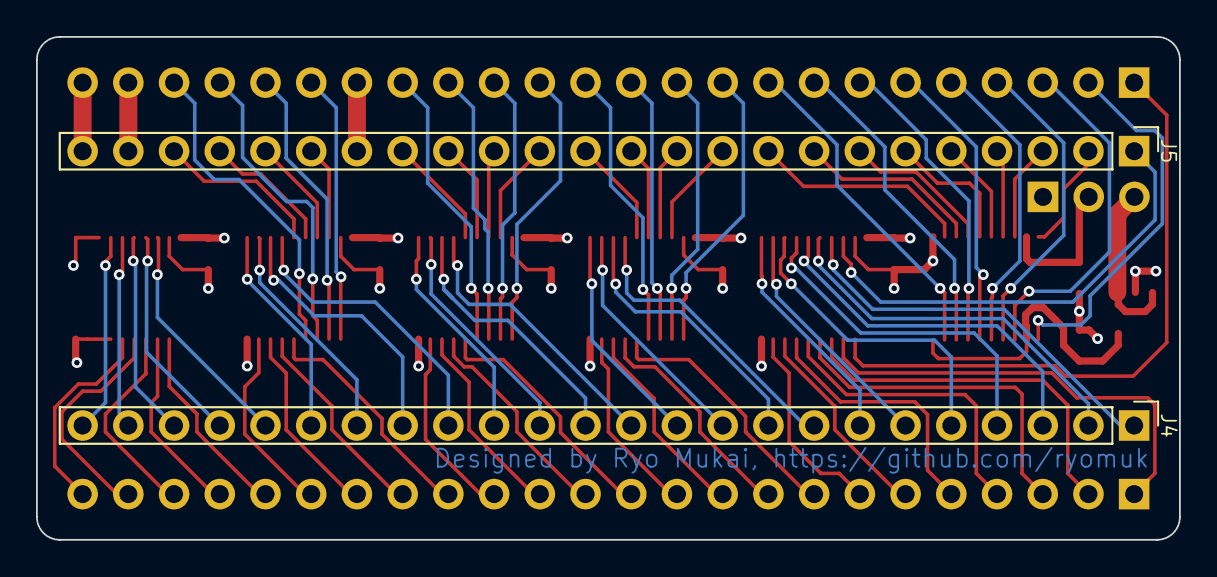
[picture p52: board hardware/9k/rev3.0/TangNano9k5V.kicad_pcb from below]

Board: 4 copper layers, 63.5 x 27.9 mm, 19 parts (2 on the bottom side), 95 nets.

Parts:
C3, C4, C5, C6, C7, C8, C9: 0.1uF; C_0603_1608Metric_Pad1.08x0.95mm_HandSolder
J1: VCCB; PinHeader_1x03_P2.54mm_Vertical
J2, J3: Conn_01x24; PinSocket_1x24_P2.54mm_Vertical
J4, J5: Conn_01x24; PinHeader_1x24_P2.54mm_Vertical
PS1: TLV71318_SOT23-5; SOT-23-5
U1: TXS0108E; TSSOP-20_4.4x6.5mm_P0.65mm
U2, U3, U4, U5, U6: CB3T3245; PW20

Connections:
+1V8: C3.1, PS1.5 (OUT), U1.2 (VCCA), U1.10 (OE)
+3.3V: C5.1, C6.1, C7.1, C8.1, C9.1, J1.3, J3.24, J5.24, PS1.1 (IN), PS1.3 (EN), U2.20 (VCC), U3.20 (VCC), U4.20 (VCC), U5.20 (VCC), U6.20 (VCC)
+5V: J1.1, J3.18, J5.18
GND: C3.2, C4.2, C5.2, C6.2, C7.2, C8.2, C9.2, J3.23, J5.23, PS1.2 (GND), U1.11 (GND), U2.10 (GND), U2.19 (*OE), U3.10 (GND), U3.19 (*OE), U4.10 (GND), U4.19 (*OE), U5.10 (GND), U5.19 (*OE), U6.7 (A6), U6.8 (A7), U6.9 (A8), U6.10 (GND), U6.11 (B8), U6.12 (B7), U6.13 (B6), U6.19 (*OE)
unnamed: C4.1, J1.2, U1.19 (VCCB)
PIN25: J2.5, U2.7 (A6)
PIN25_H: J4.5, U2.13 (B6)
PIN26: J2.6, U2.8 (A7)
PIN26_H: J4.6, U2.12 (B7)
PIN27: J2.7, U2.9 (A8)
PIN27_H: J4.7, U2.11 (B8)
PIN28: J2.8, U3.6 (A5)
PIN28_H: J4.8, U3.14 (B5)
PIN29: J2.9, U3.7 (A6)
PIN29_H: J4.9, U3.13 (B6)
PIN30: J2.10, U3.8 (A7)
PIN30_H: J4.10, U3.12 (B7)
PIN31: J3.21, U5.4 (A3)
PIN31_H: J5.21, U5.16 (B3)
PIN32: J3.22, U5.5 (A4)
PIN32_H: J5.22, U5.15 (B4)
PIN33: J2.11, U3.9 (A8)
PIN33_H: J4.11, U3.11 (B8)
PIN34: J2.12, U4.6 (A5)
PIN34_H: J4.12, U4.14 (B5)
PIN35: J2.14, U4.8 (A7)
PIN35_H: J4.14, U4.12 (B7)
PIN36: J2.3, U2.5 (A4)
PIN36_H: J4.3, U2.15 (B4)
PIN37: J2.2, U2.4 (A3)
PIN37_H: J4.2, U2.16 (B3)
PIN38: J2.1, U2.3 (A2)
PIN38_H: J4.1, U2.17 (B2)
PIN39: J2.4, U2.6 (A5)
PIN39_H: J4.4, U2.14 (B5)
PIN40: J2.13, U4.7 (A6)
PIN40_H: J4.13, U4.13 (B6)
PIN41: J2.15, U4.9 (A8)
PIN41_H: J4.15, U4.11 (B8)
PIN42: J2.16, U5.6 (A5)
PIN42_H: J4.16, U5.14 (B5)
PIN48: J3.19, U5.2 (A1)
PIN48_H: J5.19, U5.18 (B1)
PIN49: J3.20, U5.3 (A2)
PIN49_H: J5.20, U5.17 (B2)
PIN51: J2.17, U5.7 (A6)
PIN51_H: J4.17, U5.13 (B6)
PIN53: J2.18, U5.8 (A7)
PIN53_H: J4.18, U5.12 (B7)
PIN54: J2.19, U5.9 (A8)
PIN54_H: J4.19, U5.11 (B8)
PIN55: J2.20, U6.2 (A1)
PIN55_H: J4.20, U6.18 (B1)
PIN56: J2.21, U6.3 (A2)
PIN56_H: J4.21, U6.17 (B2)
PIN57: J2.22, U6.4 (A3)
PIN57_H: J4.22, U6.16 (B3)
PIN63: J3.1, U2.2 (A1)
PIN63_H: J5.1, U2.18 (B1)
PIN68: J2.23, U6.5 (A4)
PIN68_H: J4.23, U6.15 (B4)
PIN69: J2.24, U6.6 (A5)
PIN69_H: J4.24, U6.14 (B5)
PIN70: J3.17, U4.5 (A4)
PIN70_H: J5.17, U4.15 (B4)
PIN71: J3.16, U4.4 (A3)
PIN71_H: J5.16, U4.16 (B3)
PIN72: J3.15, U4.3 (A2)
PIN72_H: J5.15, U4.17 (B2)
PIN73: J3.14, U4.2 (A1)
PIN73_H: J5.14, U4.18 (B1)
PIN74: J3.13, U3.5 (A4)
PIN74_H: J5.13, U3.15 (B4)
PIN75: J3.12, U3.4 (A3)
PIN75_H: J5.12, U3.16 (B3)
PIN76: J3.11, U3.3 (A2)
PIN76_H: J5.11, U3.17 (B2)
PIN77: J3.10, U3.2 (A1)
PIN77_H: J5.10, U3.18 (B1)
PIN79: J3.9, U1.9 (A8)
PIN79_H: J5.9, U1.12 (B8)
PIN80: J3.8, U1.8 (A7)
PIN80_H: J5.8, U1.13 (B7)
PIN81: J3.7, U1.7 (A6)
PIN81_H: J5.7, U1.14 (B6)
PIN82: J3.6, U1.6 (A5)
PIN82_H: J5.6, U1.15 (B5)
PIN83: J3.5, U1.5 (A4)
PIN83_H: J5.5, U1.16 (B4)
PIN84: J3.4, U1.4 (A3)
PIN84_H: J5.4, U1.17 (B3)
PIN85: J3.3, U1.3 (A2)
PIN85_H: J5.3, U1.18 (B2)
PIN86: J3.2, U1.1 (A1)
PIN86_H: J5.2, U1.20 (B1)

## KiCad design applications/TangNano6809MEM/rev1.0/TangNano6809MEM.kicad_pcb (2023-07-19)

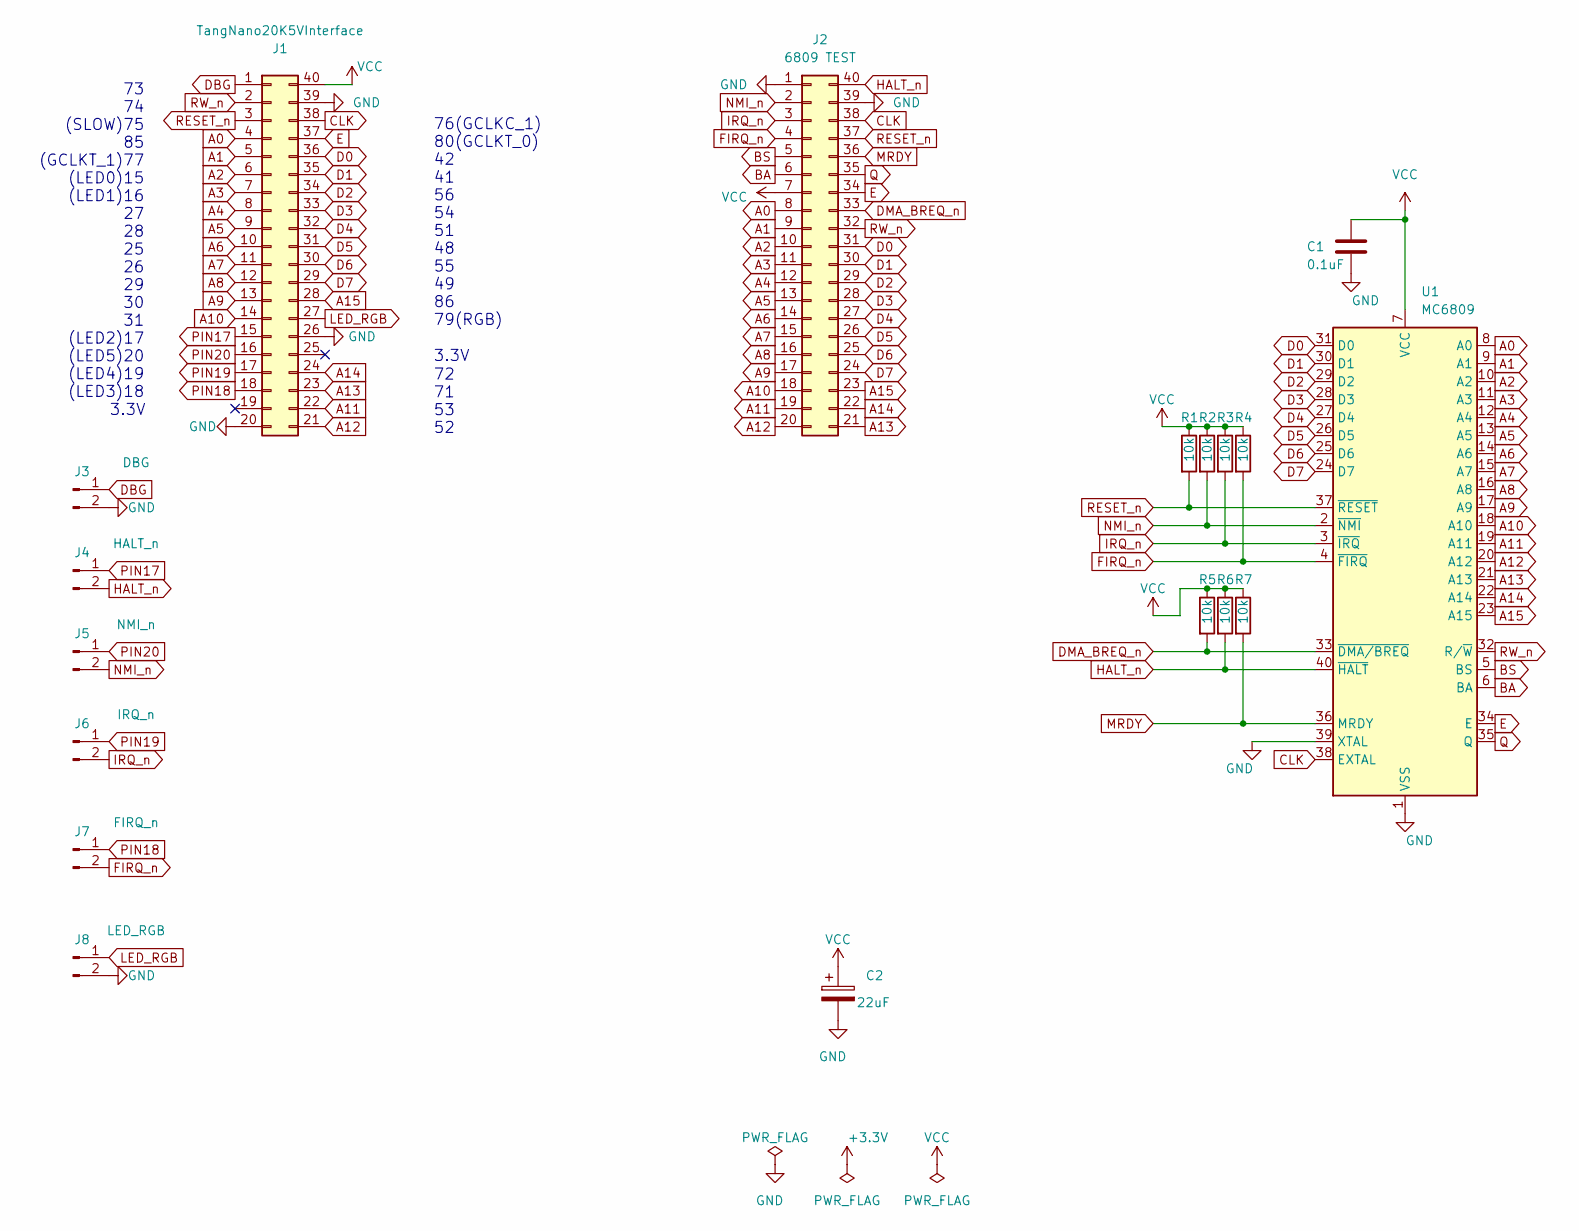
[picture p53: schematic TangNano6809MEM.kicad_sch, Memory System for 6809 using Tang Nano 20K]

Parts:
C1: 0.1uF; C_Disc_D4.3mm_W1.9mm_P5.00mm
C2: 22uF; CP_Radial_D4.0mm_P1.50mm
J1: TangNano20K5VInterface; DIP-40_W15.24mm_Socket
J2: 6809 TEST; DIP-40_W20.32mm800mil_Socket
J3: DBG; PinHeader_1x02_P2.54mm_Vertical
J4: HALT_n; PinHeader_1x02_P2.54mm_Vertical
J5: NMI_n; PinHeader_1x02_P2.54mm_Vertical
J6: IRQ_n; PinHeader_1x02_P2.54mm_Vertical
J7: FIRQ_n; PinHeader_1x02_P2.54mm_Vertical
J8: LED_RGB; PinHeader_1x02_P2.54mm_Vertical
R1, R2, R3, R4, R5, R6, R7: 10k; R_Axial_DIN0207_L6.3mm_D2.5mm_P7.62mm_Horizontal
U1: MC6809; DIP-40_W15.24mm

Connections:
A0: J1.4, J2.8, U1.8 (A0)
A1: J1.5, J2.9, U1.9 (A1)
A2: J1.6, J2.10, U1.10 (A2)
A3: J1.7, J2.11, U1.11 (A3)
A4: J1.8, J2.12, U1.12 (A4)
A5: J1.9, J2.13, U1.13 (A5)
A6: J1.10, J2.14, U1.14 (A6)
A7: J1.11, J2.15, U1.15 (A7)
A8: J1.12, J2.16, U1.16 (A8)
A9: J1.13, J2.17, U1.17 (A9)
A10: J1.14, J2.18, U1.18 (A10)
A11: J1.22, J2.19, U1.19 (A11)
A12: J1.21, J2.20, U1.20 (A12)
A13: J1.23, J2.21, U1.21 (A13)
A14: J1.24, J2.22, U1.22 (A14)
A15: J1.28, J2.23, U1.23 (A15)
BA: J2.6, U1.6 (BA)
BS: J2.5, U1.5 (BS)
CLK: J1.38, J2.38, U1.38 (EXTAL)
D0: J1.36, J2.31, U1.31 (D0)
D1: J1.35, J2.30, U1.30 (D1)
D2: J1.34, J2.29, U1.29 (D2)
D3: J1.33, J2.28, U1.28 (D3)
D4: J1.32, J2.27, U1.27 (D4)
D5: J1.31, J2.26, U1.26 (D5)
D6: J1.30, J2.25, U1.25 (D6)
D7: J1.29, J2.24, U1.24 (D7)
DBG: J1.1, J3.1
DMA_BREQ_n: J2.33, R5.2, U1.33 (~DMA/BREQ)
E: J1.37, J2.34, U1.34 (E)
FIRQ_n: J2.4, J7.2, R4.2, U1.4 (~FIRQ)
GND: C1.2, C2.2, J1.20, J1.26, J1.39, J2.1, J2.39, J3.2, J8.2, U1.1 (VSS), U1.39 (XTAL)
HALT_n: J2.40, J4.2, R6.2, U1.40 (~HALT)
IRQ_n: J2.3, J6.2, R3.2, U1.3 (~IRQ)
LED_RGB: J1.27, J8.1
MRDY: J2.36, R7.2, U1.36 (MRDY)
NMI_n: J2.2, J5.2, R2.2, U1.2 (~NMI)
PIN17: J1.15, J4.1
PIN18: J1.18, J7.1
PIN19: J1.17, J6.1
PIN20: J1.16, J5.1
Q: J2.35, U1.35 (Q)
RESET_n: J1.3, J2.37, R1.2, U1.37 (~RESET)
RW_n: J1.2, J2.32, U1.32 (R/~W)
VCC: C1.1, C2.1, J1.40, J2.7, R1.1, R2.1, R3.1, R4.1, R5.1, R6.1, R7.1, U1.7 (VCC)

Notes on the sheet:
72 71 53 52
73 74 (SLOW)75 85 (GCLKT_1)77 (LED0)15 (LED1)16 27 28 25 26 29 30 31 (LED2)17 (LED5)20 (LED4)19 (LED3)18
76(GCLKC_1) 80(GCLKT_0) 42 41 56 54 51 48 55 49 86 79(RGB)
3.3V

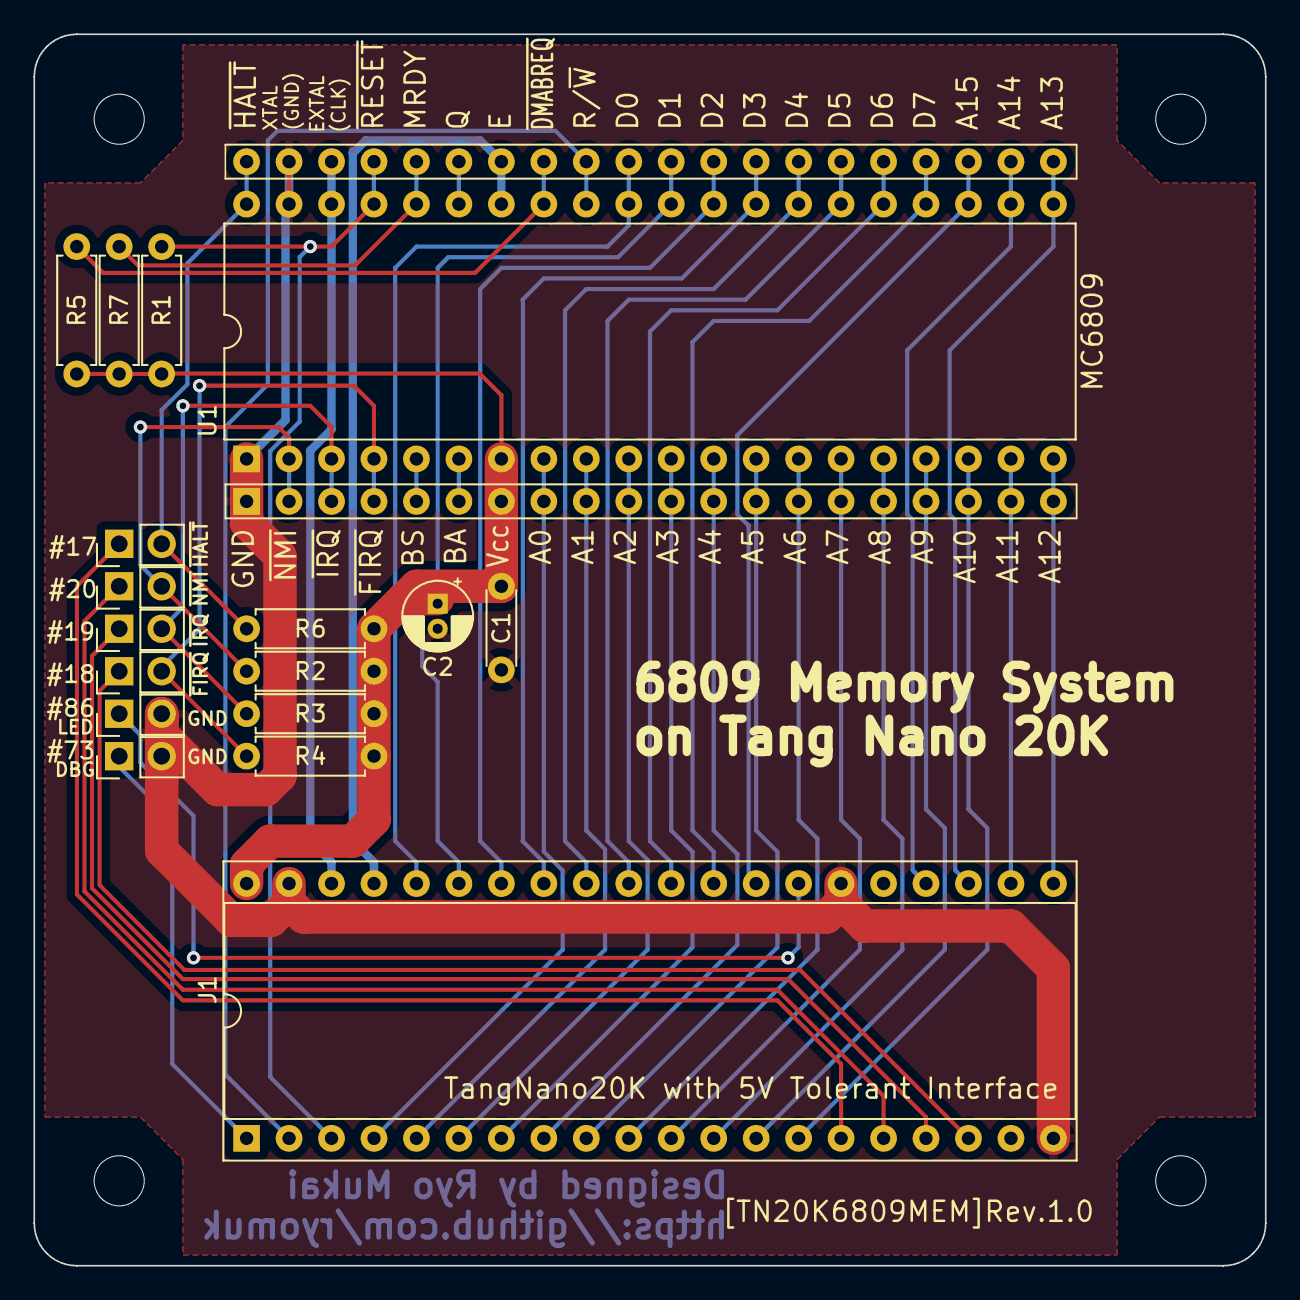
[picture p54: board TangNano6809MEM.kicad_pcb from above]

Board: 2 copper layers, 73.7 x 73.7 mm, 18 parts (0 on the bottom side), 45 nets.

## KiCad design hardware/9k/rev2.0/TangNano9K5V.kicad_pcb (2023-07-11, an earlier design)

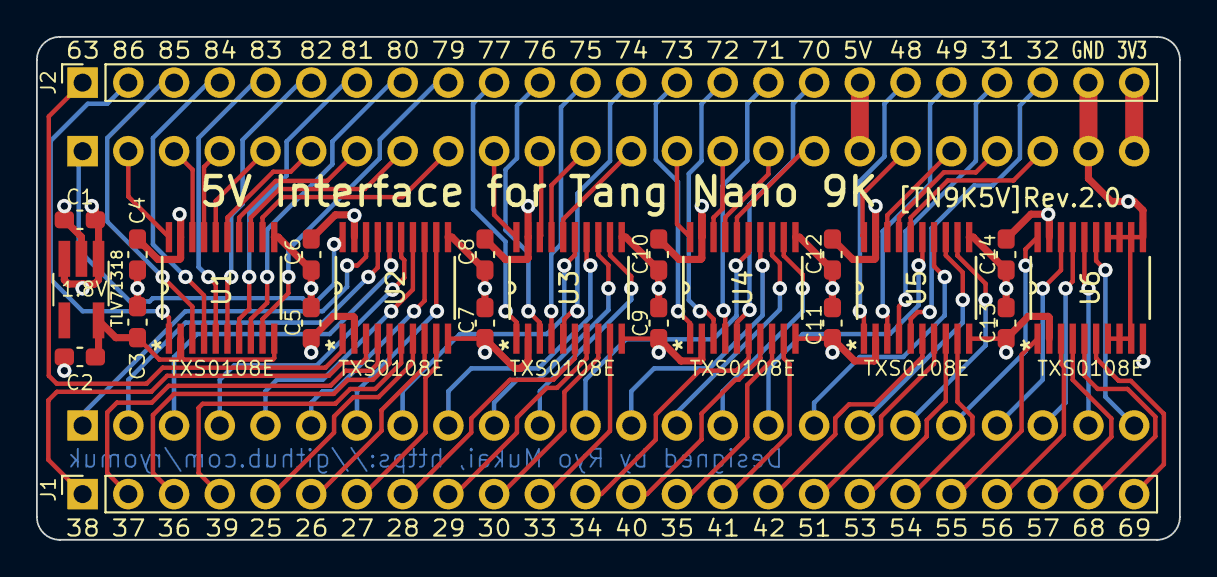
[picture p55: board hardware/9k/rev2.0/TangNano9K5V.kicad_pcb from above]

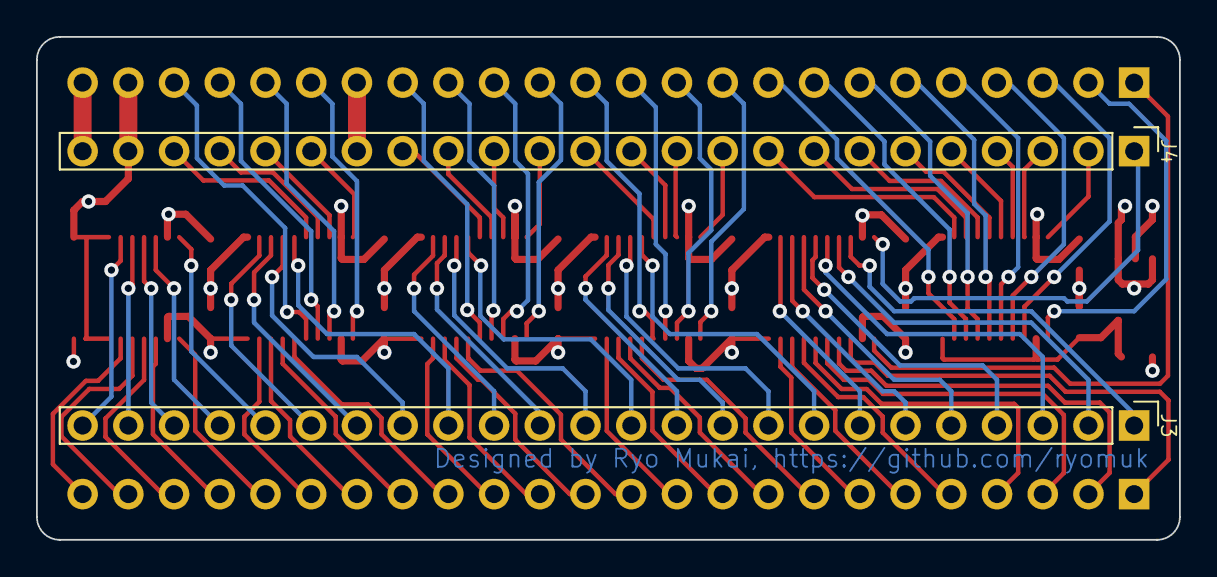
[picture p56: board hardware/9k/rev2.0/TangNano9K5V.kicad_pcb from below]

Board: 4 copper layers, 63.5 x 27.9 mm, 25 parts (2 on the bottom side), 94 nets.

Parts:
C1, C2: 0.1uF(optional); C_0603_1608Metric_Pad1.08x0.95mm_HandSolder
C3, C4, C5, C6, C7, C8, C9, C10, C11, C12, C13, C14: 0.1uF; C_0603_1608Metric_Pad1.08x0.95mm_HandSolder
J1, J2: Conn_01x24; PinSocket_1x24_P2.54mm_Vertical
J3, J4: Conn_01x24; PinHeader_1x24_P2.54mm_Vertical
PS1: TLV71318; TSOT-23-5_HandSoldering
U1, U2, U3, U4, U5, U6: TXS0108E; PW20

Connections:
+1V8: C2.1, C3.1, PS1.5 (OUT), U1.2 (VCCA), U1.10 (OE)
+3.3V: C1.1, C5.1, C7.1, C9.1, C11.1, C13.1, J2.24, J4.24, PS1.1 (IN), PS1.3 (EN), U2.2 (VCCA), U2.10 (OE), U3.2 (VCCA), U3.10 (OE), U4.2 (VCCA), U4.10 (OE), U5.2 (VCCA), U5.10 (OE), U6.2 (VCCA), U6.10 (OE)
+5V: C4.1, C6.1, C8.1, C10.1, C12.1, C14.1, J2.18, J4.18, U1.19 (VCCB), U2.19 (VCCB), U3.19 (VCCB), U4.19 (VCCB), U5.19 (VCCB), U6.19 (VCCB)
GND: C1.2, C2.2, C3.2, C4.2, C5.2, C6.2, C7.2, C8.2, C9.2, C10.2, C11.2, C12.2, C13.2, C14.2, J2.23, J4.23, PS1.2 (GND), U1.11 (GND), U2.11 (GND), U3.11 (GND), U4.11 (GND), U5.11 (GND), U6.7 (A6), U6.8 (A7), U6.9 (A8), U6.11 (GND), U6.12 (B8), U6.13 (B7), U6.14 (B6)
PIN25: J1.5, U2.7 (A6)
PIN25_H: J3.5, U2.14 (B6)
PIN26: J1.6, U2.8 (A7)
PIN26_H: J3.6, U2.13 (B7)
PIN27: J1.7, U2.9 (A8)
PIN27_H: J3.7, U2.12 (B8)
PIN28: J1.8, U3.6 (A5)
PIN28_H: J3.8, U3.15 (B5)
PIN29: J1.9, U3.7 (A6)
PIN29_H: J3.9, U3.14 (B6)
PIN30: J1.10, U3.8 (A7)
PIN30_H: J3.10, U3.13 (B7)
PIN31: J2.21, U5.4 (A3)
PIN31_H: J4.21, U5.17 (B3)
PIN32: J2.22, U5.5 (A4)
PIN32_H: J4.22, U5.16 (B4)
PIN33: J1.11, U3.9 (A8)
PIN33_H: J3.11, U3.12 (B8)
PIN34: J1.12, U4.6 (A5)
PIN34_H: J3.12, U4.15 (B5)
PIN35: J1.14, U4.8 (A7)
PIN35_H: J3.14, U4.13 (B7)
PIN36: J1.3, U2.5 (A4)
PIN36_H: J3.3, U2.16 (B4)
PIN37: J1.2, U2.4 (A3)
PIN37_H: J3.2, U2.17 (B3)
PIN38: J1.1, U2.3 (A2)
PIN38_H: J3.1, U2.18 (B2)
PIN39: J1.4, U2.6 (A5)
PIN39_H: J3.4, U2.15 (B5)
PIN40: J1.13, U4.7 (A6)
PIN40_H: J3.13, U4.14 (B6)
PIN41: J1.15, U4.9 (A8)
PIN41_H: J3.15, U4.12 (B8)
PIN42: J1.16, U5.6 (A5)
PIN42_H: J3.16, U5.15 (B5)
PIN48: J2.19, U5.1 (A1)
PIN48_H: J4.19, U5.20 (B1)
PIN49: J2.20, U5.3 (A2)
PIN49_H: J4.20, U5.18 (B2)
PIN51: J1.17, U5.7 (A6)
PIN51_H: J3.17, U5.14 (B6)
PIN53: J1.18, U5.8 (A7)
PIN53_H: J3.18, U5.13 (B7)
PIN54: J1.19, U5.9 (A8)
PIN54_H: J3.19, U5.12 (B8)
PIN55: J1.20, U6.1 (A1)
PIN55_H: J3.20, U6.20 (B1)
PIN56: J1.21, U6.3 (A2)
PIN56_H: J3.21, U6.18 (B2)
PIN57: J1.22, U6.4 (A3)
PIN57_H: J3.22, U6.17 (B3)
PIN63: J2.1, U2.1 (A1)
PIN63_H: J4.1, U2.20 (B1)
PIN68: J1.23, U6.5 (A4)
PIN68_H: J3.23, U6.16 (B4)
PIN69: J1.24, U6.6 (A5)
PIN69_H: J3.24, U6.15 (B5)
PIN70: J2.17, U4.5 (A4)
PIN70_H: J4.17, U4.16 (B4)
PIN71: J2.16, U4.4 (A3)
PIN71_H: J4.16, U4.17 (B3)
PIN72: J2.15, U4.3 (A2)
PIN72_H: J4.15, U4.18 (B2)
PIN73: J2.14, U4.1 (A1)
PIN73_H: J4.14, U4.20 (B1)
PIN74: J2.13, U3.5 (A4)
PIN74_H: J4.13, U3.16 (B4)
PIN75: J2.12, U3.4 (A3)
PIN75_H: J4.12, U3.17 (B3)
PIN76: J2.11, U3.3 (A2)
PIN76_H: J4.11, U3.18 (B2)
PIN77: J2.10, U3.1 (A1)
PIN77_H: J4.10, U3.20 (B1)
PIN79: J2.9, U1.9 (A8)
PIN79_H: J4.9, U1.12 (B8)
PIN80: J2.8, U1.8 (A7)
PIN80_H: J4.8, U1.13 (B7)
PIN81: J2.7, U1.7 (A6)
PIN81_H: J4.7, U1.14 (B6)
PIN82: J2.6, U1.6 (A5)
PIN82_H: J4.6, U1.15 (B5)
PIN83: J2.5, U1.5 (A4)
PIN83_H: J4.5, U1.16 (B4)
PIN84: J2.4, U1.4 (A3)
PIN84_H: J4.4, U1.17 (B3)
PIN85: J2.3, U1.3 (A2)
PIN85_H: J4.3, U1.18 (B2)
PIN86: J2.2, U1.1 (A1)
PIN86_H: J4.2, U1.20 (B1)

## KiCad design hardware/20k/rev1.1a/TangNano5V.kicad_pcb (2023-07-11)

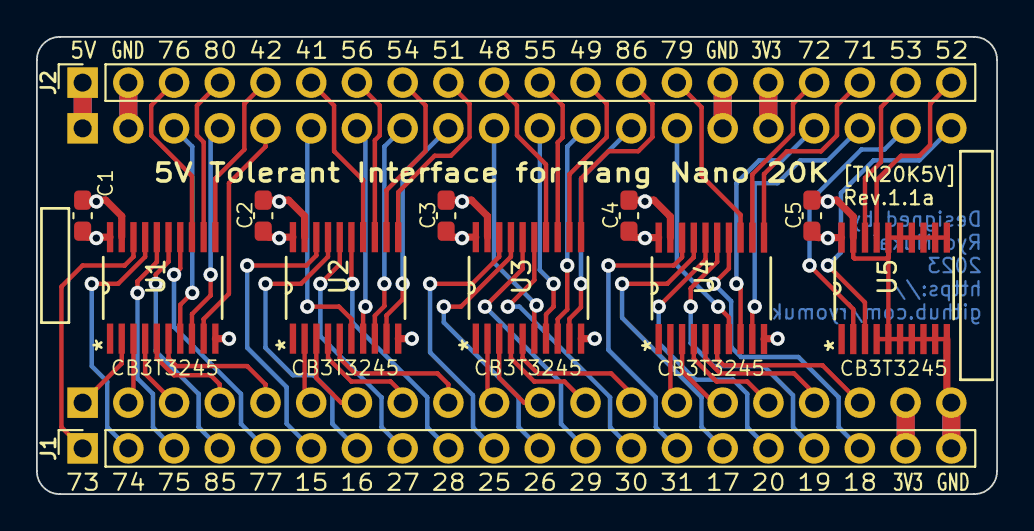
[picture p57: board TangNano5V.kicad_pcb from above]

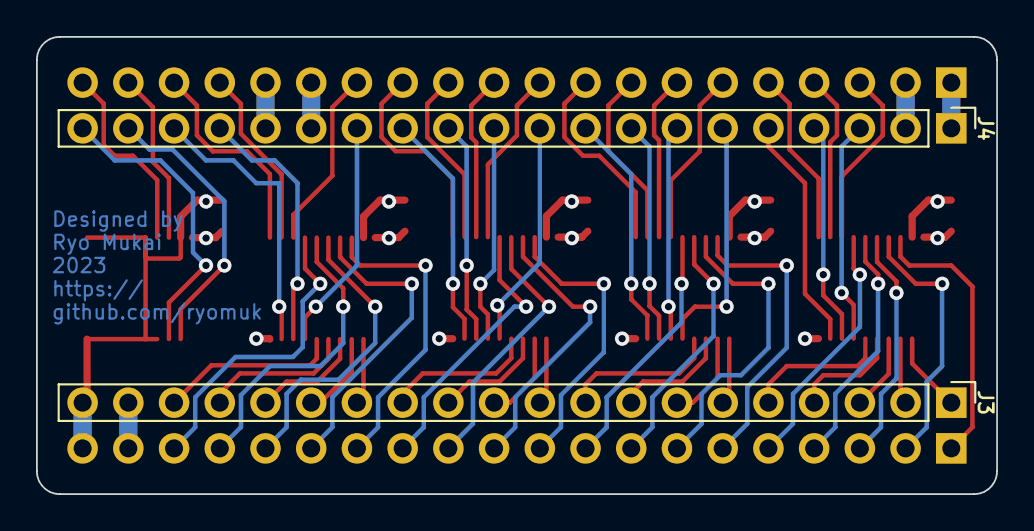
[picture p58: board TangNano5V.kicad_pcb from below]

Board: 4 copper layers, 53.3 x 25.4 mm, 14 parts (2 on the bottom side), 71 nets.

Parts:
C1, C2, C3, C4, C5: 0.1uF; C_0603_1608Metric_Pad1.08x0.95mm_HandSolder
J1, J2: TangNano20K; PinSocket_1x20_P2.54mm_Vertical
J3, J4: 5V interface; PinHeader_1x20_P2.54mm_Vertical
U1, U2, U3, U4, U5: CB3T3245; PW20

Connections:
+3.3V: C1.1, C2.1, C3.1, C4.1, C5.1, J1.19, J2.16, J3.19, J4.16, U1.20 (VCC), U2.20 (VCC), U3.20 (VCC), U4.20 (VCC), U5.20 (VCC)
+5V: J2.1, J4.1
GND: C1.2, C2.2, C3.2, C4.2, C5.2, J1.20, J2.2, J2.15, J3.20, J4.2, J4.15, U1.10 (GND), U1.19 (*OE), U2.10 (GND), U2.19 (*OE), U3.10 (GND), U3.19 (*OE), U4.10 (GND), U4.19 (*OE), U5.4 (A3), U5.5 (A4), U5.6 (A5), U5.7 (A6), U5.8 (A7), U5.9 (A8), U5.10 (GND), U5.11 (B8), U5.12 (B7), U5.13 (B6), U5.14 (B5), U5.15 (B4), U5.16 (B3), U5.19 (*OE)
PIN15: J1.6, U2.18 (B1)
PIN15_H: J3.6, U2.2 (A1)
PIN16: J1.7, U2.17 (B2)
PIN16_H: J3.7, U2.3 (A2)
PIN17: J1.15, U4.17 (B2)
PIN17_H: J3.15, U4.3 (A2)
PIN18: J1.18, U4.14 (B5)
PIN18_H: J3.18, U4.6 (A5)
PIN19: J1.17, U4.15 (B4)
PIN19_H: J3.17, U4.5 (A4)
PIN20: J1.16, U4.16 (B3)
PIN20_H: J3.16, U4.4 (A3)
PIN25: J1.10, U3.18 (B1)
PIN25_H: J3.10, U3.2 (A1)
PIN26: J1.11, U3.17 (B2)
PIN26_H: J3.11, U3.3 (A2)
PIN27: J1.8, U2.16 (B3)
PIN27_H: J3.8, U2.4 (A3)
PIN28: J1.9, U2.15 (B4)
PIN28_H: J3.9, U2.5 (A4)
PIN29: J1.12, U3.16 (B3)
PIN29_H: J3.12, U3.4 (A3)
PIN30: J1.13, U3.15 (B4)
PIN30_H: J3.13, U3.5 (A4)
PIN31: J1.14, U4.18 (B1)
PIN31_H: J3.14, U4.2 (A1)
PIN41: J2.6, U2.14 (B5)
PIN41_H: J4.6, U2.6 (A5)
PIN42: J2.5, U1.11 (B8)
PIN42_H: J4.5, U1.9 (A8)
PIN48: J2.10, U3.14 (B5)
PIN48_H: J4.10, U3.6 (A5)
PIN49: J2.12, U3.12 (B7)
PIN49_H: J4.12, U3.8 (A7)
PIN51: J2.9, U2.11 (B8)
PIN51_H: J4.9, U2.9 (A8)
PIN52: J2.20, U5.17 (B2)
PIN52_H: J4.20, U5.3 (A2)
PIN53: J2.19, U5.18 (B1)
PIN53_H: J4.19, U5.2 (A1)
PIN54: J2.8, U2.12 (B7)
PIN54_H: J4.8, U2.8 (A7)
PIN55: J2.11, U3.13 (B6)
PIN55_H: J4.11, U3.7 (A6)
PIN56: J2.7, U2.13 (B6)
PIN56_H: J4.7, U2.7 (A6)
PIN71: J2.18, U4.11 (B8)
PIN71_H: J4.18, U4.9 (A8)
PIN72: J2.17, U4.12 (B7)
PIN72_H: J4.17, U4.8 (A7)
PIN73: J1.1, U1.18 (B1)
PIN73_H: J3.1, U1.2 (A1)
PIN74: J1.2, U1.17 (B2)
PIN74_H: J3.2, U1.3 (A2)
PIN75: J1.3, U1.16 (B3)
PIN75_H: J3.3, U1.4 (A3)
PIN76: J2.3, U1.13 (B6)
PIN76_H: J4.3, U1.7 (A6)
PIN77: J1.5, U1.14 (B5)
PIN77_H: J3.5, U1.6 (A5)
PIN79: J2.14, U4.13 (B6)
PIN79_H: J4.14, U4.7 (A6)
PIN80: J2.4, U1.12 (B7)
PIN80_H: J4.4, U1.8 (A7)
PIN85: J1.4, U1.15 (B4)
PIN85_H: J3.4, U1.5 (A4)
PIN86: J2.13, U3.11 (B8)
PIN86_H: J4.13, U3.9 (A8)

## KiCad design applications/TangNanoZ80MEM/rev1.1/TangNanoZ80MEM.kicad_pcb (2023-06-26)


Board: 2 copper layers, 73.7 x 73.7 mm, 12 parts (0 on the bottom side), 46 nets.

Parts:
C1: 0.1uF; C_Disc_D4.3mm_W1.9mm_P5.00mm
C2: 22uF; CP_Radial_D4.0mm_P1.50mm
J1: Z80 TEST; DIP-40_W20.32mm800mil_Socket
J2: TangNano20K5VInterface; DIP-40_W15.24mm_Socket
J3: USE_USB_POWER; PinHeader_1x02_P2.54mm_Vertical
J4: GND; PinHeader_1x01_P2.54mm_Vertical
J5: DBG_TRG; PinHeader_1x02_P2.54mm_Vertical
J6: LED_RGB; PinHeader_1x02_P2.54mm_Vertical
R1: 33; R_Axial_DIN0207_L6.3mm_D2.5mm_P7.62mm_Horizontal
RN1: 10k; R_Array_SIP5
U1: Z80CPU; DIP-40_W15.24mm_Socket
U2: 74AHCT04; DIP-14_W7.62mm

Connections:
5V_USB: J2.40, J3.2
A0: J1.30, J2.17, U1.30 (A0)
A1: J1.31, J2.16, U1.31 (A1)
A2: J1.32, J2.15, U1.32 (A2)
A3: J1.33, J2.14, U1.33 (A3)
A4: J1.34, J2.13, U1.34 (A4)
A5: J1.35, J2.12, U1.35 (A5)
A6: J1.36, J2.11, U1.36 (A6)
A7: J1.37, J2.10, U1.37 (A7)
A8: J1.38, J2.9, U1.38 (A8)
A9: J1.39, J2.8, U1.39 (A9)
A10: J1.40, J2.7, U1.40 (A10)
A11: J1.1, J2.1, U1.1 (A11)
A12: J1.2, J2.2, U1.2 (A12)
A13: J1.3, J2.4, U1.3 (A13)
A14: J1.4, J2.5, U1.4 (A14)
A15: J1.5, J2.6, U1.5 (A15)
BUSACK_n: J1.23, U1.23 (~BUSACK)
BUSREQ_n: J1.25, RN1.3 (R2), U1.25 (~BUSRQ)
CLK: J1.6, R1.2, U1.6 (~CLK)
CLK_3V: J2.38, U2.1
D0: J1.14, J2.31, U1.14 (D0)
D1: J1.15, J2.30, U1.15 (D1)
D2: J1.12, J2.33, U1.12 (D2)
D3: J1.8, J2.36, U1.8 (D3)
D4: J1.7, J2.37, U1.7 (D4)
D5: J1.9, J2.35, U1.9 (D5)
D6: J1.10, J2.34, U1.10 (D6)
D7: J1.13, J2.32, U1.13 (D7)
DBG_TRG: J2.28, J5.1
GND: C1.2, C2.2, J1.29, J2.20, J2.26, J2.39, J4.1, J5.2, J6.2, U1.29 (GND), U2.5, U2.7 (GND)
HALT_n: J1.18, U1.18 (~HALT)
INT_n: J1.16, J2.18, U1.16 (~INT)
IORQ_n: J1.20, J2.23, U1.20 (~IORQ)
LED_RGB: J2.27, J6.1
M1_n: J1.27, J2.29, U1.27 (~M1)
MREQ_n: J1.19, J2.24, U1.19 (~MREQ)
NMI_n: J1.17, RN1.2 (R1), U1.17 (~NMI)
unnamed: R1.1, U2.4
unnamed: U2.2, U2.3
RD_n: J1.21, J2.21, U1.21 (~RD)
RESET_n: J1.26, J2.3, U1.26 (~RESET)
RFSH_n: J1.28, U1.28 (~RFSH)
VCC: C1.1, C2.1, J1.11, J3.1, RN1.1 (common), U1.11 (VCC), U2.9, U2.11, U2.13, U2.14 (VCC)
WAIT_n: J1.24, RN1.4 (R3), U1.24 (~WAIT)
WR_n: J1.22, J2.22, U1.22 (~WR)

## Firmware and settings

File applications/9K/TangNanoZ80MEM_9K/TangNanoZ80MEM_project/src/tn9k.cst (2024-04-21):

IO_LOC  "led[5]"    16; IO_PORT "led[5]" PULL_MODE=UP DRIVE=8;
IO_LOC  "led[4]"    15; IO_PORT "led[4]" PULL_MODE=UP DRIVE=8;
IO_LOC  "led[3]"    14; IO_PORT "led[3]" PULL_MODE=UP DRIVE=8;
IO_LOC  "led[2]"    13; IO_PORT "led[2]" PULL_MODE=UP DRIVE=8;
IO_LOC  "led[1]"    11; IO_PORT "led[1]" PULL_MODE=UP DRIVE=8;
IO_LOC  "led[0]"    10; IO_PORT "led[0]" PULL_MODE=UP DRIVE=8;
IO_LOC  "sw1_n"      4; IO_PORT "sw1_n" PULL_MODE=UP;
IO_LOC  "sw2_n"      3; IO_PORT "sw2_n" PULL_MODE=UP;
IO_LOC  "sys_clk"   52; IO_PORT "sys_clk" IO_TYPE=LVCMOS33 PULL_MODE=UP;

IO_LOC "uart_tx" 17; IO_PORT "uart_tx" IO_TYPE=LVCMOS33 PULL_MODE=UP;
IO_LOC "uart_rx" 18; IO_PORT "uart_rx" IO_TYPE=LVCMOS33 PULL_MODE=UP;

IO_LOC  "A[10]" 38; IO_PORT "A[10]" IO_TYPE=LVCMOS33 PULL_MODE=UP
IO_LOC  "A[9]" 37; IO_PORT "A[9]" IO_TYPE=LVCMOS33 PULL_MODE=UP
IO_LOC  "A[8]" 36; IO_PORT "A[8]" IO_TYPE=LVCMOS33 PULL_MODE=UP
IO_LOC  "A[7]" 39; IO_PORT "A[7]" IO_TYPE=LVCMOS33 PULL_MODE=UP
IO_LOC  "A[6]" 25; IO_PORT "A[6]" IO_TYPE=LVCMOS33 PULL_MODE=UP
IO_LOC  "A[5]" 26; IO_PORT "A[5]" IO_TYPE=LVCMOS33 PULL_MODE=UP
IO_LOC  "A[4]" 27; IO_PORT "A[4]" IO_TYPE=LVCMOS33 PULL_MODE=UP
IO_LOC  "A[3]" 28; IO_PORT "A[3]" IO_TYPE=LVCMOS33 PULL_MODE=UP
IO_LOC  "A[2]" 29; IO_PORT "A[2]" IO_TYPE=LVCMOS33 PULL_MODE=UP
IO_LOC  "A[1]" 30; IO_PORT "A[1]" IO_TYPE=LVCMOS33 PULL_MODE=UP
IO_LOC  "A[0]" 33; IO_PORT "A[0]" IO_TYPE=LVCMOS33 PULL_MODE=UP
//IO_LOC  "pin34" 34; IO_PORT "pin34" IO_TYPE=LVCMOS33 PULL_MODE=UP
//IO_LOC  "pin40" 40; IO_PORT "pin40" IO_TYPE=LVCMOS33 PULL_MODE=UP
//IO_LOC  "pin35" 35; IO_PORT "pin35" IO_TYPE=LVCMOS33 PULL_MODE=UP
//IO_LOC  "pin41" 41; IO_PORT "pin41" IO_TYPE=LVCMOS33 PULL_MODE=UP
//IO_LOC  "pin42" 42; IO_PORT "pin42" IO_TYPE=LVCMOS33 PULL_MODE=UP
//IO_LOC  "pin51" 51; IO_PORT "pin51" IO_TYPE=LVCMOS33 PULL_MODE=UP
//IO_LOC  "pin53" 53; IO_PORT "pin53" IO_TYPE=LVCMOS33 PULL_MODE=UP
//IO_LOC  "pin54" 54; IO_PORT "pin54" IO_TYPE=LVCMOS33 PULL_MODE=UP
IO_LOC  "D[6]" 34; IO_PORT "D[6]" IO_TYPE=LVCMOS33 PULL_MODE=UP
IO_LOC  "D[2]" 40; IO_PORT "D[2]" IO_TYPE=LVCMOS33 PULL_MODE=UP
IO_LOC  "D[7]" 35; IO_PORT "D[7]" IO_TYPE=LVCMOS33 PULL_MODE=UP
IO_LOC  "D[0]" 41; IO_PORT "D[0]" IO_TYPE=LVCMOS33 PULL_MODE=UP
IO_LOC  "D[1]" 42; IO_PORT "D[1]" IO_TYPE=LVCMOS33 PULL_MODE=UP
IO_LOC  "INT_n" 51; IO_PORT "INT_n" IO_TYPE=LVCMOS33 PULL_MODE=UP
//IO_LOC  "MREQ_n" 55; IO_PORT "MREQ_n" IO_TYPE=LVCMOS33 PULL_MODE=UP
//IO_LOC  "IORQ_n" 56; IO_PORT "IORQ_n" IO_TYPE=LVCMOS33 PULL_MODE=UP
//IO_LOC  "pin55" 55; IO_PORT "pin55" IO_TYPE=LVCMOS33 PULL_MODE=UP
//IO_LOC  "pin56" 56; IO_PORT "pin56" IO_TYPE=LVCMOS33 PULL_MODE=UP
IO_LOC  "DBG_TX[1]" 57; IO_PORT "DBG_TX[1]" IO_TYPE=LVCMOS33 PULL_MODE=UP
IO_LOC  "DBG_TX[0]" 68; IO_PORT "DBG_TX[0]" IO_TYPE=LVCMOS33 PULL_MODE=UP
IO_LOC  "DBG_TRG" 69; IO_PORT "DBG_TRG" IO_TYPE=LVCMOS33 PULL_MODE=UP

IO_LOC  "A[11]" 63; IO_PORT "A[11]" IO_TYPE=LVCMOS33 PULL_MODE=UP
IO_LOC  "A[12]" 86; IO_PORT "A[12]" IO_TYPE=LVCMOS18 PULL_MODE=UP
IO_LOC  "A[13]" 85; IO_PORT "A[13]" IO_TYPE=LVCMOS18 PULL_MODE=UP
IO_LOC  "A[14]" 84; IO_PORT "A[14]" IO_TYPE=LVCMOS18 PULL_MODE=UP
IO_LOC  "A[15]" 83; IO_PORT "A[15]" IO_TYPE=LVCMOS18 PULL_MODE=UP
IO_LOC  "CLK" 82; IO_PORT "CLK" IO_TYPE=LVCMOS18 PULL_MODE=UP
IO_LOC  "D[4]" 81; IO_PORT "D[4]" IO_TYPE=LVCMOS18 PULL_MODE=UP
IO_LOC  "D[3]" 80; IO_PORT "D[3]" IO_TYPE=LVCMOS18 PULL_MODE=UP
IO_LOC  "D[5]" 79; IO_PORT "D[5]" IO_TYPE=LVCMOS18 PULL_MODE=UP
//IO_LOC  "D[6]" 77; IO_PORT "D[6]" IO_TYPE=LVCMOS33 PULL_MODE=UP
//IO_LOC  "D[2]" 76; IO_PORT "D[2]" IO_TYPE=LVCMOS33 PULL_MODE=UP
//IO_LOC  "D[7]" 75; IO_PORT "D[7]" IO_TYPE=LVCMOS33 PULL_MODE=UP
//IO_LOC  "D[0]" 74; IO_PORT "D[0]" IO_TYPE=LVCMOS33 PULL_MODE=UP
//IO_LOC  "D[1]" 73; IO_PORT "D[1]" IO_TYPE=LVCMOS33 PULL_MODE=UP
//IO_LOC  "INT_n" 72; IO_PORT "INT_n" IO_TYPE=LVCMOS33 PULL_MODE=UP
IO_LOC  "MREQ_n" 71; IO_PORT "MREQ_n" IO_TYPE=LVCMOS33 PULL_MODE=UP
IO_LOC  "IORQ_n" 70; IO_PORT "IORQ_n" IO_TYPE=LVCMOS33 PULL_MODE=UP
IO_LOC  "M1_n" 48; IO_PORT "M1_n" IO_TYPE=LVCMOS33 PULL_MODE=UP
IO_LOC  "RESET_n" 49; IO_PORT "RESET_n" IO_TYPE=LVCMOS33 PULL_MODE=UP
IO_LOC  "WR_n" 31; IO_PORT "WR_n" IO_TYPE=LVCMOS33 PULL_MODE=UP
IO_LOC  "RD_n" 32; IO_PORT "RD_n" IO_TYPE=LVCMOS33 PULL_MODE=UP

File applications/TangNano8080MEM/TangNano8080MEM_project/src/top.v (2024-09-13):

//---------------------------------------------------------------------------
// Tang Nano 20K 8080 Memory for CP/M
// Memory System for 8080 using Tang Nano 20K
// with floppy/hard disk emulator using SD memory card
//
// by Ryo Mukai
// 2023/07/06
//  - initial version
// 2024/04/07
//  - some port names for uart.v changed
//  - default clock changed to USE_DIV_CLK(13.5MHz)
// 2024/04/17
//  - bug fix (memory write timing)
//  - indicate state of UART and heartbeat on RGB LED
//  - rx_data_ready in IOADDR_UART_CTRL moved from bit1 to bit0
// 2024/04/27
//  - tx_send timing fixed for fast CPU clock
// 2024/07/23
//  - implemented some features for CP/M
// 2024/09/08
//  - ported from Z80 Memory for CP/M and 8008MEM
// 2024/09/13
//  - modified status decoding style Z80 to 8080
//  - modified memory write timing
//---------------------------------------------------------------------------

// select one of the following 2 applications
`define USE_CPM
//`define USE_UNIMON

// select one of the following CLK frequency
//`define  CLK_3MHz     // 3.0MHz(333ns)
`define  CLK_2MHz   // 2.077MHz( 481ns)
//`define  CLK_1MHz   // 1.038MHz( 963ns)
//`define  CLK_500kHz // 519.2KHz(1930ns)

// for CP/M
`ifdef  USE_CPM
 `define UART_CPM
 `define USE_IPL
`endif

// for universal monitor
`ifdef  USE_UNIMON
 `define UART_8251
`endif

module top(
    input	 sw1,
    input	 sw2,
    input	 sys_clk, // 27MHz system clock
    input	 usb_rx,
    output	 usb_tx,

    output	 sd_clk,
    output	 sd_mosi, 
    input	 sd_miso,
    output	 sd_cs_n,

    output	 CLK1,
    output	 CLK2,
    output	 RESET,
    output	 INT,
    output	 HOLD,

    input	 SYNC,
    input	 DBIN,
    input	 WR_n,
    input	 HLDA,

    input [15:0] A,
    inout [7:0]	 D,

    output	 LED_RGB
    );

  parameter	 SYSCLK_FRQ  = 27_000_000; //Hz
  
//  parameter	 UART_BPS    =        110; //Hz (needs appropriate serial IF)
//  parameter	 UART_BPS    =        300; //Hz (minimum speed of FT232)
//  parameter	 UART_BPS    =       1200; //Hz (minimum speed of TangNano USB)
//  parameter	 UART_BPS    =       9600; //Hz
//  parameter	 UART_BPS    =      38400; //Hz
  parameter	 UART_BPS    =     115200; //Hz

  wire		 uart_rx = usb_rx;
  wire		 uart_tx;
  assign	 usb_tx  = uart_tx;
 
//       I/O ports
//  parameter	 IOADDR_UART_DATA = 8'h00;
//  parameter	 IOADDR_UART_CTRL = 8'h01;

  parameter IOADDR_CONDAT  = 8'h00; // console data port
  parameter IOADDR_CONSTA  = 8'h01; // console status port
  
  parameter IOADDR_PRTSTA = 8'h02; // printer status port (not implemented)
  parameter IOADDR_PRTDAT = 8'h03; // printer data port   (not implemented)
  parameter IOADDR_AUXDAT = 8'h05; // auxiliary data port (not implemented)
  parameter IOADDR_FDCD   = 8'h0A; // fdc-port: # of drive
  parameter IOADDR_FDCT   = 8'h0B; // fdc-port: # of track
  parameter IOADDR_FDCS   = 8'h0C; // fdc-port: # of sector
  parameter IOADDR_FDCOP  = 8'h0D; // fdc-port: command
  parameter IOADDR_FDCST  = 8'h0E; // fdc-port: status
  parameter IOADDR_DMAL   = 8'h0F; // dma-port: dma address low
  parameter IOADDR_DMAH   = 8'h10; // dma-port: dma address high

  parameter FDCOP_READ  = 8'h00;
  parameter FDCOP_WRITE = 8'h01;
  parameter FDCST_ERROR = 8'h01;

`ifdef UART_CPM
// for unimon z80 and CP/M Z80
  wire [7:0] REG_CONSTA = {5'b00000, tx_ready, 1'b0, rx_data_ready};
`elsif UART_8251
// for unimon 8251 and SBC8080
  wire [7:0] REG_CONSTA = {6'b000000, rx_data_ready, tx_ready};
`endif

  wire [7:0] REG_CONDAT = rx_data;

  reg [7:0] REG_FDCD;
  reg [7:0] REG_FDCT;
  reg [7:0] REG_FDCS;
  reg [7:0] REG_FDCOP;
  wire [7:0] REG_FDCST  = 0; // not implemented
  reg [7:0] REG_DMAL;
  reg [7:0] REG_DMAH;
  
  reg [7:0]	 mem[65535:0];
  reg [15:0]	 address; // address or data of memory should be latched to infer BSRAM
  wire [7:0]	 io_addr;
  wire [7:0]	 io_data;

  wire		 BUSREQ_n;
  
  reg [7:0]	 tx_data;
  reg		 tx_send;
  wire		 tx_ready;
  wire [7:0]	 rx_data;
  wire		 rx_data_ready;
  reg		 rx_clear;
  
//---------------------------------------------------------------------------
// clock for 8080
//---------------------------------------------------------------------------
`ifdef CLK_3MHz
  wire	    mother_clk = sys_clk;
  parameter  clk1_table = 9'b110000000;
  parameter  clk2_table = 9'b000111100;
  parameter  MSB_CLK    = 8;
`else
  parameter  clk1_table = 13'b1110000000000;
  parameter  clk2_table = 13'b0001111111000;
  parameter  MSB_CLK    = 12;
  reg [1:0]  clk_cnt = 0;
  always @(posedge sys_clk)
    clk_cnt <= clk_cnt + 1'b1;
`endif // CLK_3MHz

`ifdef CLK_2MHz
  wire	     mother_clk = sys_clk;
`elsif CLK_1MHz
  wire	     mother_clk = clk_cnt[0];
`elsif CLK_500kHz
  wire	     mother_clk = clk_cnt[1];
`endif // CLK_2MHz or CLK_1MHz or CLK_500kHz


  reg [MSB_CLK:0] clk1_reg;
  reg [MSB_CLK:0] clk2_reg;
  assign CLK1 = clk1_reg[0];
  assign CLK2 = clk2_reg[0];
  always @(posedge mother_clk)
    if( negedge_RESET_n | (clk1_reg == 0)) begin
       clk1_reg <= clk1_table;
       clk2_reg <= clk2_table;
    end
    else begin
       clk1_reg[MSB_CLK:0] <= {clk1_reg[(MSB_CLK-1):0], clk1_reg[MSB_CLK]};
       clk2_reg[MSB_CLK:0] <= {clk2_reg[(MSB_CLK-1):0], clk2_reg[MSB_CLK]};
    end

  // To compensate for delay by external clock driver
  reg CLK1_d; // delayed CLK1
  reg CLK2_d; // delayed CLK2
//  always @(posedge sys_clk) begin
  always @(posedge sys_clk) begin
     CLK1_d <= CLK1;
     CLK2_d <= CLK2;
  end
  
  wire negedge_RESET_n = last_RESET_n & ~RESET_n;
  reg  last_RESET_n = 1'b1;
  always @(posedge mother_clk)
    last_RESET_n <= RESET_n;
  
//---------------------------------------------------------------------------
// reset button and power on reset
//---------------------------------------------------------------------------
  assign RESET = ~RESET_n;
  wire reset_sw = sw1 | sw2;

  // reset for CPU and UART
  reg  RESET_n;
  reg [27:0] reset_cnt = 0;
  parameter  RESET_WIDTH     = (SYSCLK_FRQ / 1000) * 500; // 500ms
  always @(posedge sys_clk)
    if( reset_sw )
       {RESET_n,     reset_cnt    } <= 0;
    else if (reset_cnt != RESET_WIDTH) begin
       RESET_n <= 0;
       reset_cnt <= reset_cnt + 1'd1;
    end
    else
      RESET_n <= 1;

  // reset for SD memory
  // It will take max 1sec after reset to start up SD memory 
  reg		 RESET_SD_n;
  reg [27:0]	 reset_sd_cnt = 0;
  parameter	 RESET_SD_WIDTH  = (SYSCLK_FRQ / 1000) * 50; // 50ms
  always @(posedge sys_clk)
    if( reset_sw )
      {RESET_SD_n,  reset_sd_cnt } <= 0;
    else if (reset_sd_cnt != RESET_SD_WIDTH) begin
       RESET_SD_n <= 0;
       reset_sd_cnt <= reset_sd_cnt + 1'd1;
    end
    else
	 RESET_SD_n <= 1;
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

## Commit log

2023-06-25 Z80 application added
    [TangNanoZ80MEM-B_Cu.gbr, TangNanoZ80MEM-B_Mask.gbr, TangNanoZ80MEM-B_Paste.gbr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]
2023-06-26 application updated
    [TangNanoZ80MEM-B_Cu.gbr, TangNanoZ80MEM-B_Mask.gbr, TangNanoZ80MEM-B_Paste.gbr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]
2023-06-28 uart.v updated
2023-07-11 Update TN20K5V rev.1.1 to 1.1a
    [TangNano5V-B_Cu.gbr, TangNano5V-B_Mask.gbr, TangNano5V-B_Paste.gbr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]
2023-07-11 9K version released
    [TangNano9K5V-B_Cu.gbr, TangNano9K5V-B_Mask.gbr, TangNano9K5V-B_Paste.gbr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]
2023-07-19 6809MEM added
    [TangNano6809MEM-B_Cu.gbr, TangNano6809MEM-B_Mask.gbr, TangNano6809MEM-B_Paste.gbr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]
2023-07-23 TangNano8070MEM added
    [TangNano8070MEM.kicad_sch, device.cfg]
2024-04-07 uart.v bug fixed
    [device.cfg]
2024-04-21 update for 9k rev3.0
    [TangNano9K5V-B_Cu.gbr, TangNano9K5V-B_Mask.gbr, TangNano9K5V-B_Paste.gbr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]
2024-04-26 TangNanoZ80MEM updated
    [device.cfg]
2024-06-21 uart.v.20240621 added
2024-07-22 README updated
    [TangNanoZ80MEM.kicad_sch, device.cfg]
2024-07-23 Z80MEM-CPM uploaded
    [device.cfg]
2024-08-05 8008MEM uploaded
    [TangNano8008MEM.kicad_pcb, TangNano8008MEM.kicad_sch, device.cfg]
2024-08-28 PCB for 8008 updated
    [TangNano8008MEM-B_Cu.gbr, TangNano8008MEM-B_Mask.gbr, TangNano8008MEM-B_Paste.gbr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]
2024-09-08 TangNano8080MEM uploaded
    [TangNano8080MEM-B_Cu.gbr, TangNano8080MEM-B_Mask.gbr, TangNano8080MEM-B_Paste.gbr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]
2025-09-26 impl folders removed
    [device.cfg]
